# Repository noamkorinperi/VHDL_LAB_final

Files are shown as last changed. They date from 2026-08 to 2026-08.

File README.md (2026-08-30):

# VHDL_LAB_final

RV32IM single-cycle MCU implemented in VHDL for the Terasic DE10-Standard
FPGA board.

> ## ⚠️ לשותף לפרויקט: לפני אימות על הכרטיס
>
> יש לעבוד לפי
> **[חשוב — הוראות אימות פיזי על הכרטיס](חשוב_הוראות_אימות_פיזי_על_הכרטיס.md)**.
> השינויים בענף זה עדיין לא אומתו פיזית ואין להסתמך על תוצאות הכרטיס של
> `main`.

## Validation status of this branch

The forum-compliance changes pass the complete automated ModelSim regression,
Quartus Full Compilation, and fully constrained TimeQuest analysis.

**They have not yet been programmed onto or physically validated on a
DE10-Standard board.** The reset, compare, PWM, DIV and REM board results
recorded on `main` apply to the `main` image only and must not be treated as
physical evidence for this branch.

See `DOC/FORUM_COMPLIANCE_STATUS.md` for the forum-question audit and
`חשוב_הוראות_אימות_פיזי_על_הכרטיס.md` for the exact DE10-Standard physical
validation procedure and evidence gate.

## Project navigation

- `PROJECT_PLAN.md` — timestamped roadmap and current status.
- `DUT/RV32IMscMCU` — active VHDL implementation.
- `TB/RV32IMscMCU` — self-checking testbenches.
- `SIM/RV32IMscMCU` — ModelSim scripts and memory images.
- `Quartus/RV32IMscMCU` — Quartus project for Cyclone V.
- `DOC/MODELSIM_TESTS_STAGE0_TO_STAGE3.md` — test instructions.
- `DOC/MODELSIM_TESTS_STAGE4_TO_STAGE5.md` — current GUI test instructions.
- `DOC/PHYSICAL_LAB_TEST_STAGE5_5.md` — historical stage-5.5 smoke procedure.
- `חשוב_הוראות_אימות_פיזי_על_הכרטיס.md` — current branch physical
  validation procedure and evidence template.
- `DOC/MODELSIM_TESTS_STAGE6_TO_STAGE7.md` — interrupt test instructions.
- `DOC/MODELSIM_TESTS_STAGE8.md` — full benchmark matrix, assertions and IPC.
- `DOC/QUARTUS_FPGA_STAGE9.md` — final Quartus build and board procedure.
- `DOC/FORUM_COMPLIANCE_STATUS.md` — forum compliance matrix and branch gate.
- `SIM/RV32IMscMCU/run_stage8_full_verification.do` — unified stages 0–8
  system regression for all nine supplied applications.
- `Quartus/RV32IMscMCU/compile_stage9.cmd` — reproducible full FPGA build.
- `SIM/RV32IMscMCU/run_stage5_5_smoke_firmware.do` — retained stage-5.5
  regression for the earlier smoke firmware.
- `DOC/CPU_IMMEDIATE_DECODE_FIX_2026-08-13.md` — documented LUI/load decode fix.
- `Benchmark apps` — instructor-provided application benchmarks.

Generated Quartus and ModelSim artifacts are intentionally excluded through
`.gitignore`.

## Final Quartus build

The final timing-qualified FPGA implementation was compiled with Quartus Prime 21.1 using Fitter Seed = 2. The setting is stored in Quartus/RV32IMscMCU/RV32IMscMCU.qsf.

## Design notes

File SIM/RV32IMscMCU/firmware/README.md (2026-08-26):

# Stage 8 firmware compatibility copy

`interrupt_test1_ITCM_fixed.hex` is a one-word corrected copy of the instructor's
`Intrrupt-based IO/test1` ITCM image.  The supplied program uses `j STATE1` when
`SW0=0`, which skips `ori gp,gp,1` and therefore never enables interrupts in the
short ModelSim mode.

The word at ITCM word address `0x2F` was changed from `0x01C0006F`
(`j STATE1`) to `0x00C0006F` (jump to the interrupt-enable instruction).  Its
Intel HEX checksum changed accordingly from `9D` to `9E`.  The instructor's
benchmark directory is intentionally left unchanged.

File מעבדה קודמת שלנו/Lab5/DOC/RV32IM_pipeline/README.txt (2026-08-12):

# RV32IM Pipelined RISC-V Core

This repository contains a VHDL implementation of a **5-stage pipelined RISC-V processor** based on the RV32I datapath, with an added partial M-extension path for the `mul` instruction.  
The design is intended for simulation in ModelSim and synthesis/debug on an Intel/Altera FPGA using Quartus and SignalTap.

## Project Overview

The processor is organized as a classic 5-stage pipeline:

```text
IF  ->  ID  ->  EX  ->  MEM  ->  WB
```

Main features:

- 32-bit RISC-V datapath.
- 5-stage pipeline with dedicated pipeline registers.
- Instruction memory / data memory implemented using Intel/Altera `altsyncram`.
- Hazard handling using stall, flush, and forwarding logic.
- Branch and jump redirection support.
- Two-stage adapted multiplier for `mul`.
- Debug outputs for SignalTap, including PC/instruction taps for pipeline stages.
- FPGA top wrapper with board-level switch and LED mapping.

## Top-Level Entities

| Entity | File | Purpose |
|---|---|---|
| `RV32IM_pipeline_top` | `RV32IM_pipeline_top(1).vhd` | FPGA board-level wrapper around the pipelined core. Maps switches, LEDs, and debug outputs. |
| `RV32IM_PIPELINE_CORE` | `RV32IM_PIPELINE_CORE_start(3).vhd` | Main pipelined CPU core. Instantiates IF, ID, EX, MEM, WB stages and hazard units. |
| `Ifetch` | `IFETCH_pipeline(3).VHD` | Program counter logic and instruction memory interface. |
| `Idecode` | `IDECODE_pipeline(1).VHD` | Register file read/write and immediate generation. |
| `control` | `CONTROL(5).VHD` | Combinational instruction decoder and control-signal generator. |
| `Execute` | `EXECUTE(4).VHD` | ALU, branch comparison, and branch/jump target generation. |
| `dmemory` | `DMEMORY(6).VHD` | Data memory interface using `altsyncram`. |
| `IF_ID_REG` | `IF_ID_REG(2).vhd` | Pipeline register between IF and ID. |
| `ID_EX_REG` | `ID_EX_REG(2).vhd` | Pipeline register between ID and EX. |
| `EX_MEM_REG` | `EX_MEM_REG(2).vhd` | Pipeline register between EX and MEM. |
| `MEM_WB_REG` | `MEM_WB_REG(2).vhd` | Pipeline register between MEM and WB. |
| `forwarding_unit` | `forwarding_unit(4).vhd` | Resolves data hazards by selecting forwarded operands. |
| `stall_unit` | `stall_unit(7).vhd` | Inserts a one-cycle stall for load-use and mul-use hazards. |
| `pipeline_muxes` | `pipeline_muxes(3).vhd` | Forwarding muxes and write-back mux. |
| `Multiplier16_s1`, `Multiplier16_s2` | `Multiplier16_adapted_simple(2).vhd` | Two-stage multiplier implementation. |
| `PLL` | `PLL(5).vhd` | FPGA PLL used when running on hardware. |

## Packages

| Package | File | Purpose |
|---|---|---|
| `cond_compilation_package` | `cond_compilation_package(5).vhd` | Global configuration constants for simulation/FPGA mode, memory size, PC width, address width, and PLL parameters. |
| `const_package` | `const_package(5).vhd` | Instruction masks, opcode constants, ALU operation encodings, and shared datapath constants. |
| `aux_package` | `aux_package_pipeline(1).vhd` | Component declarations for the pipelined core and its submodules. Compile only this updated `aux_package`; do not compile an older `aux_package.vhd` in the same library. |

## Pipeline Architecture

### IF Stage

The IF stage is implemented by `Ifetch` and includes:

- Program counter register.
- Sequential PC update using `PC + 4`.
- Branch/jump target selection.
- PC hold support during stalls using `PCWrite_i`.
- Instruction memory access through `altsyncram`.

The next-PC priority is:

```text
reset -> jalr -> taken branch / jal -> stall hold -> PC + 4
```

### ID Stage

The ID stage contains:

- Register file with 32 registers.
- Source register decoding from the instruction.
- Immediate/sign-extension generation.
- Write-back input path from the WB stage.

The register file write-back is driven by:

```text
wb_rd_i, wb_write_data_i, wb_regwrite_i
```

### EX Stage

The EX stage contains:

- ALU operation execution.
- Branch comparison.
- Branch/jump target address generation.
- Stage 1 of the adapted multiplier.

ALU operation selection is controlled by `ALUOp_ctrl_o` from the control unit.

### MEM Stage

The MEM stage contains:

- Data memory read/write.
- Stage 2 of the adapted multiplier.
- Branch/jump resolution and pipeline flush generation.

Data memory address selection depends on `WORD_GRANULARITY`:

```text
WORD_GRANULARITY = true  -> use word address bits
WORD_GRANULARITY = false -> use byte address bits
```

### WB Stage

The WB stage chooses the value written back to the register file:

```text
jal/jalr   -> PC + 4
load       -> DTCM read data
mul        -> multiplier result
otherwise  -> ALU result
```

## Hazard Handling

### Forwarding

The `forwarding_unit` detects dependencies between the current EX-stage instruction and results from later stages.

Forwarding select encoding:

```text
00 -> use original ID/EX register data
10 -> forward from EX/MEM ALU result
01 -> forward from MEM/WB write-back result
11 -> unused / treated as original data
```

### Stalling

The `stall_unit` inserts a one-cycle interlock when the instruction in ID depends on a value that is not ready yet:

- Load-use hazard.
- Mul-use hazard.

When a stall is asserted:

```text
PCwrite_o   = 0
IFIDWrite_o = 0
Stall_o     = 1
```

### Flushing

A flush is generated after a taken branch or jump redirection. The design exposes `FHCNT_o`, a flush counter useful for debugging and performance inspection.

## Supported Instruction Groups

The control unit decodes the following RV32I-style instruction groups:

- Arithmetic and logical R-type instructions: `add`, `sub`, `and`, `or`, `xor`, `sll`, `srl`, `sra`, `slt`, `sltu`.
- Immediate arithmetic/logical instructions: `addi`, `andi`, `ori`, `xori`, `slli`, `srli`, `srai`, `slti`, `sltiu`.
- Upper-immediate instructions: `lui`, `auipc`.
- Branch instructions: `beq`, `bne`, `blt`, `bge`, `bltu`, `bgeu`.
- Jump instructions: `jal`, `jalr`.
- Load/store instructions: `lb`, `lh`, `lw`, `lbu`, `lhu`, `lwu`, `sb`, `sh`, `sw`.
- M-extension: `mul` through the adapted two-stage multiplier.

> Note: `const_package` contains constants for additional M-extension and system instructions, but the uploaded control/datapath currently wires the `mul` path only.

## Multiplier Implementation

The `mul` instruction is implemented using a two-stage adapted multiplier:

```text
Stage 1, EX stage:
    Four 8-bit partial multiplications
    P = {P3, P2, P1, P0}

Pipeline register:
    EX/MEM register stores the packed partial products

Stage 2, MEM stage:
    Adder tree combines the partial products
    RESULT = P0 + (P1 + P2 << 8) + (P3 << 16)
```

Because the multiplier result becomes available in MEM/WB, a directly dependent instruction after `mul` requires one stall, similar to a load-use hazard.

## Debug and SignalTap Outputs

The core exposes several useful debug outputs:

| Signal | Meaning |
|---|---|
| `pc_o` | Current IF-stage PC. |
| `instruction_o` | Current IF-stage instruction. |
| `IDpc_o`, `EXpc_o`, `MEMpc_o`, `WBpc_o` | PC value in each pipeline stage. |
| `IDinstruction_o`, `EXinstruction_o`, `MEMinstruction_o`, `WBinstruction_o` | Instruction value in each pipeline stage. |
| `STCNT_o` | Stall counter. |
| `FHCNT_o` | Flush counter. |
| `CLKCNT_o` / `mclk_cnt_o` | Main clock counter. |
| `STRIGGER_o` | SignalTap trigger when the IF PC matches the selected breakpoint address. |
| `BPADDR_i` | 8-bit breakpoint address input, normally driven by `SW[7:0]`. |

In the FPGA wrapper:

```text
SW[7:0]     -> BPADDR_i
LEDR[7:0]   -> low byte of stall counter
LEDR[8]     -> breakpoint trigger
LEDR[9]     -> flush activity indicator
```

## Build Configuration

The main configuration constants are located in `cond_compilation_package(5).vhd`.

Important parameters:

| Constant | Meaning |
|---|---|
| `G_MODELSIM` | `1` for ModelSim-style simulation, `0` for FPGA build. |
| `G_WORD_GRANULARITY` | Selects word-addressed or byte-addressed memory behavior. |
| `G_ADDRWIDTH` | ITCM/DTCM memory address width. |
| `G_DATA_WORDSNUM` | Number of memory words. |
| `G_PC_WIDTH` | Program counter width. |
| `G_MA_WIDTH` | Memory address width used by the datapath. |
| `G_PLL_DIV`, `G_PLL_MUL` | PLL configuration parameters used in FPGA mode. |

In the uploaded package, `G_MODELSIM` is set to `1`.  
For FPGA synthesis, set/override `MODELSIM = 0` so that the PLL path and FPGA reset polarity are used.

## Memory Initialization

Both instruction memory and data memory are initialized from `.hex` files:

- ITCM initialization is defined in `IFETCH_pipeline(3).VHD`.
- DTCM initialization is defined in `DMEMORY(6).VHD`.

The uploaded files currently contain absolute Windows paths, for example:

```text
C:\Users\ASUS\Desktop\Computers_LAB\Lab5\Material\Benchmark_Apps\test4\RV32IM\man_compiled\bin\M9K-intel\ITCM.hex
C:\Users\ASUS\Desktop\Computers_LAB\Lab5\Material\Benchmark_Apps\test4\RV32IM\man_compiled\bin\M9K-intel\DTCM.hex
```

Before running the project on another computer, update these paths or move the `.hex` files into the project directory and use relative paths.

## Suggested Compilation Order

A safe compilation order is:

```tcl
vlib work
vmap work work

vcom "cond_compilation_package(5).vhd"
vcom "const_package(5).vhd"
vcom "aux_package_pipeline(1).vhd"

vcom "PLL(5).vhd"
vcom "CONTROL(5).VHD"
vcom "IFETCH_pipeline(3).VHD"
vcom "IDECODE_pipeline(1).VHD"
vcom "EXECUTE(4).VHD"
vcom "DMEMORY(6).VHD"

vcom "IF_ID_REG(2).vhd"
vcom "ID_EX_REG(2).vhd"
vcom "EX_MEM_REG(2).vhd"
vcom "MEM_WB_REG(2).vhd"

vcom "forwarding_unit(4).vhd"
vcom "stall_unit(7).vhd"
vcom "pipeline_muxes(3).vhd"
vcom "Multiplier16_adapted_simple(2).vhd"

vcom "RV32IM_PIPELINE_CORE_start(3).vhd"
vcom "RV32IM_pipeline_top(1).vhd"
```

For ModelSim, make sure the Intel/Altera `altera_mf` simulation library is available because `IFETCH_pipeline` and `DMEMORY` instantiate `altsyncram`.

## FPGA Usage Notes

For FPGA implementation:

1. Set the top-level entity to:

```text
RV32IM_pipeline_top
```

2. Map board pins in the Quartus `.qsf` file:

```text
clk_i  -> CLOCK_50
rst_i  -> KEY0, active-low on the board wrapper comments
SW     -> SW7..SW0
LEDR   -> LEDR9..LEDR0
```

3. Use SignalTap to observe:

```text
pc_o, instruction_o,
IDpc_o, EXpc_o, MEMpc_o, WBpc_o,
IDinstruction_o, EXinstruction_o, MEMinstruction_o, WBinstruction_o,
STCNT_o, FHCNT_o, CLKCNT_o, STRIGGER_o
```

## Repository File List

```text
aux_package_pipeline(1).vhd
cond_compilation_package(5).vhd
const_package(5).vhd
CONTROL(5).VHD
DMEMORY(6).VHD
EX_MEM_REG(2).vhd
EXECUTE(4).VHD
forwarding_unit(4).vhd
ID_EX_REG(2).vhd
IDECODE_pipeline(1).VHD
IF_ID_REG(2).vhd
IFETCH_pipeline(3).VHD
MEM_WB_REG(2).vhd
Multiplier16_adapted_simple(2).vhd
pipeline_muxes(3).vhd
PLL(5).vhd
RV32IM_PIPELINE_CORE_start(3).vhd
RV32IM_pipeline_top(1).vhd
stall_unit(7).vhd
```

## Notes and Limitations

- This package does not include a testbench file.
- The design depends on Intel/Altera `altsyncram`, so pure generic VHDL simulators may require vendor libraries or memory-model replacements.
- The uploaded memory initialization paths are machine-specific and should be changed before reuse.
- The M-extension datapath currently supports the uploaded `mul` implementation. Other M-extension constants exist in the package but are not fully integrated in the current control/datapath.
- File names contain copy suffixes such as `(1)`, `(2)`, etc. The VHDL entity names are unaffected, but for a clean repository it is recommended to rename files to stable names without copy suffixes.

## Recommended Clean File Names

For a cleaner Git repository, the files can be renamed as follows:

```text
aux_package_pipeline.vhd
cond_compilation_package.vhd
const_package.vhd
CONTROL.vhd
DMEMORY.vhd
EX_MEM_REG.vhd
EXECUTE.vhd
forwarding_unit.vhd
ID_EX_REG.vhd
IDECODE_pipeline.vhd
IF_ID_REG.vhd
IFETCH_pipeline.vhd
MEM_WB_REG.vhd
Multiplier16_adapted_simple.vhd
pipeline_muxes.vhd
PLL.vhd
RV32IM_PIPELINE_CORE.vhd
RV32IM_pipeline_top.vhd
stall_unit.vhd
```

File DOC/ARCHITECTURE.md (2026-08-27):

# RV32IMscMCU - Architecture Specification

Status: forum-compliance RTL and automated verification complete, 27.08.2026 IDT.
Physical DE10-Standard validation is still pending for these changes.

Target: Terasic DE10-Standard, Cyclone V SX SoC `5CSXFC6D6F31C6N`.

## Scope

The mandatory design is a structural single-cycle RV32IM MCU.  Pipeline and
UART remain outside the active scope.  The original lab and instructor folders
are immutable references; implementation work is contained in `DUT`, `TB`,
`SIM`, `DOC`, and `Quartus`.

## Top-level architecture

```mermaid
flowchart LR
    CLOCK["CLOCK_50 / KEY0"] --> CRU["Clock + Reset Unit"]
    CRU --> CPU["RV32IM Single-Cycle CPU"]
    CRU --> DIV["32-bit Divider"]
    CPU --> ITCM["ITCM"]
    CPU <--> BUS["32-bit Data Bus"]
    BUS <--> DTCM["DTCM"]
    BUS <--> PERIPH["MMIO Peripheral Mux"]
    PERIPH <--> GPIO["LEDR / HEX / SW"]
    PERIPH <--> PB["Hardware-debounced KEY1-KEY3"]
    PERIPH <--> TIMER["Basic Timer / PWM / Capture"]
    BUS <--> INTC["Interrupt Controller"]
    CPU <--> DIV
    PB --> INTC
    TIMER --> INTC
    INTC -->|"INTR / INTA / TYPE"| CPU
```

The final MCU entity is `RV32IMscMCU`, and both it and the CPU core remain
structural. The CPU exposes one data bus to `mcu_interconnect`; the interconnect
routes DTCM accesses locally and forwards MMIO accesses to `mcu_peripherals`.

## Data-bus contract

The CPU is the only bus master.

| Signal | Width | Direction from CPU | Meaning |
|---|---:|---|---|
| `dbus_addr` | 32 | output | Full byte address; low bits must never be discarded before MMIO decode |
| `DATA BUS` | 32 | bidirectional | CPU write data; DTCM/MMIO read data; TYPE during INTA; non-owners drive `Z` |
| `dbus_read` | 1 | output | Valid load transaction |
| `dbus_write` | 1 | output | Valid store transaction |

Rules:

1. DTCM is selected for byte addresses `0x00000000-0x00001FFF`.
2. MMIO is selected for byte addresses `0x00002000-0x00003FFF`.
3. DTCM receives word index `dbus_addr(12 downto 2)` only after selection.
4. MMIO decode uses the complete address, including bits 1:0.  This is required
   for `HEX0/HEX1`, `HEX2/HEX3`, `HEX4/HEX5`, and `IE/IFG/TYPE`.
5. Provided applications use `lw/sw` even for byte-resolution registers.  MMIO
   writes consume the low byte and reads return zero-extended values.
6. Exactly one source owns the shared DATA BUS; every non-owner drives high impedance.
7. During `INTA`, the interrupt controller drives zero-extended `TYPE` onto DATA BUS.
8. A write may target either DTCM or one peripheral, never both.

## Address map

The canonical VHDL constants are in `mcu_memory_map_pkg.vhd`.

| Region/register | Address | Access |
|---|---:|---|
| DTCM word bases | `0x0000-0x1FFC` | R/W word |
| MMIO region | `0x2000-0x3FFF` | decoded |
| `PORT_LEDR` | `0x2000` | low byte R/W |
| `PORT_HEX0` | `0x2004` | low byte R/W |
| `PORT_HEX1` | `0x2005` | low byte R/W |
| `PORT_HEX2` | `0x2008` | low byte R/W |
| `PORT_HEX3` | `0x2009` | low byte R/W |
| `PORT_HEX4` | `0x200C` | low byte R/W |
| `PORT_HEX5` | `0x200D` | low byte R/W |
| `PORT_SW` | `0x2010` | low byte R |
| `PORT_PB` | `0x2014` | low byte R |
| UART reserved | `0x2018-0x201A` | bonus, inactive |
| `BTCTL1` | `0x201C` | low byte R/W |
| `BTCTL2` | `0x201D` | low byte R/W |
| `BTCMPR0` | `0x2020` | word R/W |
| `BTCMPR1` | `0x2024` | word R/W |
| `BTCAPR` | `0x2028` | word R/W |
| `IE` | `0x202C` | low byte R/W |
| `IFG` | `0x202D` | low byte R/W1C/software clear as defined per source |
| `TYPE` | `0x202E` | low byte R |

## Clock plan

| Domain | Source | Purpose |
|---|---|---|
| `CLOCK_50` | DE10-Standard 50 MHz oscillator | Board reference clock |
| `MCLK` | dedicated Cyclone V PLL instance, 20 MHz | CPU and DTCM |
| `SMCLK` | dedicated Cyclone V PLL instance, 20 MHz | GPIO, timer and interrupt controller |
| `DIVCLK` | dedicated Cyclone V PLL instance, 50 MHz | Divider's 32-cycle iterative datapath |

`RV32IMscMCU.vhd` instantiates three generic `PLL.vhd` wrappers. MCLK and SMCLK
use 2/5 and DIVCLK uses 1/1. Quartus may share phase-identical MCLK/SMCLK
physical clock resources, but the required three logical PLL instances remain
explicit. The MCLK/DIVCLK crossing uses the request/completion toggle handshake.

No fabric-generated clock may be used as a clock input.  Clock selection in the
timer will use clock-enable pulses inside the `sysclk` domain.

## Reset plan

- `KEY0` is the external active-low system reset.
- Internal reset is active-high.
- Assertion may be asynchronous; deassertion must be synchronized separately
  into `sysclk` and `DIVCLK` using two flip-flops.
- The final reset remains asserted until all three Cyclone V PLL instances report lock.
- KEY1-KEY3 are data/interrupt inputs and never participate in system reset.
- The current wrapper asserts reset while KEY0 is pressed or the PLL is not
  locked. Synchronized reset deassertion will be reviewed before stage-5.5
  physical programming.

## Divider handshake and CDC

The CPU launches one request with stable operands and operation metadata.  The
request is converted to a toggle or otherwise lossless handshake in `DIVCLK`.
The divider captures operands once, asserts busy for 32 iterations, registers
quotient/remainder, and returns a synchronized completion event.  The CPU holds
architectural state while busy and performs exactly one write-back after done.
Every multi-bit transfer is held stable for the duration of its handshake; only
single-bit control events pass through two-flop synchronizers.

## Interrupt interface

| Signal | Producer | Consumer | Meaning |
|---|---|---|---|
| `INTR` | interrupt controller | CPU | At least one enabled pending source exists while GIE is set |
| `INTA` | CPU | interrupt controller | CPU is accepting the selected source |
| `TYPE[7:0]` | interrupt controller | CPU data bus | Vector-table byte offset for the highest-priority source |

Priority without UART is RESET, Basic Timer, KEY1, KEY2, KEY3.  UART vector
positions remain reserved.  CPU entry is a two-cycle FSM: capture TYPE and clear
GIE in cycle 1, then store `PC+4` in `tp` and jump through the vector table in
cycle 2.  `jalr zero, 0(tp)` acts as `reti` and restores GIE.

## Planned source boundaries

| Unit | Responsibility |
|---|---|
| `RV32IMscMCU.vhd` | Structural board/MCU top-level only |
| `RV32I_CORE.vhd` | CPU structure and later interrupt/divider stall integration |
| `mcu_memory_map_pkg.vhd` | Canonical addresses and interrupt TYPE values |
| `mcu_interconnect.vhd` | Shared tri-state DATA BUS ownership and DTCM/MMIO selection |
| `gpio_peripheral.vhd` | LED/HEX/SW registers and seven-segment encoding, phase 2 |
| `divider.vhd` | Iterative unsigned core, phase 3 |
| `PLL.vhd` | Generic Cyclone V PLL wrapper and lock indication |
| `basic_timer.vhd` | Timer, compare, PWM and capture, phase 4 |
| `pushbutton_unit.vhd` | Direct board-key state and release-edge event detection |
| `interrupt_controller.vhd` | IE, IFG, TYPE and priority, phase 6 |

## Stage 4–5 implementation

`mcu_peripherals.vhd` is the single MMIO responder connected to the existing
interconnect. It instantiates GPIO, Basic Timer and pushbuttons, then selects one
read value and one `hit` response. This preserves the original CPU bus and the
stage-0–3 simulation harness interface.

The Basic Timer implements `BTCTL1`, `BTCTL2`, `BTCMPR0`, `BTCMPR1` and
read/write `BTCAPR`. `BTCNT` is internal and is exposed only as a debug signal.
Clock selections `/1`, `/2`, `/4` and `/8` are clock-enable pulses in the
`sysclk` domain. Compare 0 resets the up-counter, compare 1 changes PWM duty,
and synchronized capture inputs can latch rising or falling edges. Timer and
button events are one-`sysclk` pulses prepared for the stage-6 controller.

The pushbutton unit treats the board keys as active-low and relies on the
DE10-Standard's hardware Schmitt-trigger/debounce path, as clarified by the
instructor. It adds no software debounce or two-flop key synchronizer. A single
event is emitted on the hardware-debounced release transition (`0` to `1`).
`PORT_PB[2:0]` returns active-high pressed states for KEY1, KEY2 and KEY3.

### Board-observation mapping prepared for stage 5.5

| Board signal | Current function |
|---|---|
| `KEY0` | active-low system reset |
| `KEY1`, `KEY2`, `KEY3` | hardware-debounced pushbuttons / interrupt sources; event on release |
| `SW[7:0]` | GPIO switch port |
| `SW8` | timer `CAPIN1` |
| `SW9` | timer `CAPIN2` |
| `LEDR[7:0]` | GPIO LED register |
| `LEDR8` | direct PWM observation |
| `LEDR9` | high while any hardware-debounced key is pressed |

Physical pin assignments and the dedicated smoke-test firmware remain gated on
the user's ModelSim GUI evidence and belong to stage 5.5.

## Foundation decisions

1. Existing reference folders are read-only.
2. `RV32IMscMCU` is the stable final top-level entity name.
3. The 32-bit address is byte-based throughout the interconnect.
4. DTCM word addressing occurs only at the RAM boundary.
5. UART addresses and vector slots are reserved but inactive.
6. The pipeline implementation is not compiled into the mandatory design.
7. ModelSim and Quartus gates are tracked with timestamped evidence in
   `PROJECT_PLAN.md`.

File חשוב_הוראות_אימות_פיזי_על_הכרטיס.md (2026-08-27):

# חשוב: הוראות אימות פיזי על הכרטיס — ענף forum-compliance

עודכן: 27.08.2026 IDT

מסמך זה הוא נוהל הקבלה הפיזי עבור הענף `codex/forum-compliance` על כרטיס
DE10-Standard. עד שכל סעיפי החובה שלהלן עוברים ומתועדים, הענף נשאר במצב
**טרם אומת פיזית**. תוצאות שנאספו בעבר מ־`main` אינן תחליף להרצה זו.

## 1. ציוד ותנאי פתיחה

- כרטיס Terasic DE10-Standard וספק הכוח שלו.
- כבל USB-Blaster תקין.
- Quartus Prime Lite 21.1.
- סביבת העבודה על הענף `codex/forum-compliance` וללא שינויי RTL מקומיים לא
  מתועדים.
- מומלץ: טלפון לצילום וידאו; oscilloscope או logic analyzer לבדיקת PWM.

אין לחבר probe לנקודה שאינה מיועדת למדידה. בדיקת LEDR8 בעין מספיקה למעבר
הבסיסי; מדידת oscilloscope היא ראיה משופרת.

## 2. רישום גרסה ובניית SOF חדש

משורש המאגר הרץ:

```text
git switch codex/forum-compliance
git pull --ff-only
git status --short --branch
git rev-parse HEAD
```

רשום בדוח הבדיקה את ה־commit המלא. `git status` צריך להראות שאין שינוי בקבצי
הפרויקט; קבצים מקומיים לא־עקובים שאינם חלק מהבנייה מותרים, אך יש לרשום אותם.

מתוך `Quartus/RV32IMscMCU` הרץ:

```text
compile_stage9.cmd
verify_timing_stage9.cmd
```

תנאי מעבר לפני צריבה:

1. `Quartus Prime Full Compilation was successful` ו־0 errors.
2. `Timing Analyzer was successful` ו־0 errors.
3. התכן fully constrained ל־setup ול־hold, וכל ערכי ה־slack הגרועים חיוביים.
4. נוצר קובץ חדש:

   ```text
   Quartus/RV32IMscMCU/output_files/RV32IMscMCU.sof
   ```

ה־SOF משתמש בקושחת `interrupt/test4` המוגדרת ב־top-level. אין להשתמש ב־SOF
ישן מתיקייה אחרת. ערכי utilization או slack עשויים להשתנות מעט בין build
seeds; קריטריון המעבר הוא שאין שגיאות או הפרות תזמון.

## 3. צריבה לכרטיס

1. כבה את הכרטיס, חבר ספק וכבל USB-Blaster, והדלק אותו.
2. פתח את `Quartus/RV32IMscMCU/RV32IMscMCU.qpf`.
3. פתח `Tools > Programmer`.
4. ב־`Hardware Setup` בחר `DE-SoC [USB-1]` או את מופע USB-Blaster של
   הכרטיס.
5. אם שרשרת JTAG מציגה יותר מרכיב אחד, חבר את ה־SOF לשורת ה־FPGA
   `5CSXFC6D6F31C6` (בדרך כלל רכיב 2). אין לתכנת את ה־HPS או flash.
6. הוסף את `output_files/RV32IMscMCU.sof`, סמן `Program/Configure` ולחץ
   `Start`.
7. ודא שההתקדמות מגיעה ל־100% ללא error ושמור צילום של חלון Programmer.

קבע את `SW9:0` לאפס לפני תחילת רצף הבדיקות. הכפתורים פעילים־נמוך פיזית:
`KEY0` הוא reset; ‏`KEY1`–`KEY3` נקראים כמצב לחוץ פעיל־גבוה בתוך ה־MCU.
פעולת הפסיקה של `KEY1`–`KEY3` מתרחשת **בשחרור** הכפתור. בזמן הלחיצה
`LEDR9` דולק, ובשחרור הוא כבה.

## 4. בדיקת אתחול ו־KEY0/reset

1. מיד לאחר הצריבה ודא שכל ששת צגי HEX מציגים `0` ושהתכן אינו תקוע במצב
   לא ידוע.
2. לחץ ושחרר `KEY1` פעם אחת. רק לאחר השחרור הספירה על HEX צריכה להתחיל.
3. לחץ והחזק `KEY0`: הספירה חייבת להיעצר ויציאות ה־GPIO/HEX לחזור לערכי
   reset.
4. שחרר `KEY0` והמתן לנעילת ה־PLL. התוכנה צריכה לעלות מחדש למצב idle עם
   HEX מאופס; הספירה אינה אמורה להתחדש לפני שחרור חדש של `KEY1`.
5. שחרר `KEY1` שוב ואמת שהספירה חוזרת. כשל באתחול מחדש, יציאות `X`/הבהוב
   קבוע או צורך במחזור מתח הם FAIL.

## 5. בדיקת KEY1 ופסיקות compare

לחץ `KEY0` ושחרר כדי להתחיל ממצב ידוע. בצע ארבע לחיצות `KEY1` נפרדות:

1. בכל לחיצה החזק את `KEY1` כחצי שנייה. `LEDR9` צריך לדלוק בזמן ההחזקה,
   והפעולה החדשה אינה אמורה להתחיל לפני השחרור.
2. שחרר את `KEY1`; ‏`LEDR9` צריך לכבות והמונה המוצג ב־HEX צריך להתקדם.
3. מדוד לפחות ארבעה מרווחים בין עדכוני HEX בכל מצב.
4. ארבעת השחרורים צריכים לעבור במחזור בין תקופות compare של בקירוב
   `1.0 s`, ‏`0.5 s`, ‏`0.25 s` ו־`0.125 s` ולחזור על עצמן. סדר נקודת
   הכניסה למחזור תלוי בערך המצב, ולכן תנאי הקבלה הוא הופעת כל ארבע התקופות
   במחזור יציב — לא תקופה ראשונה מסוימת.
5. ודא שכל שחרור משנה מצב פעם אחת בלבד. קפיצה על פני מצב או מספר אירועים
   עבור שחרור יחיד היא FAIL.

בדיקה זו מאמתת מקצה לקצה את קלט KEY1, ‏IE/IFG, ‏TYPE בזמן INTA, חזרה מ־ISR,
ה־Basic Timer והכתיבה לכל זוגות ה־HEX.

## 6. בדיקת KEY2 ו־PWM

לחץ `KEY0` ושחרר, ואז בצע ארבע לחיצות `KEY2` נפרדות:

1. בכל לחיצה ודא ש־`LEDR9` דולק בזמן ההחזקה ושהמעבר מתבצע בשחרור.
2. לאחר השחרור הראשון הספירה ב־HEX נעצרת ו־PWM מופיע ב־`LEDR8`.
3. שחרורים חוזרים של `KEY2` צריכים לשנות את בהירות `LEDR8`; לאחר reset
   רצף ה־duty המתוכנת הוא בקירוב 50%, ‏25%, ‏12.5% ו־6.25%.
4. ודא שאין קיפאון ושכל שחרור מתקבל פעם אחת.
5. אם קיים oscilloscope/logic analyzer, מדוד על יציאת `LEDR8` תדר של
   כ־5 kHz (מחזור כ־200 us), ותעד לפחות שני ערכי duty שונים.
6. לחץ ושחרר `KEY0`; ‏PWM חייב להיפסק והמערכת לחזור ל־idle.

## 7. בדיקת KEY3, ‏REM ו־DIV

קושחת `test4` מודדת זמן ריצה בזיכרון ואינה מציגה את תוצאות המערכים על LED
או HEX. לכן בדיקת הכרטיס מאמתת completion וחזרה תקינה מהפסיקות; נכונות כל
התוצאות המספריות מכוסה ברגרסיית ModelSim.

1. לחץ `KEY0` ושחרר.
2. לחץ והחזק `KEY3`; ודא ש־`LEDR9` דולק. בשחרור הראשון מתחיל מסלול REM.
3. המתן שנייה וודא שהמערכת נשארת מגיבה.
4. לחץ ושחרר `KEY3` פעם שנייה. השחרור השני מפעיל את מסלול DIV.
5. המתן שנייה, ואז לחץ ושחרר `KEY1`. הספירה על HEX חייבת להתחיל ולהמשיך;
   זה מוכיח ששני מסלולי המחלק הסתיימו, ה־ISR חזר וה־CPU לא נשאר ב־stall.
6. חזור על הרצף לאחר reset לפחות פעם נוספת.

אם `KEY1` אינו מפעיל ספירה אחרי שני שחרורי `KEY3`, או שרק מחזור מתח מחזיר
את המערכת, הבדיקה היא FAIL.

## 8. בדיקת רצף משולב

לאחר reset יחיד בצע ללא צריבה מחדש:

```text
KEY1 release -> המתן לשני עדכוני HEX
KEY2 release -> אמת PWM ב-LEDR8
KEY3 release -> המתן
KEY3 release -> המתן
KEY1 release -> אמת שהספירה חוזרת
KEY0 release -> אמת חזרה ל-idle
```

צלם וידאו רציף של הרצף. מטרתו לגלות בעיות state, ‏IFG ישן או חזרה לא תקינה
מ־DIV/REM שאינן נראות כאשר כל תרחיש נבדק בנפרד.

## 9. מה הבדיקה הפיזית אינה מוכיחה לבדה

הבדיקות לעיל נותנות ראיה פיזית להתנהגות החיצונית ולמסלול הפסיקות המלא, אך
אין להסיק מהן לבדן את כל הפרטים הפנימיים:

- שלושת מופעי ה־PLL הלוגיים ומבנה ה־clock domains נבדקים בדוח הסינתזה;
  ה־Fitter רשאי לשתף משאב פיזי עבור MCLK ו־SMCLK הזהים.
- בעלות `Z` על ה־DATA BUS הפנימי הופכת למרבב בתוך ה־FPGA ונבדקת ב־RTL
  ובבדיקת interconnect, לא באמצעות probe חיצוני.
- כתיבה/קריאה של `BTCAPR`, ארבעת ביטי ה־read-only של `BTCTL2`, ניקוי IFG
  כאשר IE כבוי, וסדר retirement של פסיקה שמגיעה באמצע DIV מכוסים בבדיקות
  ModelSim ייעודיות. כדי לטעון שגם הם נבדקו פיזית נדרשת קושחת diagnostic
  נפרדת שמציגה PASS/FAIL על LED/HEX או capture מתאים ב־SignalTap.

אין לסמן את הבדיקות הפנימיות כ־"אומתו פיזית" רק משום שהדגמת `test4` עברה.

## 10. ראיות ודוח תוצאה

צור תיקייה שאינה מחליפה ראיות קודמות, לדוגמה:

```text
DOC/evidence/forum-compliance-YYYYMMDD-HHMM/
```

שמור בה:

1. `validation.txt` לפי התבנית הבאה.
2. צילום Programmer ב־100%.
3. צילום/וידאו reset ואתחול מחדש.
4. וידאו KEY1 המציג ארבעה קצבים.
5. צילום/וידאו KEY2; ואם קיים, צילום scope עם frequency ו־duty.
6. וידאו רצף KEY3, ‏KEY3, ‏KEY1 והמשך ספירה.
7. צילום או קובץ של תוצאות Quartus ו־TimeQuest.

```text
Board: DE10-Standard
Date/time/timezone:
Tester:
Git commit:
Quartus version:
USB-Blaster identifier:
SOF path and build time:

Build + timing: PASS / FAIL
Program 100%: PASS / FAIL
KEY0/reset: PASS / FAIL
KEY1/release + four compare periods: PASS / FAIL
KEY2/PWM: PASS / FAIL
KEY3 REM/DIV + recovery: PASS / FAIL
Combined sequence: PASS / FAIL
Scope measurement (optional): frequency=____ duty=____
Notes:
Overall: PASS / FAIL
```

## 11. שער קבלה

האימות הפיזי של הענף עובר רק כאשר כל שבעת סעיפי החובה בתבנית הם PASS,
ה־commit תואם לענף המרוחק, וכל הראיות נשמרו. לאחר מכן יש לעדכן את
`README.md`, ‏`DOC/FORUM_COMPLIANCE_STATUS.md` ו־`PROJECT_PLAN.md` עם
תאריך, commit, שם הבודק וקישור לראיות. אם סעיף אחד נכשל, משאירים את אזהרת
"טרם אומת פיזית" ומתעדים את הצעד הראשון שבו ההתנהגות סטתה מהצפוי.

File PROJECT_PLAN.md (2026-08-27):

# תוכנית עבודה ומעקב - RV32IM MCU על DE10-Standard

עודכן לאחרונה: 27.08.2026 IDT - התאמות פורום; אימות פיזי לענף החדש ממתין

מסמך זה הוא מקור המעקב השוטף של הפרויקט. מעדכנים אותו בכל מעבר שלב, לאחר בדיקה שעברה, וכאשר מתגלה חסם או שינוי בדרישות.

## תמונת מצב נוכחית

| נושא | מצב |
|---|---|
| כרטיס יעד | DE10-Standard |
| ארכיטקטורת חובה | RV32IM single-cycle MCU |
| זמן עדכון אחרון | 27.08.2026 IDT |
| שלב נוכחי | התאמות forum-compliance הושלמו אוטומטית; אימות כרטיס ממתין |
| הושלם | רגרסיית 9/9, בדיקת פסיקה באמצע DIV, Quartus Full Compilation ו־TimeQuest fully constrained |
| הפעולה הבאה | לצרוב את SOF מהענף ולחזור על בדיקות reset, compare, PWM, DIV ו־REM |
| חסם נוכחי | אין גישה פיזית לכרטיס במהלך הכנת הענף |
| Quartus | 0 errors; TimeQuest 0 warnings; worst setup ‏+0.474 ns ו־worst hold ‏+0.160 ns |
| בונוסים | Pipeline ו-UART מוקפאים עד השלמת כל דרישות החובה |

### מקרא מצבים וחותמות זמן

- `[x | DD.MM.YYYY HH:MM IDT]` הושלם ונבדק בזמן המצוין.
- `[x | אומת DD.MM.YYYY HH:MM IDT]` בוצע קודם, אך זהו זמן האימות הראשון המתועד.
- `[~ | DD.MM.YYYY HH:MM IDT]` התחיל או עודכן כעת.
- `[ ]` טרם התחיל.
- `[! | DD.MM.YYYY HH:MM IDT]` חסום, נדחה או דורש החלטה מאז הזמן המצוין.
- `[- | DD.MM.YYYY HH:MM IDT]` מחוץ להיקף הפעיל מאז הזמן המצוין.

כל שינוי עתידי בסטטוס חייב לכלול תאריך, שעה ואזור זמן. אין לשכתב חותמת
היסטורית: שינוי נוסף מקבל חותמת חדשה ונרשם גם ביומן הביצוע.

## מפת הדרך

| שלב | חבילת עבודה | תוצר מרכזי | מצב |
|---:|---|---|---|
| 0 | סביבת עבודה ו-baseline | ליבת RV32IM הקיימת עוברת ModelSim | `[x | 13.08.2026 14:00 IDT]` |
| 1 | ארכיטקטורת MCU | Top-Level, מפת כתובות וממשקי bus מוגדרים | `[x | 12.08.2026 20:44 IDT]` |
| 2 | GPIO ממופה זיכרון | LEDs, HEX ו-switches עובדים ב-ModelSim | `[x | 13.08.2026 15:04 IDT]` |
| 3 | Divider Accelerator | `DIV/REM` וה-handshake עוברים בדיקות | `[x | 17.08.2026 21:48 IDT]` |
| 4 | Basic Timer | counter, compare, PWM ו-capture עובדים | `[x | 17.08.2026 22:21 IDT]` |
| 5 | Pushbuttons | KEY1-KEY3 מסונכרנים, עוברים debounce ומייצרים אירוע יחיד | `[x | 17.08.2026 22:21 IDT]` |
| 5.5 | בדיקת חומרה מוקדמת | KEY1-KEY3 ו-PWM מודגמים פיזית על DE10-Standard | `[x | 26.08.2026 19:30 IDT]` |
| 6 | Interrupt Controller | IE, IFG, TYPE ותעדוף עובדים | `[x | 26.08.2026 19:30 IDT]` |
| 7 | פסיקות בתוך ה-CPU | כניסה ל-ISR וחזרה ממנו עובדות לפי הפרוטוקול | `[x | 26.08.2026 19:30 IDT]` |
| 8 | אינטגרציה ואימות מלא | benchmarks עוברים מול RARS | `[x | 25.08.2026 22:18 IDT]` |
| 9 | Quartus ו-DE10-Standard | קומפילציה, pin assignment וקובץ SOF | `[x | 26.08.2026 19:30 IDT]` |
| 10 | SignalTap ו-PPA | הוכחת FPGA ודוחות Area/Fmax/Power | `[ ]` |
| 11 | דוח והגשה | `Final_report.pdf` ו-ZIP נקיים לפי המבנה הנדרש | `[ ]` |

---

## יומן ביצוע ושינויים בפועל

### 27.08.2026 IDT - התאמות לפי שאלות ותשובות הפורום

- נוספו שלושה מופעי PLL לוגיים נפרדים: MCLK, SMCLK ו־DIVCLK.
- ה־interconnect הוסב ל־DATA BUS דו־כיווני עם `Z`; ‏TYPE נוהג עליו בזמן INTA.
- אירועי KEY נוצרים בשחרור ללא debounce/synchronizer נוסף, בהתאם להבהרת המדריך.
- IFG נוצר רק כאשר IE פעיל ומתנקה בביטול IE; ‏BTCAPR הוא R/W; בחירת HEX משתמשת ב־A0.
- נוספה בדיקת קבלה לפסיקה שמגיעה באמצע DIV ומאמתת retirement לפני INTA.
- ModelSim, Quartus ו־TimeQuest עברו. השינויים **טרם עברו אימות פיזי**;
  הראיות הפיזיות מ־26.08.2026 שייכות ל־`main` בלבד.

### 26.08.2026 20:02 IDT - אימות release לפני העלאה ל־GitHub

- כל 14 סקריפטי ModelSim של שלבים 0–8 הורצו מחדש ועברו עם סמן PASS ייעודי,
  ללא Failure, ‏Fatal או שגיאת קומפילציה.
- רגרסיית שלב 8 עברה 9/9 benchmarks, כולל רצפי הטיימר המתוקנים ב־test4.
- Full Compilation חדש של שלב 9 עבר עם 0 errors והפיק SOF; בכל ארבע פינות
  TimeQuest התקבל slack חיובי, עם worst setup ‏+2.664 ns ו־worst hold ‏+0.143 ns.
- כל קובצי Intel HEX עברו בדיקת checksum, ולא נמצאו סודות או קבצים גדולים
  חריגים בתוכן המיועד ל־commit.

### 26.08.2026 19:30 IDT - אימות פיזי מלא לשלב 9

- רגרסיית ModelSim המלאה עברה 9/9, כולל רצפי KEY1/KEY2/KEY3 והפעלה מחדש
  של compare mode אחרי מדידות capture.
- תוקנה קושחת הכרטיס כך ש־`BTCLR` נכתב במעבר ל־PWM ובהפעלה מחדש של compare;
  בכך נמנע קיפאון כאשר `BTCNT` כבר עבר את ערך ההשוואה החדש.
- Full Compilation עבר עם 0 errors; worst setup slack ‏+2.664 ns ו־worst hold
  slack ‏+0.143 ns.
- ה־SOF נטען בהצלחה לרכיב FPGA מספר 2 בשרשרת `DE-SoC [USB-1]`.
- `KEY0` reset, ‏`KEY1` compare/count, ‏`KEY2` PWM ו־`KEY3` REM/DIV עברו
  בדיקה פיזית. לאחר שתי לחיצות KEY3 הספירה חזרה בקצב 0.125 שנייה ללא קיפאון.

### 17.08.2026 23:07 IDT - רגרסיה מלאה לאחר שלבים 6–7

- הורצו ברצף כל 13 ה-scripts משלבים 0–7, כולל בדיקת קושחת 5.5.
- התקבלו 13 סמני PASS, ללא `Failure`, ללא שגיאת macro וללא שגיאת קומפילציה.
- בכך אומת שהוספת בקר הפסיקות ו-FSM הכניסה/חזרה לא שברה את ה-baseline,
  GPIO, המחלק, הטיימר או הכפתורים.

### 17.08.2026 23:06 IDT - preflight לקושחת שלב 5.5

- נוסף `tb_stage5_5_smoke_firmware.vhd` שמריץ בסימולציה את אותו קובץ
  `ITCM_stage5_5.hex` ששובץ ב-SOF.
- הבדיקה מאמתת שהקושחה מציגה `C` ב-HEX0, מעבירה את KEY1-KEY3 אל
  LEDR2:0 ומייצרת מעבר PWM לאחר סף `BTCMPR1`.
- נוסף `run_stage5_5_smoke_firmware.do` עם Wave/List, והתקבל
  `STAGE 5.5 SMOKE FIRMWARE PASS`.
- שלב 5.5 נשאר במצב `~`: ה-preflight עבר, אך שער היציאה דורש עדיין צריבה
  ובדיקה על כרטיס DE10-Standard אמיתי.

### 17.08.2026 22:58 IDT - הכנת שלב 5.5 ושלבים 6–7

- הושלמו pin assignments מלאים ל-DE10-Standard ונוספה תוכנת smoke-test
  שמציגה `C` ב-HEX0, מציגה את KEY1-KEY3 ב-LEDR2:0 ומפעילה PWM ב-LEDR8.
- נכתב `DOC/PHYSICAL_LAB_TEST_STAGE5_5.md` עם סדר צריבה, תרחישי reset,
  כפתורים, PWM ורשימת הראיות שיש לשמור.
- Full Compilation הושלם: Map, Fitter ו-Assembler עברו עם 0 errors והופק
  `RV32IMscMCU.sof`.
- בדיקת timing ראשונה ב-25 MHz חשפה setup slack שלילי של ‎-1.370 ns במסלול
  החצי-מחזור אל DTCM. שעון הליבה עודכן ל-20 MHz, בהתאם לקבועי הזמן של
  benchmarks המרצה, ו-debounce עודכן ל-200,000 מחזורים כדי לשמור 10 ms.
- לאחר התיקון כל בדיקות setup/hold עברו; ה-worst setup slack הוא ‎+2.631 ns.
- מומש `interrupt_controller.vhd` עם IE/IFG/TYPE, mask, priority, clear
  אוטומטי לטיימר ו-clear תוכנתי לכפתורים; unit test של שלב 6 עבר.
- נוספה לליבה כניסת פסיקה בשני מחזורים, GIE ב-`gp[0]`, שמירת כתובת החזרה
  ב-`tp`, קפיצה דרך vector table ו-`reti`; benchmark `test2` עם שלושת
  הכפתורים עבר בבדיקת האינטגרציה של שלב 7.
- נכתב `DOC/MODELSIM_TESTS_STAGE6_TO_STAGE7.md`; שלבים 6–7 נשארים במצב `~`
  עד להרצת GUI ושמירת Wave/List/צילום מסך.

### 17.08.2026 22:21 IDT - סגירת שלבים 4–5

- המשתמש דיווח שכל שלוש בדיקות ה-GUI עברו בהצלחה.
- נשמרו צילום מסך, Wave ו-List עבור Basic Timer, Pushbuttons ואינטגרציית
  peripheral/MMIO בתיקיות הראיות המתאימות.
- שלבים 4 ו-5 סומנו `x`; ניתן לעבור לבדיקת החומרה המוקדמת 5.5.

### 17.08.2026 22:13 IDT - אימות סופי לפני checkpoint

- הורצו מחדש על קוד המסירה המדויק כל עשרת scripts של שלבים 0–5.
- התקבלו עשרה סמני PASS, ללא `Failure`, ללא שגיאת קומפילציה וללא כשל assertion.
- `git diff --check` עבר; קובצי העזר הזמניים של קריאת ה-PDF הוסרו ואינם חלק
  מהמאגר.

### 17.08.2026 22:09 IDT - שלבים 4–5 מוכנים לבדיקת GUI

- מומש `basic_timer.vhd` עם BTCTL1/BTCTL2, מונה up-mode, בחירת clock-enable
  של `/1`, ‏`/2`, ‏`/4`, ‏`/8`, compare תקופתי, שני מצבי PWM ו-input capture
  מסונכרן בקצה עולה/יורד.
- מומש `pushbutton_unit.vhd` עבור KEY1-KEY3 active-low: שני שלבי synchronizer,
  debounce של 10 ms ב-25 MHz, מצב לחוץ active-high ואירוע יחיד לכל לחיצה.
- נוסף `mcu_peripherals.vhd` שמאחד את GPIO, הטיימר והכפתורים תחת MMIO mux
  יחיד בלי לשנות את ממשק ה-bus של ה-CPU.
- ה-Top-Level מחבר `SW8/SW9` ל-CAPIN1/CAPIN2, ‏`LEDR8` ל-PWM ו-`LEDR9`
  לחיווי של כל כפתור מסונן; חיבורי האירועים מוכנים לשלב 6.
- נוספו שלושה TBs ושלושה scripts נפרדים עם Wave, List ושמירת List אוטומטית.
- כל שלוש הבדיקות החדשות עברו: `STAGE 4 BASIC TIMER PASS`,
  `STAGE 5 PUSHBUTTONS PASS`, ו-`STAGE 4/5 PERIPHERAL INTEGRATION PASS`.
- רגרסיה אוטומטית מלאה של כל עשר בדיקות שלבים 0–5 עברה.
- Quartus Analysis & Synthesis עבר עם 0 errors ו-8 warnings; אזהרות עומק קובצי
  HEX ואותות debug שאינם נצרכים אינן חוסמות.
- נוסף `DOC/MODELSIM_TESTS_STAGE4_TO_STAGE5.md`. שלבים 4–5 נשארים במצב
  `~` עד שהמשתמש ישמור ראיות GUI; רק אז תיכתב תוכנית המעבדה של שלב 5.5.

### 17.08.2026 21:48 IDT - סגירת שלב 3

- בדיקת `STAGE 3 CPU/DIVIDER INTEGRATION PASS` עברה גם בהרצת ModelSim GUI של המשתמש.
- נשמרו ונוספו ל-Git צילום מסך, Wave ו-List עבור בדיקת האינטגרציה בתיקיית הראיות של שלב 3.
- יחד עם ראיות ה-Divider unit, כל שבע בדיקות שלבים 0–3 עברו ותועדו.
- שלב 3 מסומן כעת הושלם; הפעולה הבאה היא מימוש משולב של שלבים 4 ו-5 ולאחריו בדיקות ModelSim ובדיקת חומרה 5.5.

### 17.08.2026 21:44 IDT - שינוי שמות אות ההחזקה של המחלק

- `stall_w` בליבת המעבד שונה ל-`divider_hold_w`.
- `stall_i` ב-IFETCH ובהצהרת ה-component שונה ל-`divider_hold_i`.
- סקריפט Wave/List והתיעוד עודכנו לשמות החדשים, כך שאין בלבול עם pipeline stall עתידי.
- אינטגרציית CPU/Divider עברה שוב ב-ModelSim לאחר שינוי השמות.
- Quartus Analysis & Synthesis עבר עם 0 errors ו-13 warnings.

### 17.08.2026 21:36 IDT - סינתזה לאחר תיקון ה-stall

- Quartus Analysis & Synthesis עבר על הגרסה הסופית של תיקון ה-Divider.
- תוצאה: 0 errors ו-13 warnings; אלו אותן אזהרות לא חוסמות שתועדו קודם.

### 17.08.2026 21:34 IDT - תיקון stall ואימות אינטגרציית ה-Divider

- בדיקת האינטגרציה נכשלה תחילה ב-782 ns משום שה-PC השתנה בזמן `div_busy`.
- נמצא ש-`IFETCH` שמר את רגיסטר ה-PC בזמן stall, אך כתובת ITCM המשיכה להיגזר מ-`next_pc_w`; לכן ה-decode עבר לפקודה הבאה מוקדם מדי.
- בזמן stall כתובת ITCM נלקחת כעת מ-`pc_q`, ונוסף מצב retire שמשאיר את פקודת ה-DIV עד קצה ה-write-back ומשחרר אותה פעם אחת בלבד.
- התיקון תומך גם בשתי פקודות Divider עוקבות ואינו מאפשר שיגור כפול של אותה פקודה.
- אינטגרציית CPU/Divider עברה ב-20462 ns; לאחר מכן עברו גם כל שש בדיקות הרגרסיה האחרות של שלבים 0–3.
- נוסף `DOC/DIVIDER_STALL_FIX_2026-08-17.md` עם ניתוח התקלה והאימות.
- ראיות ה-GUI של Divider unit נשמרו; נשאר לשמור את ראיות ה-GUI של האינטגרציה המתוקנת.

### 17.08.2026 21:21 IDT - תיקון והרצת Divider unit

- בהרצה הראשונה `const_package.vhd` לא התקמפל משום שהסקריפט לא קימפל קודם את `cond_compilation_package.vhd`.
- סדר הקומפילציה ב-`run_stage3_divider_unit.do` תוקן בהתאם ל-`COMPILE_ORDER.txt` ולסקריפט האינטגרציה.
- הרצת console מלאה עברה עם 0 errors ו-0 warnings והתקבלה ההודעה `STAGE 3 DIVIDER UNIT PASS` ב-5661 ns.
- עדיין נדרשת הרצה חוזרת ב-GUI לשמירת Wave/List, ולאחריה בדיקת CPU/Divider integration.

### 17.08.2026 21:19 IDT - הושלם תיעוד GUI של שלב 2

- נשמרו צילום מסך, Wave ו-List עבור `GPIO/test0` integration.
- נשמרו צילום מסך, Wave ו-List עבור בדיקות `GPIO/test1` ו-`GPIO/test2` עם switches.
- בכך הושלם גם תיעוד הראיות של שלב 2, מעבר להרצות האוטומטיות שכבר עברו.

### 13.08.2026 15:08 IDT - סינתזה חוזרת לאחר תיקוני ה-CPU

- Quartus Prime Lite 21.1 Analysis & Synthesis עבר לאחר תיקוני LUI/load.
- תוצאה: 0 errors ו-13 warnings; לא נוספה אזהרה חדשה שחוסמת את התכנון.
- נשמר אותו פרופיל חומרה צפוי: PLL אחד, 4 DSP ו-64 מקטעי RAM.

### 13.08.2026 15:04 IDT - תיקון פענוח immediate וסגירת שלב 2

- בדיקת `GPIO/test0` נכשלה תחילה משום שהמעבד יצר `0x0000/4/5/...` במקום `0x2000/4/5/...`.
- נמצא שקבוע U-type מקורי שימש גם כמסכה וגם כ-opcode מדויק; `LUI` קיבל immediate אפס.
- הוגדרו `AUIPC_OPC` ו-`LUI_OPC` בנפרד והפענוח עודכן בשני המקומות.
- בדיקת `test1/test2` חשפה בנוסף ש-load לא קיבל I-immediate; נוסף `LOAD_OPC` לפענוח.
- דגימת ה-bus בשני integration TBs הותאמה לקצה שבו טרנזקציית GPIO מתבצעת.
- רגרסיית שלב 0 עברה ב-6222 ns, ‏GPIO/test0 עבר ב-2462 ns ו-test1/test2 עברו ב-2342 ns.
- נוסף `DOC/CPU_IMMEDIATE_DECODE_FIX_2026-08-13.md` עם ניתוח מלא וראיות.

### 13.08.2026 14:18 IDT - GPIO unit test עבר

- התקבלה ההודעה `STAGE 2 GPIO UNIT PASS` בזמן סימולציה 223 ns.
- נשמרו Wave, ‏List וצילום מסך בתיקיית הראיות של שלב 2.

### 13.08.2026 14:11 IDT - בדיקת interconnect עברה

- התקבלה ההודעה `STAGE 1 INTERCONNECT PASS` בזמן סימולציה 5 ns.
- נשמרו Wave, ‏List וצילום מסך בתיקיית הראיות של שלב 1.

### 13.08.2026 14:05 IDT - שמירת List אוטומטית בבדיקות ModelSim

- כל שבעת קובצי ה-`.do` עודכנו כך שהאותות של Wave מתווספים גם לחלון List.
- כל הרצה שומרת אוטומטית קובץ `*_list.do` באמצעות `write format list`.
- מסמך הבדיקות עודכן עם רשימת שבעת קובצי ה-List הצפויים.

### 13.08.2026 14:00 IDT - שלב 0 עבר ב-ModelSim

- התקבלה ההודעה `STAGE 0 PASS: RV32I/MUL baseline and DTCM regression` בזמן סימולציה 6222 ns.
- נשמרו `stage0_baseline.log`, צילום Wave וקובץ Wave בתיקיית `screenshots/stage 0`.
- אזהרות arithmetic operand מסוג U/X הופיעו רק בזמן 0 ps ולא מנעו PASS.

### 12.08.2026 21:58 IDT - הוכן מסמך העבודה למחר

- נוסף `DOC/TOMORROW_MODELSIM_CHECKLIST.md` עם הכנה מדויקת וסדר שבע ההרצות.
- לכל בדיקה תועדו פקודת ההרצה, הודעת PASS, אותות לבדיקה וקובץ ה-log הצפוי.
- תועדו נוהל עצירה בכשל, טיפול בספריית `altera_mf` ותבנית דיווח מסכמת.

### 12.08.2026 21:53 IDT - נוסף שלב 5.5 לבדיקת חומרה מוקדמת

- נקבע checkpoint פיזי לאחר השלמת בדיקות ModelSim של שלבים 4–5.
- הבדיקה תכסה KEY1-KEY3 מסונכרנים ועם debounce, וכן יציאת PWM מה-Basic Timer.
- שלב 5.5 אינו מחליף את אימות המערכת המלא על הכרטיס בשלבים 9–10.

### 12.08.2026 21:46 IDT - העלאה ל-GitHub

- המאגר המקומי חובר אל `https://github.com/noamkorinperi/VHDL_LAB_final.git`.
- ה-commit הראשוני שנוצר באתר נשמר ומוזג להיסטוריה המקומית ללא מחיקה.
- הענף `main` הועלה בהצלחה והוגדר לעקוב אחרי `origin/main`.
- המאגר מוגדר כ-Public בהתאם לאישור המפורש של המשתמש להעלות את הפרויקט כפי שהוא.

### 12.08.2026 21:37 IDT - הקמת בקרת גרסאות

- אותחל מאגר Git מקומי על הענף `main`.
- עודכן `.gitignore` כך שתוצרי Quartus ו-ModelSim לא ייכנסו להיסטוריה.
- הוכן checkpoint ראשון בשם `Stage 3 implementation ready for ModelSim`.
- נוסף `README.md` לניווט מהיר בפרויקט ובתיעוד.

### 12.08.2026 21:32 IDT - כיסוי GPIO/test1 ו-GPIO/test2

- נוספו עותקים ייעודיים של קובצי הזיכרון עבור `GPIO/test1` ו-`GPIO/test2`.
- נוספו TB ו-script שמריצים את שני ה-benchmarks במקביל, מגרים את SW0 ובודקים כתיבות LEDR/HEX.
- שלב 2 מוכן כעת לבדיקת כל שלושת ה-benchmarks שסופקו, בלי החלפת קבצים ידנית.

### 12.08.2026 21:30 IDT - Quartus סופי לאחר סנכרון הממשקים

- Analysis & Synthesis חוזר עבר עם 0 errors ו-13 warnings לאחר עדכון כל הצהרות ה-components.
- דוח הסיום מאשר 1,666 registers, ‏131,072 block-memory bits, ‏4 DSP blocks ו-PLL אחד.
- לא נמצאו בדוח אזהרות latch, multiple constant drivers או combinational loop.

### 12.08.2026 21:28 IDT - בדיקה נפרדת לשלב 1

- נוספו `tb_stage1_interconnect.vhd` ו-`run_stage1_interconnect.do` כדי שלכל שלב 0–3 תהיה בדיקה עצמאית.
- הבדיקה מכסה DTCM word addressing, שמירת כתובת MMIO מלאה, read mux, write isolation וכתובת unmapped.

### 12.08.2026 21:25 IDT - שלבים 2–3 מוכנים לבדיקה

- ה-CPU הוסב ל-data bus חיצוני ונוספו `mcu_interconnect` ו-`gpio_peripheral`.
- מומשו LEDR, ששת ה-HEX, encoder active-low וקריאת SW עם zero extension.
- מומשו `divider_unsigned` ו-`divider_accelerator` עבור `DIV/DIVU/REM/REMU`, כולל מקרי קצה ו-CDC.
- נוספו stall ל-IFETCH ומדיניות write-back יחיד בפולס `done`.
- ה-top עודכן ל-sysclk של 25 MHz ול-DIVCLK של 50 MHz באמצעות PLL ל-Cyclone V.
- נוספו חמישה testbenches וחמישה scripts עצמאיים של ModelSim, וכן הוראות הרצה ב-`DOC/MODELSIM_TESTS_STAGE0_TO_STAGE3.md`.
- Quartus Analysis & Synthesis עבר על המימוש המשולב עם 0 errors ו-13 warnings: 1,666 registers, ‏131,072 memory bits, ‏4 DSP ו-PLL אחד.
- בדיקות ModelSim עצמן לא הורצו, בהתאם לבקשת המשתמש; לכן שלבים 2–3 מסומנים "מוכן לבדיקה" ולא "עבר".

### 12.08.2026 20:59 IDT - מדיניות חותמות זמן

- פורמט הסטטוס שונה כך שכל השלמה, דחייה או התחלת עבודה כוללת תאריך ושעה.
- פעולות היסטוריות שזמן יצירת הקובץ שלהן ידוע קיבלו את הזמן המתועד בפועל.
- פעולות שקדמו למעקב הקבצים סומנו באמצעות `אומת`, כדי לא להציג זמן ביצוע מומצא.

### 12.08.2026 20:44 IDT - סגירת תיעוד שלב 1

- נוצר `DOC/PHASE_1_STATUS.md`.
- שלב 1 סומן כמוכן לאחר בדיקת התוצרים ודוח Quartus.
- משימות ModelSim של שלב 0 סומנו כנדחות לבקשת המשתמש.

### 12.08.2026 20:42 IDT - Quartus Analysis & Synthesis

- Analysis & Synthesis הסתיים בהצלחה עם 0 errors.
- נשמרו `RV32IMscMCU.map.rpt` ו-`RV32IMscMCU.map.summary`.
- ה-warnings סווגו ותועדו; לא נמצא כשל elaboration או שגיאת VHDL.

### 12.08.2026 20:34 IDT - ארכיטקטורה ושלד Quartus

- נוספו `mcu_memory_map_pkg.vhd`, ‏`RV32IMscMCU.vhd` ו-`COMPILE_ORDER.txt`.
- נוצרו `DOC/ARCHITECTURE.md` וקובצי `.qpf/.qsf/.sdc`.
- נקבעו Top-Level, מפת הכתובות, ממשק ה-bus ותוכנית clocks/reset.

### 12.08.2026 20:31 IDT - ניידות זיכרונות

- נתיבי `ITCM.hex` ו-`DTCM.hex` המוחלטים הוחלפו ב-generics ניידים.
- יעד הזיכרונות עודכן ל-`Cyclone V`.

### 12.08.2026 20:29 IDT - הקמת עץ העבודה

- נוצרו `DUT`, ‏`TB`, ‏`SIM`, ‏`DOC` ו-`Quartus`.
- קובצי ה-single-cycle מ-Lab 5 הועתקו לעץ העבודה בלי לשנות את המקורות.

### 12.08.2026 20:12 IDT - אימות חומרי הקלט

- אומתו מסמך הדרישות, התמלול, קוד המעבדה וה-benchmarks.
- אומתו זוגות `ITCM.hex`/`DTCM.hex` עבור RV32IM, GPIO ופסיקות.
- תועד כרטיס היעד DE10-Standard.

### סיכום השינויים של שלבים 0-1

מצב מקורות:

- תיקיות `מעבדה קודמת שלנו`, `קבצים מהמדריך` ו-`Benchmark apps` נשמרו ללא שינוי.
- עץ העבודה החדש נוצר בתיקיות `DUT`, `TB`, `SIM`, `DOC` ו-`Quartus`.
- בסיס המימוש הפעיל נלקח מגרסת ה-RV32IM single-cycle של Lab 5, ולא מגרסת ה-RV32I המקורית של המנחה.

שינויים בקובצי Lab 5 שהועתקו לעץ העבודה:

| קובץ | שינוי שבוצע כעת |
|---|---|
| `IFETCH.VHD` | הנתיב המוחלט ל-`ITCM.hex` הוחלף ב-generic בשם `INIT_FILE`; משפחת היעד עודכנה ל-`Cyclone V` |
| `DMEMORY.VHD` | הנתיב המוחלט ל-`DTCM.hex` הוחלף ב-generic בשם `INIT_FILE`; משפחת היעד עודכנה ל-`Cyclone V` |
| `RV32I_CORE.vhd` | נוספו `ITCM_INIT_FILE` ו-`DTCM_INIT_FILE` והם מועברים לרכיבי הזיכרון |
| `aux_package.vhd` | הצהרות ה-generics עודכנו בהתאם לנתיבי הזיכרון הניידים |

קובצי DUT חדשים:

- `mcu_memory_map_pkg.vhd` - מקור אמת יחיד לכתובות MMIO ולערכי interrupt TYPE.
- `RV32IMscMCU.vhd` - Top-Level מבני יציב עבור המערכת והכרטיס.
- `COMPILE_ORDER.txt` - סדר קומפילציה מתועד ל-VHDL-2008.

תשתיות חדשות:

- פרויקט Quartus: `RV32IMscMCU.qpf`, `RV32IMscMCU.qsf` ו-`RV32IMscMCU.sdc`.
- עותקים מקומיים של `ITCM.hex` ו-`DTCM.hex` עבור SIM ו-Quartus.
- `DOC/ARCHITECTURE.md`, `DOC/PHASE_1_STATUS.md` ו-`DOC/Readme.txt`.
- `.gitignore` עבור תוצרי Quartus, ModelSim ועורכים.

מה הוחרג או נדחה:

- אף קובץ מקור לא נמחק.
- `PLL.vhd` הישן נשאר בעץ ה-DUT אך אינו נכלל בבניית שלב 1, מפני שהוא נוצר עבור Cyclone II.
- שלב 1 משתמש זמנית ב-`CLOCK_50` ישירות; יחידת clock/reset ל-Cyclone V תתווסף לפני שילוב המחלק.
- ה-Top-Level הנוכחי מחזיק את HEX כבויים ומשתמש ב-LEDR עבור observability זמנית; GPIO אמיתי יחליף זאת בשלב 2.
- SW ו-KEY1-KEY3 עדיין אינם מחוברים ללוגיקה פונקציונלית.
- קומפילציה והרצה ב-ModelSim, השוואת RARS ו-waveforms נדחו ליום ModelSim.

אימות שבוצע:

- כתובות ה-MMIO הושוו לקובצי `io_map.s` של ה-benchmarks.
- Quartus Prime Lite 21.1 Analysis & Synthesis עבר עם 0 errors.
- תוצאת synthesis ראשונית: 1,271 registers, ‏131,072 block-memory bits ו-4 DSP blocks.
- ה-warnings שנותרו נבדקו ומתועדים ב-`DOC/PHASE_1_STATUS.md`.

---

## שלב 0 - סביבת עבודה ובדיקת baseline

מטרה: להוכיח שהבסיס מהמעבדה הקודמת תקין לפני שמוסיפים MCU או משנים את המעבד.

- [x | אומת 12.08.2026 20:12 IDT] נאספה ליבת RV32IM single-cycle מהמעבדה הקודמת.
- [x | אומת 12.08.2026 20:12 IDT] נאספו testbenches וקובצי ModelSim `.do`.
- [x | אומת 12.08.2026 20:12 IDT] נאספו benchmark, Assembly וזוגות `ITCM.hex`/`DTCM.hex`.
- [x | אומת 12.08.2026 20:12 IDT] נשמרו בנפרד קוד ה-single-cycle, קוד ה-pipeline וחומר המקור מהמדריך.
- [x | אומת 12.08.2026 20:12 IDT] נקבע כרטיס היעד: DE10-Standard.
- [x | 12.08.2026 20:29 IDT] ליצור עץ עבודה חדש בלי לשנות את חומרי המקור.
- [x | 12.08.2026 20:29 IDT] להעתיק לעץ העבודה רק את קובצי ה-single-cycle הנדרשים.
- [x | 12.08.2026 20:31 IDT] להחליף נתיבי HEX קשיחים במנגנון נייד ומתועד.
- [x | 12.08.2026 20:34 IDT] לקבוע סדר קומפילציה אחיד ל-VHDL-2008.
- [! | 12.08.2026 20:44 IDT] לקמפל את הליבה ואת `tb_RV32IM` ב-ModelSim ללא שגיאות - נדחה ליום ModelSim.
- [! | 12.08.2026 20:44 IDT] להריץ את benchmark ה-RV32IM הידני - נדחה ליום ModelSim.
- [! | 12.08.2026 20:44 IDT] להריץ את גרסת ה-GCC אם היא תואמת לתת-הקבוצה הנתמכת בליבה - נדחה ליום ModelSim.
- [! | 12.08.2026 20:44 IDT] להשוות את תוצאת DTCM לתוצאת RARS - נדחה ליום ModelSim.
- [! | 12.08.2026 20:44 IDT] לשמור log ו-waveform קצרים כהוכחת baseline - נדחה ליום ModelSim.
- [ ] ליצור checkpoint מקומי לפני השינוי הפונקציונלי הראשון.

שער יציאה: הליבה הקיימת מתקמפלת, מסיימת benchmark, ותוצאת הזיכרון תואמת ל-golden model.

## שלב 1 - תכנון ארכיטקטורת ה-MCU

מטרה: לסגור את החיבורים והכתובות לפני כתיבת רכיבים חדשים.

- [x | 12.08.2026 20:34 IDT] להכין תרשים Top-Level מבני של CPU, ITCM, DTCM, GPIO, Divider, Timer ו-Interrupt Controller.
- [x | 12.08.2026 20:34 IDT] להגדיר ממשק data bus אחיד: כתובת, נתוני כתיבה, נתוני קריאה, `MemRead` ו-`MemWrite`.
- [x | 12.08.2026 20:34 IDT] להפריד בין DTCM בטווח `0x0000-0x1FFC` לבין MMIO בטווח `0x2000-0x3FFC`.
- [x | 12.08.2026 20:34 IDT] ליצור package יחיד עבור כתובות MMIO, מסכות וקבועי מערכת.
- [x | 12.08.2026 20:34 IDT] להגדיר byte-addressing עבור רגיסטרים סמוכים כמו `HEX0/HEX1` ו-`IE/IFG/TYPE`.
- [x | 12.08.2026 20:34 IDT] להגדיר read mux ו-address decoder ללא יותר מדרייבר אחד על bus הקריאה.
- [x | 12.08.2026 20:34 IDT] להגדיר clock/reset domains: `CLOCK_50`, שעון ליבה, `DIVCLK`, reset מ-KEY0 ו-PLL lock.
- [x | 12.08.2026 20:34 IDT] להגדיר handshake בין ה-CPU למחלק ואת מדיניות עצירת הליבה בזמן חלוקה.
- [x | 12.08.2026 20:34 IDT] להגדיר ממשק `INTR/INTA` ו-FSM הכניסה לפסיקה.
- [x | 12.08.2026 20:34 IDT] לתעד רוחב, כיוון ופולריות של כל אות Top-Level.
- [x | 12.08.2026 20:34 IDT] ליצור שלד Quartus ראשוני עם `.qpf/.qsf` עבור DE10-Standard לאחר ששמות ה-Top-Level והקבצים יציבים.
- [x | 12.08.2026 20:42 IDT] לבצע Analysis & Synthesis ראשוני ולשמור רשימת warnings לבדיקה.
- [x | 12.08.2026 20:44 IDT] לקבוע שכל milestone פונקציונלי מסתיים גם בבדיקת synthesis, לא רק ב-ModelSim.

### מפת כתובות מחייבת

| רכיב | כתובת | רזולוציה |
|---|---:|---|
| DTCM | `0x0000-0x1FFC` | Word storage, byte address space |
| `PORT_LEDR` | `0x2000` | Byte |
| `PORT_HEX0` | `0x2004` | Byte |
| `PORT_HEX1` | `0x2005` | Byte |
| `PORT_HEX2` | `0x2008` | Byte |
| `PORT_HEX3` | `0x2009` | Byte |
| `PORT_HEX4` | `0x200C` | Byte |
| `PORT_HEX5` | `0x200D` | Byte |
| `PORT_SW` | `0x2010` | Byte |
| `PORT_PB` | `0x2014` | Byte |
| UART bonus | `0x2018-0x201A` | Byte, שמור בלבד כרגע |
| `BTCTL1` | `0x201C` | Byte |
| `BTCTL2` | `0x201D` | Byte |
| `BTCMPR0` | `0x2020` | Word |
| `BTCMPR1` | `0x2024` | Word |
| `BTCAPR` | `0x2028` | Word |
| `IE` | `0x202C` | Byte |
| `IFG` | `0x202D` | Byte |
| `TYPE` | `0x202E` | Byte |

שער יציאה: תרשים, package כתובות, bus specification ותוכנית clocks/resets מאושרים ועקביים עם ה-benchmarks.

## שלב 2 - Memory-Mapped GPIO

מטרה: להריץ תחילה MCU שימושי ללא פסיקות.

- [x | 12.08.2026 21:25 IDT] לממש רגיסטר פלט עבור `LEDR7-LEDR0`.
- [x | 12.08.2026 21:25 IDT] לממש שישה רגיסטרים עבור `HEX0-HEX5`.
- [x | 12.08.2026 21:25 IDT] לממש 7-segment encoder בהתאם לפולריות של DE10-Standard.
- [x | 12.08.2026 21:25 IDT] לממש קריאת `SW7-SW0`.
- [x | 12.08.2026 21:25 IDT] לחבר address decoder ו-read mux ל-DTCM ול-GPIO.
- [x | 12.08.2026 21:25 IDT] להבטיח שכתיבה ל-MMIO אינה כותבת במקביל ל-DTCM.
- [x | 12.08.2026 21:25 IDT] ליצור testbench ממוקד עבור read/write של כל כתובת.
- [! | 12.08.2026 21:32 IDT] להריץ `GPIO/test0`, אחריו `test1` ו-`test2` - נדחה ליום ModelSim; שלושתם מוכנים בבדיקות integration אוטומטיות.
- [x | 12.08.2026 21:25 IDT] לבדוק בתכן את reset מ-KEY0 והתנהגות שמירת ערכי פלט; אימות waveform ממתין ל-ModelSim.

שער יציאה: שלושת benchmarks של GPIO עוברים ב-ModelSim והיציאות תואמות לתוכנית ה-Assembly.

## שלב 3 - Divider Accelerator

מטרה: להשלים את פעולות החלוקה של RV32IM באמצעות מחלק רב-מחזורי.

- [x | 12.08.2026 21:25 IDT] לאשר מתוך ה-benchmark ומפרט RV32M אילו פקודות נדרשות: `DIV`, `DIVU`, `REM`, `REMU`.
- [x | 12.08.2026 21:25 IDT] לממש מחלק unsigned של 32 ביט בשיטת shift/subtract.
- [x | 12.08.2026 21:25 IDT] להפיק quotient ו-remainder לאחר 32 מחזורי `DIVCLK`.
- [x | 12.08.2026 21:25 IDT] להגדיר `start`, `busy`, `done` וטעינת operands חד-פעמית.
- [x | 12.08.2026 21:25 IDT] לטפל בסימן מחוץ לליבת המחלק עבור פעולות signed.
- [x | 12.08.2026 21:25 IDT] לטפל במקרי קצה: divisor אפס, overflow וסימני operands.
- [x | 12.08.2026 21:25 IDT] לממש CDC מסודר בין שעון הליבה ל-`DIVCLK`.
- [x | 12.08.2026 21:25 IDT] לעצור את הליבה בלי לבצע פקודה או write-back פעמיים.
- [x | 12.08.2026 21:25 IDT] ליצור testbench עצמאי עם reference model ומקרי קצה.
- [x | 12.08.2026 21:25 IDT] להוסיף בדיקות instruction-level בתוך הליבה.

שער יציאה: כל תוצאות quotient/remainder תואמות למודל הייחוס, כולל מקרי קצה ו-CDC.

## שלב 4 - Basic Timer

מטרה: לממש מונה, compare, PWM ו-input capture לפי Figure 7 ו-Figure 8.

- [x | 17.08.2026 22:21 IDT] לממש `BTCNT` ומקורות clock נבחרים.
- [x | 17.08.2026 22:21 IDT] לממש `BTCTL1`: `BTINT`, `BTCLR`, `BTSSEL`, `BTHOLD`, `BTOUTEN`, `BTOUTMD`.
- [x | 17.08.2026 22:21 IDT] לממש `BTCTL2`: `CAPISEL` ו-`CAPMD`.
- [x | 17.08.2026 22:21 IDT] לממש compare registers וטעינת ערכי compare.
- [x | 17.08.2026 22:21 IDT] לממש compare interrupt תקופתי.
- [x | 17.08.2026 22:21 IDT] לממש PWM בשני מצבי output compare.
- [x | 17.08.2026 22:21 IDT] לממש input capture ל-`BTCAPR` בקצה עולה ובקצה יורד.
- [x | 17.08.2026 22:21 IDT] לסנכרן מקורות capture חיצוניים.
- [x | 17.08.2026 22:21 IDT] לבדוק reset, hold, clear ושינוי clock source.
- [x | 17.08.2026 22:21 IDT] ליצור testbench עצמאי לכל מצב לפני חיבור לפסיקות.

מצב: כל הסעיפים עברו בהרצה אוטומטית וב-GUI, והראיות נשמרו.

שער יציאה: timer period, PWM duty cycle ו-captured count תואמים לערכים הצפויים.

## שלב 5 - Pushbuttons

מטרה: להפוך את KEY1-KEY3 לקלט יציב ולמקורות פסיקה אמינים.

- [x | 17.08.2026 22:21 IDT] להתאים לפולריות active-low של לחצני DE10-Standard.
- [x | 17.08.2026 22:21 IDT] לסנכרן כל לחצן לשעון המערכת.
- [x | 17.08.2026 22:21 IDT] לממש debounce לפי דרישת המסמך.
- [x | 17.08.2026 22:21 IDT] לממש edge/event detection כך שלחיצה אחת יוצרת אירוע אחד.
- [x | 17.08.2026 22:21 IDT] לממש קריאת `PORT_PB` בכתובת `0x2014`.
- [x | 17.08.2026 22:21 IDT] להפיק flags נפרדים עבור KEY1, KEY2 ו-KEY3.
- [x | 17.08.2026 22:21 IDT] לבדוק לחיצה קצרה, לחיצה ארוכה, bounce ולחיצות סמוכות.

מצב: כל הסעיפים עברו בהרצה אוטומטית וב-GUI, והראיות נשמרו.

שער יציאה: כל לחיצה חוקית נראית פעם אחת ב-MMIO ומייצרת flag יחיד.

## שלב 5.5 - בדיקת חומרה מוקדמת: Pushbuttons ו-PWM

מטרה: לאמת מוקדם על DE10-Standard את ממשקי הכרטיס, ה-reset, הכפתורים ויציאת
ה-PWM, לפני הוספת בקר הפסיקות ושינויי ה-CPU.

תנאי כניסה: שלבים 0–5 עברו את בדיקות ModelSim שלהם, ובפרט בדיקות ה-timer,
ה-PWM, הסנכרון וה-debounce.

- [x | 17.08.2026 22:43 IDT] להשלים pin assignments רשמיים עבור `CLOCK_50`, `KEY`, `SW`, `LEDR`,
  `HEX` ופין ה-PWM הנבחר; אין להסתמך על הקצאת פינים אוטומטית.
- [x | 17.08.2026 22:09 IDT] להוסיף יציאת PWM פיזית ל-Top-Level ולנתב אותה ל-LEDR או לפין GPIO
  מתאים למדידה.
- [x | 17.08.2026 22:09 IDT] לחבר את KEY1-KEY3 ללוגיקת שלב 5, תוך שמירת KEY0 כ-reset active-low.
- [x | 17.08.2026 22:43 IDT] להכין תוכנת או תצורת smoke-test שבה כל לחיצה חוקית משנה LED/HEX פעם
  אחת, והכפתורים משנים ערך duty cycle ניתן לצפייה.
- [x | 17.08.2026 22:56 IDT] לבצע Quartus Full Compilation, לסקור warnings ולהפיק קובץ `.sof`.
- [x | 17.08.2026 23:06 IDT] להריץ preflight אוטומטי על קובץ ה-ITCM המדויק
  ששובץ ב-SOF ולאמת HEX0, כפתורים ו-PWM.
- [ ] לצרוב את ה-SOF ולבדוק reset, לחיצה קצרה, לחיצה ארוכה, bounce ולחיצות
  סמוכות על הכרטיס.
- [ ] לבדוק PWM בכמה ערכי duty cycle; ב-LEDR לפי עוצמת הארה, ובמידת האפשר
  בפין GPIO באמצעות oscilloscope או logic analyzer.
- [ ] לשמור תמונות/מדידות ותוצאות הקומפילציה, וליצור checkpoint ב-Git.

בשלב זה הכפתורים נבדקים באמצעות polling או אות תצפית ייעודי. מסלול הפסיקה
המלא דרך Interrupt Controller ו-ISR ייבדק רק לאחר שלבים 6–7.

שער יציאה: כל KEY מייצר שינוי פיזי יחיד לכל לחיצה חוקית, ה-PWM נצפה בכמה
ערכי duty cycle, וה-SOF נטען ללא שגיאה. שלב זה אינו מחליף את בדיקת החומרה
המלאה ואת SignalTap בשלבים 9–10.

## שלב 6 - Interrupt Controller

מטרה: לרכז מקורות פסיקה, mask, flags, type ותעדוף.

- [~ | 17.08.2026 22:58 IDT] לממש את רגיסטרי `IE`, `IFG` ו-`TYPE`.
- [~ | 17.08.2026 22:58 IDT] לחבר `BTIFG` ואת flags של KEY1-KEY3.
- [~ | 17.08.2026 22:58 IDT] לשמור את ביטי UART שמורים או מנוטרלים כל עוד הבונוס אינו ממומש.
- [~ | 17.08.2026 22:58 IDT] לממש priority encoder לפי טבלת הווקטורים.
- [~ | 17.08.2026 22:58 IDT] להפיק `INTR` רק כאשר יש pending enabled interrupt ו-GIE פעיל.
- [~ | 17.08.2026 22:58 IDT] לממש `INTA`/service acknowledgement לפי הפרוטוקול.
- [~ | 17.08.2026 22:58 IDT] לממש clear אוטומטי או software clear לפי סוג המקור.
- [~ | 17.08.2026 22:58 IDT] לבדוק מקור יחיד, כמה מקורות יחד, mask ושינוי priority.

### תעדוף בסיסי ללא UART

| מקור | TYPE | עדיפות |
|---|---:|---:|
| RESET | `0x00` | 0, הגבוהה ביותר |
| Basic Timer | `0x10` | 4 |
| KEY1 | `0x14` | 5 |
| KEY2 | `0x18` | 6 |
| KEY3 | `0x1C` | 7, הנמוכה ביותר |

שער יציאה: `TYPE` תמיד מציג את המקור הפעיל בעל העדיפות הגבוהה, ו-flags מתנקים לפי הדרישה.

## שלב 7 - תמיכת פסיקות בתוך ה-CPU

מטרה: להוסיף לליבת single-cycle פרוטוקול פנימי רב-מחזורי בלי לשבור ביצוע רגיל.

- [~ | 17.08.2026 22:58 IDT] להגדיר GIE בביט `gp[0]` ואת התנהגות enable/disable.
- [~ | 17.08.2026 22:58 IDT] לממש FSM כניסה לפסיקה בשני מחזורים.
- [~ | 17.08.2026 22:58 IDT] במחזור הראשון: לנקות GIE, להפעיל `INTA` וללכוד `TYPE` מה-data bus.
- [~ | 17.08.2026 22:58 IDT] במחזור השני: לשמור `PC+4` ב-`tp` ולקפוץ דרך vector table.
- [~ | 17.08.2026 22:58 IDT] למנוע write-back, memory write או PC advance לא מכוונים בזמן ה-FSM.
- [~ | 17.08.2026 22:58 IDT] לזהות `jalr zero, 0(tp)` כ-`reti` ולהחזיר GIE ל-1.
- [~ | 17.08.2026 22:58 IDT] לבדוק שהחזרה היא בדיוק לפקודה שאחרי הפקודה שנקטעה.
- [ ] לבדוק פסיקה בזמן load, store, branch, jump, multiply ו-divider wait.

שער יציאה: ISR נכנס וחוזר באופן דטרמיניסטי, ללא איבוד או ביצוע כפול של פקודות.

## שלב 8 - אינטגרציה ואימות מלא

מטרה: להוכיח שהמערכת השלמה עובדת מול ה-golden model.

- [x | 25.08.2026 22:18 IDT] ליצור `tb_RV32IMscMCU.vhd` מרכזי ובודק-עצמית.
- [x | 25.08.2026 22:18 IDT] ליצור קובץ `.do` אחיד לקומפילציה, הרצה ו-waveforms.
- [x | 25.08.2026 22:18 IDT] להריץ את כל ה-basic benchmarks.
- [x | 25.08.2026 22:18 IDT] להריץ את כל ה-advanced/interrupt benchmarks.
- [x | 25.08.2026 22:18 IDT] לדמות switches, pushbuttons, capture inputs ושעונים.
- [x | 25.08.2026 22:18 IDT] להשוות DTCM סופי בין ModelSim לבין RARS.
- [x | 25.08.2026 22:18 IDT] להוסיף assertions עבור illegal bus overlap, X/U, timeout ופרוטוקולי handshake.
- [x | 25.08.2026 22:18 IDT] למדוד cycles ו-IPC בשיטה שתוגדר במפורש.
- [x | 25.08.2026 22:18 IDT] לשמור waveforms מייצגים עבור הדוח.

שער יציאה: כל benchmark מסתיים ללא timeout או assertion failure, והזיכרון הסופי תואם ל-RARS.

## שלב 9 - Quartus ו-DE10-Standard

מטרה: להשלים את שלד Quartus שנוצר בשלב 1 ולהעביר את המימוש המאומת ל-FPGA.

- [x | 25.08.2026 22:18 IDT] לעדכן את פרויקט Quartus של `RV32IMscMCU` בכל קובצי המימוש הנוכחיים;
  נבדק מחדש לאחר שלב 8 עם firmware של interrupt/test4.
- [x | 17.08.2026 22:43 IDT] לבחור את רכיב ה-Cyclone V המדויק של DE10-Standard לפי קובץ הכרטיס.
- [x | 17.08.2026 22:43 IDT] להגדיר את הישות המבנית העליונה כ-Top-Level Entity.
- [x | 17.08.2026 22:43 IDT] להוסיף את כל קובצי ה-VHDL בסדר תקין.
- [x | 17.08.2026 22:43 IDT] ליצור `.qsf` עם pin assignments עבור `CLOCK_50`, `KEY`, `SW`, `LEDR`, `HEX` ו-GPIO נדרש.
- [x | 25.08.2026 22:18 IDT] ליצור/לעדכן `.sdc` עם clocks, I/O ו-CDC constraints נכונים.
- [x | 17.08.2026 22:56 IDT] להגדיר PLL ו-`DIVCLK` ולוודא clock relationships.
- [x | 25.08.2026 22:18 IDT] לקמפל ללא errors ולסקור warnings משמעותיים עבור המימוש הנוכחי;
  Full Compilation ו-TimeQuest חוזר עברו לאחר שלב 8.
- [x | 26.08.2026 19:30 IDT] הופק ונטען `.sof` סופי עם interrupt/test4;
  reset, compare interrupts, PWM ושני מסלולי KEY3 ‏(REM/DIV) עברו אימות פיזי.

שער יציאה: ה-SOF נטען והמערכת מבצעת את תרחיש ההדגמה על DE10-Standard.

## שלב 10 - SignalTap ו-PPA

מטרה: לספק הוכחה על החומרה ולמלא את דרישות הניתוח.

- [ ] ליצור קובץ SignalTap `.stp` עם PC, instruction, bus, interrupt ו-timer signals.
- [ ] ללכוד תרחיש GPIO על הכרטיס.
- [ ] ללכוד כניסה ויציאה מפסיקה.
- [ ] ללכוד handshake של divider או timer לפי הצורך.
- [ ] להסיר final validation pins שאינם I/O אמיתי של ה-MCU.
- [ ] לשמור screenshot של Quartus Area report - חובה.
- [ ] לשמור screenshot של Quartus Fmax/Timing report - חובה.
- [ ] לזהות ולהסביר את ה-critical path.
- [ ] לשמור screenshot של Quartus Power report - חובה.
- [ ] למלא טבלאות Area, Performance ו-Power עבור MCU עם GPIO ועבור MCU עם פסיקות.
- [-] למלא שורת pipeline רק אם יבוצע הבונוס; אחרת לסמן N/A לאחר אימות מול המרצה.

שער יציאה: קיימות לכידות SignalTap ודוחות Quartus מלאים שניתן להכניס ישירות לדוח.

## שלב 11 - דוח והגשה

מטרה: להגיש חבילה נקייה, משתחזרת ותואמת למסמך.

- [ ] להכין Top-Level block diagram סופי.
- [ ] לצרף RTL Viewer results.
- [ ] לתאר בקצרה כל קובץ HDL.
- [ ] לצרף ניתוח waveforms של benchmarks בסיסיים ומתקדמים.
- [ ] לצרף טבלאות PPA וה-screenshots המחייבים.
- [ ] לתעד verification מול RARS ומדידת IPC.
- [ ] לכתוב מסקנות ומגבלות.
- [ ] ליצור `Readme.txt` שמסביר כל תיקייה ותת-תיקייה.
- [ ] לנקות קובצי build ותוצרים שאינם נדרשים.
- [ ] לוודא קומפילציה מחדש מתוך חבילת ההגשה הנקייה.
- [ ] ליצור `id1_id2.zip`, כאשר `id1 < id2`.
- [ ] לוודא שהסטודנט עם `id1` הוא שמעלה ל-Moodle.

### מבנה הגשה מתוכנן

```text
DUT/
  RV32IMscMCU/
TB/
  RV32IMscMCU/
SIM/
  RV32IMscMCU/
DOC/
Quartus/
  RV32IMscMCU/
```

תיקיות pipeline יתווספו רק אם הבונוס ימומש. חבילת העבודה יכולה להכיל קובצי `.qpf/.qsf`, אך לפני האריזה נוודא שוב מהם קובצי Quartus שהמסמך דורש בתוך ה-ZIP.

שער יציאה: ה-ZIP נפתח בתיקייה נקייה, ModelSim ו-Quartus מתקמפלים ממנו, והדוח מכיל את כל הראיות.

---

## מטריצת אימות

| רכיב | Unit TB | Integration TB | Benchmark/RARS | FPGA/SignalTap |
|---|---|---|---|---|
| RV32IM baseline | קיים חלקית | נדרש | RV32IM test1 | בהמשך |
| GPIO | נדרש | נדרש | GPIO test0-test2 | חובה |
| Divider | נדרש | נדרש | RV32IM/div tests | מומלץ |
| Basic Timer | עבר | עבר | interrupt tests | חובה |
| Pushbuttons | עבר | עבר | interrupt tests | חובה |
| Interrupt Controller | עבר אוטומטית; GUI ממתין | מחובר | interrupt test2 מוכן | חובה |
| CPU interrupt FSM | מכוסה באינטגרציה | עבר אוטומטית; GUI ממתין | interrupt test2 עבר אוטומטית | חובה |

## סיכונים ונושאים שדורשים תשומת לב

1. כתובות MMIO מסוימות מופרדות בבית אחד, ולכן אסור לאבד את ביטי הכתובת הנמוכים.
2. ה-DTCM הקיים משתמש במיפוי word-oriented; צריך להפריד בין כתובת ה-bus לבין כתובת ה-RAM.
3. המחלק עובד בדומיין שעון אחר ודורש CDC ו-handshake ללא pulses אבודים.
4. כניסה לפסיקה היא רב-מחזורית בתוך ליבה שהייתה single-cycle.
5. reset ו-KEY ב-DE10-Standard הם active-low, בעוד testbenches קיימים משתמשים לעיתים ב-reset active-high.
6. קובצי הזיכרון בקוד המעבדה משתמשים בנתיבים מוחלטים ממחשב אחר.
7. מסמך הדרישות מפנה לחישוב IPC שאינו מופיע בצורה ברורה ב-PDF; נגדיר נוסחה ונאשר אותה לפני הדוח.
8. המסמך כותב "six subdirectories" אך מציג בטבלה חמש תיקיות ראשיות בלבד.
9. טבלת הפסיקות כוללת UART גם כאשר UART הוא בונוס; במימוש הבסיסי נשמור את המיקומים אך לא נפעילם.
10. יש אי-עקביות בשמות רגיסטרי compare של הטיימר (`BTCCRx/BTCLx` לעומת `BTCMPRx`); נמפה את השמות לפני המימוש.

## כללי עבודה ועדכון

1. לא משנים את תיקיות המקור: `מעבדה קודמת שלנו`, `קבצים מהמדריך` ו-`Benchmark apps`.
2. כל מימוש נעשה בעץ עבודה נפרד.
3. לא עוברים שלב לפני ששער היציאה של השלב הקודם עבר.
4. לכל רכיב חדש כותבים unit test לפני אינטגרציה.
5. כל כשל benchmark נרשם עם seed/input, cycle, PC ו-waveform רלוונטי.
6. אחרי כל milestone שומרים checkpoint ומעדכנים את מסמך המעקב.
7. בתחילת כל סשן עבודה נציג: שלב נוכחי, מה הושלם, מה הפעולה הבאה ומה חסום.
8. בונוסים לא מתחילים לפני ששלב 10 של מערכת החובה הושלם.

## הגדרת Done לפרויקט החובה

הפרויקט ייחשב גמור רק כאשר כל התנאים הבאים מתקיימים:

- כל שלבי 0-11 מסומנים `[x | timestamp]` או שסעיף שאינו רלוונטי מתועד במפורש.
- כל ה-benchmarks עוברים ב-ModelSim ותוצאת DTCM תואמת ל-RARS.
- ה-MCU פועל בפועל על DE10-Standard.
- קיימות לכידות SignalTap שמוכיחות GPIO ופסיקות.
- דוחות Area, Fmax ו-Power מלאים ומצורפים לדוח.
- חבילת ההגשה הנקייה מתקמפלת מחדש ללא תלות בנתיבים מקומיים.

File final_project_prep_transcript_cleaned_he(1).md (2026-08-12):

# מפגש הכנה – פרויקט סופי RV32IM-based MCU

> **סוג הקובץ:** תמלול עברית מתוקן וערוך לקריאה.  
> **מקורות:** פלט התמלול האוטומטי שהועלה + קובץ הגדרת הפרויקט.  
> **הערת עריכה:** לא בוצעה האזנה חוזרת לקובץ השמע המקורי. התיקון נעשה לפי ההקשר, לפי המונחים הטכניים של הפרויקט ולפי קובץ ההגדרה. הושמטו חזרות, רעשי שיחה ומשפטים שלא תרמו להבנת החומר.

---

## תוכן עניינים

1. [מטרת הפרויקט](#1-מטרת-הפרויקט)
2. [מהו MCU?](#2-מהו-mcu)
3. [סדר העבודה והבונוסים](#3-סדר-העבודה-והבונוסים)
4. [מרחב הכתובות ו־Memory-Mapped I/O](#4-מרחב-הכתובות-וmemory-mapped-io)
5. [Divider Accelerator](#5-divider-accelerator)
6. [ממשקי הקלט/פלט של ה־FPGA](#6-ממשקי-הקלטפלט-של-הfpga)
7. [GPIO, GPO ו־GPI](#7-gpio-gpo-וgpi)
8. [דוגמאות Assembly ומיפוי כתובות](#8-דוגמאות-assembly-ומיפוי-כתובות)
9. [בדיקת המחלק ו־Verification](#9-בדיקת-המחלק-וverification)
10. [רכיבים פריפריאליים עם פסיקות](#10-רכיבים-פריפריאליים-עם-פסיקות)
11. [Basic Timer](#11-basic-timer)
12. [Synchronizer ו־Clock Domain Crossing](#12-synchronizer-וclock-domain-crossing)
13. [Interrupt Controller](#13-interrupt-controller)
14. [Interrupt Vector Table ופרוטוקול שירות פסיקה](#14-interrupt-vector-table-ופרוטוקול-שירות-פסיקה)
15. [Documentation, PPA ודרישות סיום](#15-documentation-ppa-ודרישות-סיום)
16. [בונוסים: Pipeline ו־UART](#16-בונוסים-pipeline-וuart)
17. [נספח: מונחים וכתובות](#17-נספח-מונחים-וכתובות)

---

# 1. מטרת הפרויקט

הפרויקט הסופי עוסק בבנייה של **MCU על בסיס ליבת RISC-V**, כלומר מערכת שמורכבת מליבת מעבד, זיכרונות, רכיבים פריפריאליים ומאיצי חומרה. במהלך הקורס עברנו דרך מספר מעבדות, והמטרה של הפרויקט היא לחבר את הידע שנצבר למערכת אחת שלמה.

הפרויקט הבסיסי מבוסס על ליבת **RV32IM single-cycle**. כלומר, ללא בונוסים, נקודת המוצא היא הליבה שעבדנו איתה במעבדה 5 חלק 1. בנוסף, קיימות שתי אפשרויות בונוס מרכזיות:

1. **העברת הליבה ל־pipeline** במקום single-cycle.
2. **הוספת רכיב תקשורת**, כלומר USART במצב UART.

הרעיון המרכזי הוא לא רק לקבל ציון, אלא לבנות ידע מוכח וניסיון מעשי בתחומים שקשורים ל־Chip Design, ארכיטקטורת מחשבים, RTL ו־FPGA. מי שמחפש עבודה בתחום יכול להשתמש בפרויקט הזה כחלק מתיק עבודות, בתנאי שהוא באמת מבין את המימוש ולא רק מחבר קוד בצורה טכנית.

---

# 2. מהו MCU?

MCU הוא קיצור של **Microcontroller Unit**. באופן כללי, MCU מורכב מ־CPU core שאליו מחוברים זיכרונות, רכיבים פריפריאליים, מערכת שעונים ולעיתים גם מאיצי חומרה.

במקרה שלנו, הליבה היא ליבת **RISC-V / RV32IM**. הליבה מחוברת לשני זיכרונות נפרדים, בגישה שמתאימה לארכיטקטורת **Harvard**:

- **ITCM** – זיכרון פקודות / code segment.
- **DTCM** – זיכרון נתונים / data segment.

הליבה עצמה מתקשרת עם הזיכרונות והרכיבים דרך ממשקים שניתן לחשוב עליהם בתור שלושה Buses עיקריים:

- **Control Bus** – קווי בקרה, למשל Load / Store / MemRead / MemWrite.
- **Address Bus** – הכתובת של הנתון או הרכיב שאליו פונים.
- **Data Bus** – המידע עצמו שעובר בין הליבה, הזיכרון והרכיבים.

כאשר מבצעים כתיבה לזיכרון או כתיבה ל־Register File, למעשה משנים את ה־state של המעבד או של המערכת. לדוגמה:

- כתיבה ל־Register File נקראת **write-back**.
- כתיבה לזיכרון הנתונים נקראת **memory write**.
- כתיבה לרכיב פריפריאלי מתבצעת דרך Memory-Mapped I/O.

בנוסף לליבה ולזיכרונות, ה־MCU כולל רכיבים פריפריאליים כמו GPIO, טיימר, בקר פסיקות ורכיב תקשורת. אפשר גם לחבר מאיץ חומרה, למשל מחלק, שהוא רכיב ייעודי שמבצע פעולה ספציפית מהר יותר או בצורה נוחה יותר מאשר מימוש מלא בתוך ה־CPU.

---

# 3. סדר העבודה והבונוסים

ההדגשה החשובה של המרצה הייתה שסדר העבודה חייב להיות:

1. קודם כול מסיימים את כל הדרישות הבסיסיות של הפרויקט.
2. רק אחרי שהפרויקט הבסיסי עובד, עוברים לבונוסים.
3. לא מתחילים מבונוס לפני שיש מערכת בסיסית תקינה.

הסיבה לכך היא שהבונוסים מוסיפים מורכבות. אם מתחילים מהם מוקדם מדי, אפשר להגיע לסוף בלי מערכת בסיסית שעומדת בדרישות. לכן קודם צריך לבנות MCU עובד עם single-cycle core, זיכרונות, GPIO, טיימר, פסיקות ובדיקות בסיסיות. רק לאחר מכן ניתן לשקול מעבר ל־pipeline או הוספת תקשורת UART.

---

# 4. מרחב הכתובות ו־Memory-Mapped I/O

המערכת משתמשת בגישת **Memory-Mapped I/O**. כלומר, רכיבים פריפריאליים מקבלים כתובות במרחב הכתובות של הנתונים, והמעבד פונה אליהם באמצעות פקודות Load ו־Store בדיוק כמו שהוא פונה לזיכרון.

מרחב הכתובות מחולק כך:

- מכתובת `0x0000` ועד `0x1FFC` – פנייה ל־**DTCM**, כלומר זיכרון הנתונים.
- מכתובת `0x2000` ואילך – פנייה ל־**SFR / Memory-Mapped I/O**, כלומר רגיסטרים של רכיבים פריפריאליים.

הכתובת שנמצאת על ה־Address Bus קובעת למי המעבד פונה:

- אם הכתובת בתחום של DTCM, הפעולה היא מול זיכרון הנתונים.
- אם הכתובת בתחום של I/O, הפעולה היא מול רכיב פריפריאלי.

כל רכיב פריפריאלי מזהה בעצמו אם הכתובת שעל ה־Bus שייכת לו. אם כן, הוא מפעיל את עצמו באמצעות **Chip Select**. אם לא, הוא נשאר במצב Disable ולא מגיב ל־Bus.

לכן המידע “למי פונים” נמצא בכתובת. ה־Decoder של המערכת מקבל את הביטים הרלוונטיים של הכתובת ומדליק Chip Select מתאים עבור רכיב אחד בלבד.

---

# 5. Divider Accelerator

ב־RV32IM, האות `M` מציינת את הרחבת הכפל והחילוק של RISC-V. במעבדה כבר מימשנו מכפל, אבל בפרויקט יש צורך גם במחלק. המחלק בפרויקט מחובר כ־**Accelerator** צמוד לליבה, ולא כרכיב פריפריאלי רגיל.

המחלק מבצע פעולת חילוק במספרים שלמים בלתי־חתומים (**Unsigned Integer Division**). הוא מקבל שני אופרנדים:

- Dividend – המחולק.
- Divisor – המחלק.

והוא מפיק שני ערכים:

- **Quotient** – המנה, עבור פקודת `DIV`.
- **Remainder** – השארית, עבור פקודת `REM`.

המחלק הוא רכיב **multi-cycle**. כלומר, הוא לא מסיים את הפעולה במחזור שעון אחד של הליבה. במקרה שלנו, עבור אופרנדים של 32 ביט, המחלק צריך 32 מחזורי שעון של `DIVCLK`.

היתרון הוא שהמחלק עובד בדומיין שעון מהיר יותר מהשעון של ליבת ה־single-cycle. בגלל שה־critical path של המחלק קצר יחסית, ניתן להריץ אותו ב־Fmax גבוה יותר. לכן למרות שהוא multi-cycle, הוא עדיין יכול להסתיים מהר יחסית ביחס לזמן של ליבת ה־CPU.

כאשר מגיעה פקודת `DIV` או `REM`:

1. המחלק מתחיל לעבוד.
2. קו `Busy` עולה.
3. ה־PC נעצר, כלומר הליבה ממתינה.
4. כשהמחלק מסיים, `Busy` יורד.
5. התוצאה, כלומר quotient או remainder, עוברת ל־write-back.
6. ה־PC משתחרר וממשיך לפקודה הבאה.

כל עוד `Busy=1`, המעבד לא יכול להמשיך לפקודה הבאה, כי תוצאת החילוק עדיין לא מוכנה.

---

# 6. ממשקי הקלט/פלט של ה־FPGA

בכרטיס ה־FPGA קיימים רכיבי קלט/פלט פיזיים שניתן לחבר למערכת:

- switches – מתגים.
- pushbuttons – לחצנים.
- LEDs – נורות.
- 7-segment displays – תצוגות HEX.
- expansion header – פינים חיצוניים לחיבור רכיבים נוספים.

בפרויקט משתמשים ברכיבים אלו דרך ממשקי GPIO. הרעיון הוא שהליבה לא “יודעת” ישירות מהו LED או מהו switch; היא רק מבצעת Load / Store לכתובות מוגדרות. הרכיב הפריפריאלי שמחובר לכתובת המתאימה הוא זה שמתרגם את הכתיבה או הקריאה לפעולה פיזית מול הכרטיס.

---

# 7. GPIO, GPO ו־GPI

GPIO הוא קיצור של **General Purpose Input Output**. בפרויקט מפשטים את המימוש ומפרידים בין רכיבי פלט לרכיבי קלט:

- **GPO – General Purpose Output**: רכיב פלט, למשל LEDs או 7-segment displays.
- **GPI – General Purpose Input**: רכיב קלט, למשל switches או pushbuttons.

יש שני סוגים עיקריים של GPO:

## 7.1 GPO עבור LEDs

זהו הסוג הפשוט ביותר. הערך שנכתב מה־Data Bus נשמר ברגיסטר, והיציאות של הרגיסטר מחוברות ישירות ל־LEDs. לכן אם המעבד כותב ערך מסוים לכתובת של `PORT_LEDR`, אותו ערך מופיע על ה־LEDs.

במימוש חומרה טיפוסי:

1. ה־Address Decoder מזהה שהכתובת שייכת ל־PORT_LEDR.
2. מתקבל `Chip Select` מתאים.
3. אם זו פעולת Store, כלומר `MemWrite=1`, הערך מה־Data Bus נכתב ל־Latch / Register.
4. היציאות של הרגיסטר מחוברות ל־LEDs.
5. אם זו פעולת Load, ניתן לקרוא חזרה את הערך שנשמר ברגיסטר.

## 7.2 GPO עבור 7-Segment Displays

ב־7-segment אי אפשר תמיד לחבר את הערך ישירות לתצוגה. צריך לבצע המרה בין ערך בינארי לבין קוד ההדלקה של מקטעי התצוגה. לכן בתוך ה־GPO של ה־HEX יש גם **7-segment encoder**.

במקום לכתוב באסמבלי קוד שממיר את הערך לכל מקטעי ה־7-segment, ניתן לממש את ההמרה בחומרה בתוך רכיב ה־GPO. זה מוריד מורכבות מהתוכנה ומעביר אותה לחומרה.

בחלק מהכתובות קיימת הפרדה לפי `A0`:

- אם `A0=0`, הכתיבה היא ל־HEX אחד בזוג.
- אם `A0=1`, הכתיבה היא ל־HEX השני בזוג.

לכן כתובות כמו `0x2004` ו־`0x2005` יכולות להתייחס לשני HEX שונים, עם רזולוציה של Byte Address.

## 7.3 GPI עבור Switches

GPI הוא רכיב קלט. לדוגמה, `PORT_SW` מאפשר לקרוא את מצב המתגים. כאשר המעבד מבצע Load מהכתובת של `PORT_SW`, הערך של המתגים עובר דרך Buffer / Tri-State אל ה־Data Bus ונקרא על ידי המעבד.

פעולת Store ל־GPI אינה רלוונטית, כי מדובר ברכיב קלט בלבד.

---

# 8. דוגמאות Assembly ומיפוי כתובות

בקוד האסמבלי משתמשים בקובץ מיפוי שמגדיר קבועים עבור הכתובות. זה דומה ל־`#define` בשפת C או C++, או ל־directive שמאפשר לקומפיילר / assembler להחליף שם סימבולי בערך מספרי.

לדוגמה, במקום לכתוב בכל פעם את הכתובת `0x2000`, מגדירים שם כמו `PORT_LEDR`. כך הקוד קריא יותר, ואם הכתובת משתנה, צריך לעדכן אותה במקום אחד בלבד.

בדוגמאות הקוד הוצגו כמה נקודות חשובות:

- ב־RISC-V יש הבדל בין קבועים של 12 ביט לבין קבועים של 20 ביט.
- עבור כתובות גדולות יחסית, בדרך כלל צריך קודם לטעון את הכתובת לרגיסטר, ורק אחר כך לבצע Store או Load.
- כדי לראות שינוי בעין אנושית על LEDs או HEX, מוסיפים Delay.
- הערך של ה־Delay שונה בין הרצה ב־RARS / ModelSim לבין הרצה אמיתית על FPGA.

## 8.1 דוגמה ראשונה – כתיבה ל־LEDs ול־HEX

האפליקציה הראשונה כותבת ערך שהולך ועולה, ושולחת אותו לכל רכיבי הפלט:

- LEDs.
- HEX0 עד HEX5.

הלולאה מבצעת:

1. כתיבה לערכי הפלט.
2. Delay.
3. הגדלת הערך.
4. חזרה לתחילת הלולאה.

## 8.2 דוגמה שנייה – קריאת Switches ו־Masking

האפליקציה השנייה משתמשת גם ב־switches. כדי לבדוק switch מסוים מתוך מערך של מתגים, משתמשים ב־**masking**.

לדוגמה, כדי לבדוק את `switch 0`:

1. קוראים את כל ערך ה־PORT של ה־switches.
2. מבצעים AND עם `1`.
3. אם התוצאה שונה מ־0, סימן ש־switch 0 במצב ON.
4. אם התוצאה היא 0, סימן ש־switch 0 במצב OFF.

אותו רעיון משמש גם עבור `switch 1`, רק עם מסכה אחרת.

הקוד שהוצג מבצע לולאה שבה:

- אם `switch 0` דולק, הערך עולה ב־1 ומודפס לתצוגות.
- אם `switch 1` דולק, הערך יורד ב־1 ומודפס לתצוגות.
- אם אף אחד מהם לא דולק, הלולאה ממשיכה לבדוק שוב.

---

# 9. בדיקת המחלק ו־Verification

המחלק נבדק בעזרת אפליקציה שמבצעת פעולות על מערכים. הוצגו מערכי מקור ומערכי תוצאה, והפעולות המרכזיות הן:

- `DIV` – חילוק, כלומר הפקת המנה.
- `REM` – הפקת השארית.
- `MUL` – כפל, שמבוצע על ידי המכפל שכבר קיים בליבה.

כדי לוודא שהמחלק עובד נכון, מבצעים **verification** מול מודל ייחוס:

1. כותבים או מריצים קוד C שמבצע את אותן פעולות.
2. מפיקים תוצאות צפויות, כלומר golden model.
3. יוצרים פורמט שמתאים לטעינה ל־DTCM.
4. מריצים את האפליקציה ב־RARS / ModelSim / על המערכת.
5. משווים את התוצאות בפועל לתוצאות הצפויות.

המרצה הדגיש שבלי verification מסודר קשה מאוד לעבוד, כי אי אפשר לדעת אם שגיאה מגיעה מהמחלק, מה־Assembly, מה־Memory Map או מהחיבור לליבה.

בנוסף הוצגו שתי אפשרויות לקוד:

- קוד שנוצר בעזרת GCC.
- קוד Assembly ידני קצר ויעיל יותר.

הקוד של GCC עובד, אבל הוא יכול להיות ארוך ומסורבל יחסית, כי קומפיילר כללי עובד לפי תבניות ולא תמיד מנצל ידע ספציפי על האפליקציה. בקוד Assembly ידני אפשר לכתוב לולאה ממוקדת שמקדמת pointers, מבצעת `DIV`, `REM`, `MUL`, כותבת את התוצאות לזיכרון וממשיכה עד סיום המערכים.

---

# 10. רכיבים פריפריאליים עם פסיקות

לאחר רכיבי GPIO בסיסיים, עוברים לרכיבים פריפריאליים שיש להם יכולת לבקש שירות מהמעבד באמצעות **interrupt**.

רכיב עם פסיקה הוא רכיב שלא רק המעבד יכול לדבר איתו, אלא גם הרכיב יכול להודיע למעבד:

> “אני צריך שירות, יש לי אירוע שצריך לטפל בו.”

במקום שהמעבד יבדוק כל הזמן את מצב הרכיב בלולאה, הרכיב מרים בקשת פסיקה. כאשר הפסיקה מאושרת, המעבד עוצר את הרצף הרגיל של הקוד וקופץ ל־ISR – Interrupt Service Routine.

הרכיבים המרכזיים עם פסיקה בפרויקט הם:

- `KEY[3:1]` – לחצנים.
- `Basic Timer`.
- `USART` – עבור בונוס תקשורת.
- `Interrupt Controller`.

## 10.1 לחצנים KEY[3:1]

`KEY0` משמש כ־System Reset, ולכן עבור פסיקות משתמשים ב־`KEY1`, `KEY2`, `KEY3`.

ה־pushbuttons עוברים **debounce** בחומרה. בזמן לחיצה ושחרור יש רעידות מכניות, כלומר האות אינו משתנה בצורה נקייה מיד. מעגל debounce / Schmitt Trigger מסנן את הרעידות ומייצר אות נקי.

בפרויקט מפשטים את העבודה כך שכל בקשות הפסיקה ייווצרו כאירוע של עלייה מ־0 ל־1. כלומר, משתמשים ב־rising edge כ־event שמבקש interrupt.

---

# 11. Basic Timer

ה־Basic Timer הוא רכיב פנימי שמאפשר לעבוד מול ציר הזמן. הוא מרחיב את מה שנעשה במעבדה 4 ותומך בכמה אופני עבודה.

## 11.1 Compare Mode

ב־Compare Mode, הטיימר משווה את ערך המונה הפנימי `BTCNT` לערכים שנכתבים לרגיסטרי השוואה, למשל `BTCMPR0` או `BTCMPR1`.

כאשר הערך של הטיימר מגיע לערך ההשוואה, נוצר event. בצורה הזו ניתן לייצר פסיקות מחזוריות במרווחי זמן מוגדרים.

## 11.2 Output Compare Mode / PWM

ב־Output Compare Mode משתמשים ברגיסטרי ההשוואה כדי לייצר אות PWM.

בפשטות:

- רגיסטר אחד יכול לקבוע את זמן המחזור.
- רגיסטר שני יכול לקבוע את ה־duty cycle או את נקודת המעבר של האות.

כך ניתן לייצר אות דיגיטלי מחזורי שמייצג PWM.

## 11.3 Input Capture Mode

ב־Input Capture Mode, אירוע חיצוני או פנימי גורם ללכידת ערך הטיימר לתוך רגיסטר capture, למשל `BTCAPR`.

לדוגמה, אם מוגדר trigger על rising edge, אז ברגע שהאירוע מתרחש:

1. ערך `BTCNT` הנוכחי נלכד.
2. הערך נשמר ב־`BTCAPR`.
3. ניתן לקרוא אותו מאוחר יותר מהתוכנה.

כך ניתן לדעת מתי אירוע התרחש על ציר הזמן.

---

# 12. Synchronizer ו־Clock Domain Crossing

ה־Divider Accelerator עובד בדומיין שעון מהיר יותר מהליבה. לכן יש מעבר בין שני Clock Domains:

- דומיין איטי יחסית – שעון ה־CPU / single-cycle core.
- דומיין מהיר יותר – `DIVCLK` של המחלק.

כאשר אות עובר מדומיין שעון אחד לדומיין שעון אחר, נדרש **Synchronizer** כדי למנוע בעיות metastability.

העיקרון הוא שלא שולחים אות קומבינטורי ישירות לדומיין שעון אחר. צריך לדגום ולסנכרן את האות באמצעות Flip-Flops, כך שהדומיין המקבל יקבל אות יציב שמתאים למשטר השעון שלו.

---

# 13. Interrupt Controller

בקר הפסיקות הוא רכיב מרכזי שמנהל את בקשות הפסיקה של המערכת. הוא מחובר כמו רכיב Memory-Mapped רגיל, כלומר ניתן לבצע אליו Load ו־Store, אבל בנוסף הוא יודע להרים בקשת פסיקה ל־CPU.

הרגיסטרים המרכזיים של בקר הפסיקות הם:

- `IE` – Interrupt Enable, רגיסטר אפשור מקומי של מקורות פסיקה.
- `IFG` – Interrupt Flag, רגיסטר דגלים שמציין אילו מקורות ביקשו פסיקה.
- `TYPE` – רגיסטר קריאה בלבד שמייצג את סוג הפסיקה / הכניסה המתאימה ב־Interrupt Vector Table.

כאשר מקור פסיקה מרים בקשה:

1. ה־flag המתאים ב־`IFG` עולה.
2. אם הביט המתאים ב־`IE` מאופשר, יש אפשור מקומי.
3. אם גם `GIE` מאופשר, יש אפשור גלובלי.
4. אם שניהם מאופשרים, ה־Interrupt Controller מרים בקשת פסיקה ל־CPU.

כלומר, כדי שפסיקה תקבל שירות נדרשים שני תנאים:

- אפשור מקומי ברמת המקור.
- אפשור גלובלי ברמת המערכת.

## Priority

אם כמה מקורות פסיקה מבקשים שירות בו־זמנית, יש צורך ב־priority. בקר הפסיקות משתמש ב־priority encoder כדי לבחור את המקור בעל העדיפות הגבוהה ביותר.

ה־`TYPE` מייצג את המקור שנבחר. כאשר יש כמה בקשות pending, הערך של `TYPE` יהיה הערך של מקור הפסיקה בעל העדיפות הגבוהה ביותר.

---

# 14. Interrupt Vector Table ופרוטוקול שירות פסיקה

ה־Interrupt Vector Table היא טבלה בזיכרון שמכילה כתובות של פונקציות שירות פסיקה, כלומר Labels של ISR.

לדוגמה:

- Reset מצביע ל־`main` או לכתובת התחלת התוכנית.
- `KEY1` מצביע ל־ISR של `KEY1`.
- `KEY2` מצביע ל־ISR של `KEY2`.
- Timer מצביע ל־ISR של הטיימר.
- UART RX / TX מצביעים ל־ISR של רכיב התקשורת, אם מממשים את הבונוס.

כאשר מתקבלת פסיקה, המטרה היא שה־CPU יקפוץ לכתובת של ה־ISR המתאים, יבצע את הקוד שלו, ואז יחזור להמשך התוכנית.

## 14.1 כניסה לשירות פסיקה

כאשר קו הפסיקה עולה מ־0 ל־1, ה־Control Unit מבצע פרוטוקול multi-cycle שאינו חלק מהפקודות הרגילות בזיכרון. במהלך הפרוטוקול:

1. `GIE` יורד ל־0, כדי לחסום פסיקות נוספות בזמן שירות הפסיקה.
2. נשמרת כתובת החזרה, כלומר ה־PC הבא שאליו צריך לחזור אחרי השירות.
3. נקרא הערך של `TYPE`.
4. לפי `TYPE`, נשלפת מה־Vector Table הכתובת של ה־ISR המתאים.
5. ה־PC מקבל את כתובת ה־ISR.
6. המעבד מתחיל לבצע את פונקציית השירות.

המרצה תיאר זאת כאמולציה פנימית של פעולות בסגנון Load ו־JALR: לא מדובר בפקודה שנמצאת בזיכרון, אלא בפרוטוקול חומרתי בתוך ה־Control Unit שמביא את כתובת ה־ISR ומעדכן את ה־PC.

## 14.2 יציאה משירות פסיקה

בסוף פונקציית השירות מופיעה פקודת `RTI` – Return from Interrupt.

הפקודה מבצעת:

1. חזרה לכתובת שנשמרה לפני הכניסה ל־ISR.
2. החזרת `GIE` ל־1, כדי לאפשר שוב פסיקות.

כך המעבד חוזר להמשך התוכנית הרגילה אחרי שסיים לשרת את מקור הפסיקה.

---

# 15. Documentation, PPA ודרישות סיום

בסוף הפרויקט צריך להגיש גם Documentation מסודר. בין היתר צריך להתייחס ל־PPA:

- **Power** – צריכת הספק.
- **Performance** – ביצועים / תדר / Fmax.
- **Area** – משאבי חומרה / utilization.

יש לבצע PPA עבור שלבים שונים של המערכת, למשל:

1. מערכת עם GPIO בלבד.
2. מערכת MCU מלאה.
3. מערכת עם בונוסים, אם בוצעו.

בנוסף, יש להראות שהמערכת עוברת קומפילציה, נטענת ל־FPGA ונבדקת מול אפליקציות benchmark מתאימות.

---

# 16. בונוסים: Pipeline ו־UART

בסיום הייתה שאלה לגבי הבונוסים. המרצה הדגיש שהבונוסים מיועדים בעיקר למי שרוצה לקחת את הפרויקט קדימה ולהפוך אותו למשהו שניתן להציג בתיק עבודות או בראיון עבודה.

## 16.1 בונוס Pipeline

הבונוס הראשון הוא מעבר מליבת single-cycle לליבת pipeline. זה מומלץ מאוד למי שסיים את הפרויקט הבסיסי ורוצה להעמיק בארכיטקטורת מעבדים.

אבל התנאי ברור:

- קודם מסיימים את הפרויקט הבסיסי.
- רק לאחר מכן פונים לבונוס.
- המרצה מתכנן לתת הרצאה ייעודית שמסבירה איך להעביר את הליבה, המאיץ והרכיבים הפריפריאליים מ־single-cycle ל־pipeline.

## 16.2 בונוס UART / USART

הבונוס השני הוא רכיב תקשורת. במקרה הזה מקבלים קוד HDL מוכן של מודול תקשורת, והמטרה היא להבין אותו, להתאים אותו ולחבר אותו כ־Memory-Mapped Peripheral ל־MCU.

המרצה ציין שמי שרוצה לבצע את הבונוס הזה צריך ללמוד לפחות את הבסיס של UART / תקשורת טורית. לאחר מכן ניתן יהיה לעבור בהרצאה על החיבור למערכת.

גם כאן התנאי הוא לסיים קודם את בסיס הפרויקט. לא כל מי שרוצה בונוס יקבל אותו אוטומטית; צריך להראות שיש בסיס עובד ושיש זמן ויכולת להמשיך.

---

# 17. נספח: מונחים וכתובות

## 17.1 מונחים מרכזיים שתוקנו בתמלול

| הופיע בתמלול האוטומטי | נוסח מתוקן |
|---|---|
| מאבד / מאבדות | מעבד / מעבדות |
| ריסק פייב / RISC5 | RISC-V |
| סינגל סייקל | single-cycle |
| פייפליין / פייפלנט | pipeline |
| טריבוס | Tri-Bus |
| דאטה בס / אדרס / קונטרול | Data Bus / Address / Control |
| ג׳יפי או / ג׳יפיור | GPO |
| ג׳יפי איי | GPI |
| אקסלרטור / מעיץ | Accelerator / מאיץ חומרה |
| דיב / רם / רנמנט | DIV / REM / remainder |
| רייד בק | write-back |
| אינטרפט / אינטראפ | interrupt |
| דיבאונס | debounce |
| סינקרונייזר | Synchronizer |
| פיוטי / פריאוריטי דיקורדר | priority encoder |
| רט-איי | RTI |

## 17.2 Memory Map כללי

| תחום | כתובות |
|---|---|
| DTCM – זיכרון נתונים פיזי | `0x0000` עד `0x1FFC` |
| Memory-Mapped I/O / SFR | מ־`0x2000` עד `0x3FFC` |

## 17.3 GPIO ללא פסיקות

| שם התקן | כתובת | כיוון | הערה |
|---|---:|---|---|
| `PORT_LEDR` | `0x2000` | GPO | `LEDR7–LEDR0` |
| `PORT_HEX0` | `0x2004` | GPO | Byte address |
| `PORT_HEX1` | `0x2005` | GPO | Byte address |
| `PORT_HEX2` | `0x2008` | GPO | Byte address |
| `PORT_HEX3` | `0x2009` | GPO | Byte address |
| `PORT_HEX4` | `0x200C` | GPO | Byte address |
| `PORT_HEX5` | `0x200D` | GPO | Byte address |
| `PORT_SW` | `0x2010` | GPI | `SW7–SW0` |

## 17.4 רכיבים עם יכולת פסיקה

| שם התקן / רגיסטר | כתובת | רכיב |
|---|---:|---|
| `PORT_PB` | `0x2014` | `KEY[3:1]` |
| `UTCL` | `0x2018` | USART |
| `RXBF` | `0x2019` | USART |
| `TXBF` | `0x201A` | USART |
| `BTCTL1` | `0x201C` | Basic Timer |
| `BTCTL2` | `0x201D` | Basic Timer |
| `BTCMPR0` | `0x2020` | Basic Timer |
| `BTCMPR1` | `0x2024` | Basic Timer |
| `BTCAPR` | `0x2028` | Basic Timer |
| `IE` | `0x202C` | Interrupt Controller |
| `IFG` | `0x202D` | Interrupt Controller |
| `TYPE` | `0x202E` | Interrupt Controller |

## 17.5 נקודות חשובות לזכור

- הפרויקט הבסיסי מבוסס על `RV32IM single-cycle`.
- מעבר ל־`pipeline` הוא בונוס נפרד.
- רכיב התקשורת `USART` במצב `UART` הוא בונוס נוסף.
- `KEY0` משמש כ־System Reset.
- `KEY1–KEY3` יכולים לשמש כמקורות פסיקה.
- ה־Divider Accelerator הוא `multi-cycle` ומחזיר `quotient` או `remainder`.
- בזמן שה־Divider מסמן `Busy`, ה־PC נעצר.
- ה־Interrupt Controller משתמש ב־`IE`, `IFG`, `TYPE` וב־`GIE`.
- שירות פסיקה מתבצע דרך ISR, ויציאה ממנו מתבצעת בעזרת `RTI`.

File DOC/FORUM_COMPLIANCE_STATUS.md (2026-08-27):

# סטטוס התאמה לשאלות ותשובות הפורום

עודכן: 27.08.2026 IDT

## שער שחרור

**הענף הזה טרם עבר אימות פיזי על DE10-Standard.** הוא עבר סימולציה,
סינתזה ותזמון בלבד. האימות הפיזי המתועד ב־`main` בוצע לפני השינויים האלה
ואינו מהווה הוכחה עבור הענף החדש.

## התאמות שבוצעו

| נושא מהפורום | מצב בענף |
|---|---|
| שלושה שעונים מ־PLL נפרדים | שלושה מופעים לוגיים: MCLK=20MHz, SMCLK=20MHz, DIVCLK=50MHz; reset מחכה לכל ה־locks. Quartus משתף פיזית את שני מופעי ה־20MHz הזהים. |
| DATA BUS משותף ודו־כיווני | CPU, DTCM, MMIO ו־TYPE נוהגים על bus אחד; כל מי שאינו בעלים מוציא `Z`. |
| TYPE בזמן INTA | TYPE נהוג על DATA BUS בזמן INTA ולא על address bus. |
| KEY1–KEY3 | מיפוי bit0/1/2 נשמר; אין debounce או synchronizer נוסף; אירוע יחיד בשחרור 0→1. |
| IFG ו־IE | אירוע מגדיר IFG רק אם IE פעיל; ביטול IE מנקה IFG ולא נשמר אירוע מוסווה. |
| BTCAPR | רגיסטר 32-bit לקריאה וכתיבה. |
| BTCTL2 | ארבעת הביטים העליונים נשארים read-only; כתיבה משפיעה רק על הנמוכים. |
| HEX זוגי/אי־זוגי | בחירת HEX0/1, HEX2/3 ו־HEX4/5 נעשית במפורש בעזרת A0. |
| פסיקה באמצע DIV | בדיקה ייעודית מוכיחה ש־DIV מסתיים ונכתב חזרה לפני INTA, ולאחר ISR הזרימה ממשיכה. |
| CDC של המחלק | request/ack toggle, שני DFF ביעד בכל כיוון, ו־payload יציב לאורך ה־handshake. |

## תוצאות אוטומטיות

- ModelSim: כל תשעת יישומי הייחוס עברו (`9/9`).
- ModelSim: בדיקות interconnect/GPIO/timer/pushbuttons/interrupt controller עברו.
- ModelSim: `STAGE 7 DIVIDER/INTERRUPT ORDER PASS`.
- Quartus Prime Lite 21.1 Full Compilation: `0 errors`.
- Synthesis: נמצאו שלושה מופעי PLL לוגיים.
- Fitter: `2,080 ALMs`, ‏`2,029 registers`, ‏`4 DSP blocks`.
- TimeQuest: fully constrained, `0 errors`, `0 warnings`, ‏TNS=`0`.
- Worst setup slack: `+0.474 ns`; worst hold slack: `+0.160 ns`.

## אימות פיזי שנותר

נוהל הבדיקה המלא, כולל build, צריבה, תוצאות צפויות ותבנית ראיות, נמצא
ב־[`חשוב_הוראות_אימות_פיזי_על_הכרטיס.md`](../חשוב_הוראות_אימות_פיזי_על_הכרטיס.md)
בשורש המאגר.

יש לצרוב את ה־SOF שנבנה מהענף ולחזור על ארבעת תרחישי המעבדה:

1. KEY0/reset ואתחול HEX/מצב.
2. KEY1/compare interrupts וקצבי הספירה.
3. KEY2/PWM ו־LEDR8.
4. KEY3/REM ו־DIV, כולל חזרה תקינה לפעילות לאחר כל ISR.

רק לאחר שכל ארבע הבדיקות יעברו ניתן להסיר את אזהרת "לא אומת פיזית".

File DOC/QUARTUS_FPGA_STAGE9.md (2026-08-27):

# שלב 9 — Quartus ו־DE10-Standard

עודכן: 26.08.2026

> **אזהרת ענף forum-compliance (27.08.2026):** ה־RTL החדש עבר ModelSim,
> Quartus ו־TimeQuest, אך **טרם נצרב או אומת פיזית**. תוצאות הכרטיס בהמשך
> פרק זה הן ראיות היסטוריות של `main` בלבד ואינן מאמתות את הענף החדש.
> נוהל הקבלה לענף החדש נמצא בשורש המאגר:
> `חשוב_הוראות_אימות_פיזי_על_הכרטיס.md`.

## מצב build

- Quartus Prime Lite 21.1, רכיב `5CSXFC6D6F31C6`, top-level `RV32IMscMCU`.
- Full Compilation הסתיים בהצלחה: 0 errors.
- Analysis & Synthesis: 0 errors; Fitter: 0 errors; Assembler: 0 errors.
- TimeQuest לאחר תיקון ה־CDC constraints: 0 errors, 0 warnings.
- forum-compliance TimeQuest: fully constrained, 0 warnings; worst setup slack
  `+0.474 ns`, worst hold slack `+0.160 ns` בכל הפינות המסוכמות.
- SOF סופי: `Quartus/RV32IMscMCU/output_files/RV32IMscMCU.sof`.

## ניצול משאבים

| משאב | שימוש |
|---|---:|
| ALMs | 2,080 / 41,910 (5%) |
| Registers | 2,029 |
| Pins | 67 / 499 (13%) |
| Block memory | 131,072 bits (2%), 14 blocks |
| DSP | 4 / 112 (4%) |
| PLL | 3 logical instances; fitter shares the two phase-identical 20 MHz instances into 1 physical PLL |

כל 67 ה־I/O pins ממופים. אזהרת ה־Fitter לגבי I/O מתייחסת רק לכך שלא הוגדרו drive-strength ו־slew-rate מפורשים ל־LEDR/HEX; Quartus משתמש בברירות המחדל של `3.3-V LVTTL`. אזהרת עומק ה־DTCM צפויה: תמונת הקושחה מכילה 1024 מילים בתוך RAM של 2048 מילים, והחצי העליון מאותחל לאפס.

## קושחת ההדגמה

ה־SOF משתמש ב־`interrupt/test4` של המדריך:

- `KEY0` — reset פעיל־נמוך.
- `KEY1` — הפעלת compare interrupt ושינוי מחזור ההפרעה.
- `KEY2` — הפעלת PWM ושינוי duty cycle; ה־PWM נראה גם ב־`LEDR8`.
- `KEY3` — capture ומדידת זמני מערכי DIV/REM.
- `LEDR9` — חיווי של לחצן debounced פעיל.
- `SW8`, `SW9` — כניסות capture.

## build חוזר

מתוך `Quartus/RV32IMscMCU`:

```text
compile_stage9.cmd
verify_timing_stage9.cmd
```

הסקריפטים ממפים זמנית את שורש ה־workspace לכונן `V:` מפני ש־Quartus 21.1 משמיט את רכיב `Desktop` כאשר הוא מקבל את הנתיב הנוכחי ישירות. המיפוי מוסר בסיום.

## תוצאות הבדיקה ההיסטוריות על הכרטיס (`main` בלבד)

ב־26.08.2026 ה־SOF נטען דרך `DE-SoC [USB-1]` אל רכיב FPGA מספר 2 בשרשרת
ה־JTAG. האימות הפיזי עבר:

1. `KEY0` איפס את תצוגות ה־HEX ואת מצב הקושחה.
2. `KEY1` הפעיל compare interrupts, הדליק את `LEDR9` בזמן הלחיצה ועדכן את
   הספירה בקצבים המחזוריים 1, ‏0.5, ‏0.25 ו־0.125 שניות.
3. `KEY2` עצר את הספירה והפעיל PWM ב־`LEDR8`.
4. שתי לחיצות `KEY3` השלימו את מדידות REM ו־DIV; לאחר כל רצף `KEY1` חזר
   להפעיל את הספירה ללא קיפאון.

במהלך האימות תוקנו שני מעברים בין מצבי הטיימר בקובץ הקושחה הייעודי לכרטיס:
נוסף `BTCLR` בהפעלת PWM ובהפעלה מחדש של compare mode, כדי למנוע מצב שבו
`BTCNT` כבר עבר את ערך ההשוואה החדש. רגרסיית ModelSim המלאה עברה 9/9 לאחר
שני התיקונים, וה־SOF הסופי נבנה עם 0 שגיאות.

שער שלב 9 הושלם. שמירת ראיות SignalTap תבוצע בשלב 10.

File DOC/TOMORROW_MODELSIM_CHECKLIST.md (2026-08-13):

# תוכנית עבודה למחר — אימות ModelSim של שלבים 0–3

נוצר: 12.08.2026 21:58 IDT  
פרויקט: RV32IM single-cycle MCU עבור DE10-Standard

מטרת יום הבדיקה היא להריץ שבע בדיקות אוטומטיות, לפי הסדר, ולסגור רשמית
את שערי היציאה של שלבים 0–3. אין לבצע מחר בדיקת FPGA ואין לשנות קוד לפני
שמירת פרטי הכשל הראשון, אם יהיה כשל.

## 1. מה צריך להיות זמין

- מחשב עם ModelSim Intel FPGA Starter Edition.
- תיקיית הפרויקט המלאה בנתיב:
  `C:/Users/noam1/Desktop/VHDL Lab/Final proj`
- הקבצים `run_stage0_baseline.do` עד `run_stage3_divider_integration.do`
  בתיקייה `SIM/RV32IMscMCU`.
- מקום לשמור שבעה צילומי מסך ושבעת קובצי ה-log.
- אין צורך בכרטיס DE10-Standard במהלך הבדיקות האלה.
- אין צורך ליצור ModelSim Project גרפי; קובצי ה-`.do` מטפלים בספריית
  `work`, בקומפילציה, בפתיחת חלונות Wave ו-List ובהרצה.
- כל script שומר אוטומטית גם קובץ `*_list.do`, המשחזר את האותות ואת
  אפשרויות התצוגה של חלון List.

## 2. כללי עבודה חשובים

1. מריצים את הבדיקות לפי הסדר המופיע במסמך.
2. מריצים בכל פעם script אחד בלבד וממתינים לסיום.
3. הצלחה נקבעת רק לפי הודעת ה-PASS המדויקת ב-Transcript.
4. הודעת `Simulation stop requested` אחרי PASS היא תקינה: ה-testbench
   קורא ל-`std.env.stop` בסיום מוצלח.
5. אם מופיעים `Error`, ‏`Failure`, ‏`Fatal` או שאין PASS — הבדיקה נכשלה.
6. בכשל הראשון עוצרים. לא ממשיכים לבדיקה הבאה ולא מריצים מחדש לפני
   ששומרים את ה-log וה-Wave, כי הרצה חוזרת עשויה לדרוס את ה-log.
7. אין לערוך קובצי DUT, ‏TB, ‏`.do` או `.hex` בזמן יום הבדיקה.
8. לאחר PASS ודא שחלון List נפתח ושנוצר קובץ ה-`*_list.do` המתאים. אין
   צורך לבצע `File > Save Format` ידנית.

## 3. פתיחת סביבת העבודה

1. פתח ModelSim Intel FPGA Starter Edition.
2. בחר `File > Change Directory`.
3. עבור אל:

   ```text
   C:/Users/noam1/Desktop/VHDL Lab/Final proj/SIM/RV32IMscMCU
   ```

4. ודא שהנתיב הנוכחי ב-Transcript הוא התיקייה הזאת. אפשר להקליד:

   ```tcl
   pwd
   ```

5. ודא שבתיקייה מופיעים שבעת קובצי ה-`.do` ושקובצי `ITCM.hex` ו-`DTCM.hex`
   קיימים.

## 4. אם ModelSim אינו מוצא את ספריית Intel

חלק מבדיקות ה-CPU משתמשות ב-`altsyncram` ומפעילות את ModelSim עם
`-L altera_mf`. אם מתקבלת שגיאה כגון `Library altera_mf not found` או
שגיאה על `altsyncram`:

1. עצור את ההרצה.
2. בחר `Tools > Compile Simulation Libraries`.
3. בחר את ModelSim Intel FPGA ואת משפחת Cyclone V.
4. קמפל את ספריות הסימולציה.
5. חזור לתיקיית העבודה והריץ שוב את אותה בדיקה.

זו בעיית הגדרת כלי, לא כשל לוגי של הפרויקט. אם הקומפילציה של הספריות
נכשלת, שמור צילום ואת טקסט השגיאה ושלח אותם לפני המשך העבודה.

## 5. הבדיקות לפי הסדר

### בדיקה 1 — שלב 0: RV32I/MUL baseline ו-DTCM

- [ ] הרץ ב-Transcript:

  ```tcl
  do run_stage0_baseline.do
  ```

- [ ] ודא שמופיעה ההודעה:

  ```text
  STAGE 0 PASS: RV32I/MUL baseline and DTCM regression
  ```

- [ ] ב-Wave ודא שקיימים `sysclk`, ‏`divclk`, ‏`reset`, ‏`pc`,
  `instruction`, ‏`r1`, ‏`r2`, ‏`alu`, ‏`regwrite` ו-`memwrite`.
- [ ] שמור צילום שבו רואים את ה-Wave ואת הודעת ה-PASS.
- [ ] ודא שנוצר `stage0_baseline.log`.

מה ה-TB מוכיח: ה-benchmark מגיע ללולאת העצירה לפני timeout, נצפית לפחות
פקודת `MUL` אחת, תוצאת הכפל תואמת למכפלת 16 הביטים התחתונים, ונצפית לפחות
כתיבה אחת ל-DTCM.

### בדיקה 2 — שלב 1: Address decoder ו-read mux

- [ ] הרץ:

  ```tcl
  do run_stage1_interconnect.do
  ```

- [ ] ודא שמופיעה:

  ```text
  STAGE 1 INTERCONNECT PASS
  ```

- [ ] ב-Wave ודא שהאותות מוצגים ב-hex ושניתן לראות מעבר בין DTCM, ‏MMIO
  וכתובת שאינה ממומשת.
- [ ] שמור צילום ואת `stage1_interconnect.log`.

מה ה-TB מוכיח: byte address מומר נכון ל-word index של DTCM; כתובת MMIO
המלאה נשמרת; write-enable של DTCM ושל MMIO אינם פעילים יחד; ה-read mux
מחזיר את המקור הנכון; גישה לא ממומשת מסומנת ואינה פוגעת בזיכרון.

### בדיקה 3 — שלב 2: GPIO unit test

- [ ] הרץ:

  ```tcl
  do run_stage2_gpio_unit.do
  ```

- [ ] ודא שמופיעה:

  ```text
  STAGE 2 GPIO UNIT PASS
  ```

- [ ] ב-Wave בדוק reset, כתיבה ל-LEDR, כתובות HEX, יציאות HEX active-low,
  קריאת switches והאות `hit`.
- [ ] שמור צילום ואת `stage2_gpio_unit.log`.

מה ה-TB מוכיח: reset מנקה LEDR; כתיבת low byte עובדת; הכתובות הצמודות
והלא מיושרות של HEX נשמרות; הקידוד עבור A/F תקין; קריאת SW עוברת zero
extension; כתובת שאינה ממומשת אינה נתפסת בטעות על ידי GPIO.

### בדיקה 4 — שלב 2: GPIO integration עם test0

- [ ] הרץ:

  ```tcl
  do run_stage2_gpio_integration.do
  ```

- [ ] ודא שמופיעה:

  ```text
  STAGE 2 GPIO INTEGRATION PASS
  ```

- [ ] ב-Wave אתר כתיבות bus ל-LEDR ולששת ה-HEX.
- [ ] ודא שבסיום `LEDR=0x01`.
- [ ] שמור צילום ואת `stage2_gpio_integration.log`.

מה ה-TB מוכיח: benchmark `GPIO/test0` מבצע לפחות שתי כתיבות ל-LEDR,
שתי סדרות מלאות של כתיבות לששת צגי HEX, ומשאיר LEDR בערך הצפוי.

### בדיקה 5 — שלב 2: GPIO test1/test2 עם SW0

- [ ] הרץ:

  ```tcl
  do run_stage2_gpio_switch_benchmarks.do
  ```

- [ ] ודא שמופיעה:

  ```text
  STAGE 2 GPIO TEST1/TEST2 INTEGRATION PASS
  ```

- [ ] ב-Wave ודא ש-`switches` משתנה כך ש-SW0 פעיל.
- [ ] ודא ששני מופעי ה-benchmark כותבים `1` ל-LEDR וכותבים לכל ששת ה-HEX.
- [ ] שמור צילום ואת `stage2_gpio_switch_benchmarks.log`.

מה ה-TB מוכיח: גם `GPIO/test1` וגם `GPIO/test2` קוראים את SW0 ומגיבים אליו
נכון, ללא החלפה ידנית של קובצי הזיכרון.

### בדיקה 6 — שלב 3: Divider unit test

- [ ] הרץ:

  ```tcl
  do run_stage3_divider_unit.do
  ```

- [ ] ודא שמופיעה:

  ```text
  STAGE 3 DIVIDER UNIT PASS
  ```

- [ ] ב-Wave בדוק את הרצף `start` → `busy` → `done` ואת `operation`,
  `dividend`, ‏`divisor` ו-`result`.
- [ ] בפעולה רגילה אמורים להיראות בקירוב 32 מחזורי `divclk`; חלוקה באפס
  ו-overflow יכולים להסתיים מוקדם יותר.
- [ ] שמור צילום ואת `stage3_divider_unit.log`.

מה ה-TB מוכיח: `DIV`, ‏`DIVU`, ‏`REM`, ‏`REMU`, ערכים חיוביים ושליליים,
חלוקה באפס ו-`0x80000000 / -1` מחזירים את התוצאה הצפויה.

### בדיקה 7 — שלב 3: שילוב CPU/Divider

- [ ] הרץ:

  ```tcl
  do run_stage3_divider_integration.do
  ```

- [ ] ודא שמופיעה:

  ```text
  STAGE 3 CPU/DIVIDER INTEGRATION PASS
  ```

- [ ] ב-Wave בדוק את `pc`, ‏`instruction`, ‏`div_busy`, ‏`div_done`,
  `regwrite`, ‏`r1`, ‏`r2` ו-`result`.
- [ ] ודא חזותית שה-PC נשאר יציב בזמן `div_busy` וש-`regwrite` עבור תוצאת
  המחלק מתרחש רק עם `div_done`.
- [ ] שמור צילום ואת `stage3_divider_integration.log`.

מה ה-TB מוכיח: ה-benchmark מבצע בדיוק שמונה פעולות DIV ושמונה REM, הליבה
נעצרת בזמן העבודה, אין write-back מוקדם או כפול, וכל תוצאה תואמת לצפוי.

## 6. רשימת קובצי ה-log הצפויים

לאחר שכל הבדיקות עברו, בתיקיית `SIM/RV32IMscMCU` צריכים להופיע:

- [ ] `stage0_baseline.log`
- [ ] `stage1_interconnect.log`
- [ ] `stage2_gpio_unit.log`
- [ ] `stage2_gpio_integration.log`
- [ ] `stage2_gpio_switch_benchmarks.log`
- [ ] `stage3_divider_unit.log`
- [ ] `stage3_divider_integration.log`

בנוסף צריכים להיווצר אוטומטית קובצי שחזור התצוגה של חלון List:

- [ ] `stage0_baseline_list.do`
- [ ] `stage1_interconnect_list.do`
- [ ] `stage2_gpio_unit_list.do`
- [ ] `stage2_gpio_integration_list.do`
- [ ] `stage2_gpio_switch_benchmarks_list.do`
- [ ] `stage3_divider_unit_list.do`
- [ ] `stage3_divider_integration_list.do`

קבצים אלה אינם תוצאות הסימולציה עצמן; הם שומרים את מבנה חלון List. ה-log,
צילום ה-Wave והודעת ה-PASS נשארים ראיות הבדיקה העיקריות.

## 7. מה לעשות במקרה של כשל

עצור בבדיקה הראשונה שנכשלה ושמור:

1. שם ה-script שהורץ.
2. קובץ ה-log לפני הרצה חוזרת.
3. הטקסט המלא מהשורה הראשונה שמכילה `Error` או `Failure` ועד סוף ההרצה.
4. צילום Wave באזור הזמן שבו הופעל ה-assertion.
5. צילום Transcript הכולל את פקודת `do` ואת הודעת הכשל.
6. האם הכשל היה בזמן compile, בזמן `vsim`, או במהלך `run -all`.

שלח לי את החומרים האלה. לאחר תיקון נריץ שוב את הבדיקה שנכשלה, ורק לאחר
PASS נמשיך לבדיקה הבאה.

## 8. מה לשלוח לאחר שכל הבדיקות עברו

שלח לי הודעה בפורמט הבא:

```text
ModelSim stages 0-3
1. stage0_baseline: PASS
2. stage1_interconnect: PASS
3. stage2_gpio_unit: PASS
4. stage2_gpio_integration: PASS
5. stage2_gpio_switch_benchmarks: PASS
6. stage3_divider_unit: PASS
7. stage3_divider_integration: PASS
Warnings חריגים: אין / פירוט
```

צרף את שבעת קובצי ה-log ואת צילומי ה-Wave. לאחר סקירתם נעדכן את
`PROJECT_PLAN.md` עם זמני הבדיקה, נסמן את שלבים 0–3 כהושלמו, וניצור
checkpoint חדש ב-GitHub. לאחר מכן תתחיל הכנת שלבים 4–5.

## 9. שער סיום יום הבדיקה

יום הבדיקה הושלם רק כאשר מתקיים אחד משני המצבים:

- כל שבע הבדיקות מציגות PASS, וכל שבעת ה-logs וצילומי ה-Wave נשמרו; או
- נעצרנו בכשל הראשון וכל המידע הדרוש לשחזורו נשמר ונשלח.

אין להתחיל שלב 4 על סמך ריצה חלקית של הבדיקות.

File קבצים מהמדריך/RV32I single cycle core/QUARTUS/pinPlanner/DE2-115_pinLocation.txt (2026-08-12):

Pin Planner - Connected Locations:

1) rst_i = PIN_AB28(SW0)
2) clk_i = PIN_Y2(CLOCK_50MHz) = PLL input clock

Note: all the rest signals pins and ports are unassigned

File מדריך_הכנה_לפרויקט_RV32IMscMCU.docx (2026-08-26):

מדריך הכנה למעבדה

RV32IMscMCU

מערכת MCU חד־מחזורית מסוג RV32IM על כרטיס DE10-Standard

מטרת הפרויקט • שלבי המימוש • כל קובץ ופונקציה • בדיקות • שאלות מדריך

גרסה | מועד הכנה | סטטוס בסיס
לפני בדיקת מעבדה | 26.08.2026 | שלבים 0–9 עברו; שלבים 10–11 פתוחים

איך להשתמש במסמך

קרא תחילה את תקציר המערכת ואת מסלול הבדיקה. לאחר מכן למד לעומק את הקבצים RV32IMscMCU.vhd, RV32I_CORE.vhd, mcu_interconnect.vhd, basic_timer.vhd, interrupt_controller.vhd ו-divider_accelerator.vhd. בערב שלפני המעבדה עבר על פרק השאלות והתשובות ועל רשימת ה־Waveforms.

# תוכן ומסלול קריאה

סעיף | נושא
1 | מטרת הפרויקט ומה נדרש להוכיח
2 | מבנה בדיקת המעבדה לפי מסמך ההנחיות
3 | ארכיטקטורה וזרימת מידע במערכת
4 | שלבי הפרויקט - מה כל שלב עושה
5 | מפת כתובות, שעונים ו־Reset
6 | פירוט מלא של קובצי ה־DUT והפונקציות בכל קובץ
7 | קובצי TB, SIM, Quartus, DOC ו־Benchmark apps
8 | מסלולים קריטיים: DIV/REM, פסיקה, Timer ו־MMIO
9 | בדיקות, Waveforms וראיות שכדאי להציג
10 | שאלות מדריך צפויות ותשובות קצרות
11 | מצב מוכנות, פערים וצ'קליסט ליום המעבדה
נספח | מילון מונחים, כתובות ו־cheat sheet

עיקרון חשוב

ב־VHDL אין תמיד “פונקציה” במובן של שפת תוכנה. לכן בכל קובץ מפורטים גם entity, architecture, processes, פונקציות מקומיות, רכיבים שמאותחלים וממשקי הכניסה/יציאה. אלה הם גושי ההתנהגות שהמדריך צפוי לבקש להסביר.

# 1. מטרת הפרויקט ומה נדרש להוכיח

מטרת הפרויקט היא לבנות מערכת מיקרו־בקר מלאה סביב ליבת RISC-V מסוג RV32IM חד־מחזורית, לממש אותה ב־VHDL, לאמת אותה ב־ModelSim, לקמפל ולצרוב אותה לכרטיס DE10-Standard, ולהפעיל עליה תוכנות בדיקה אמיתיות מתוך קובצי ITCM.hex ו־DTCM.hex.

המערכת אינה רק “מעבד”. היא כוללת ליבת CPU, זיכרון הוראות ITCM, זיכרון נתונים DTCM, bus נתונים ו־address decoder, רכיבי GPIO, טיימר בסיסי, לחצנים עם debounce, בקר פסיקות ומאיץ חומרה רב־מחזורי לפקודות DIV/DIVU/REM/REMU. כל הרכיבים נגישים דרך Memory-Mapped I/O במרחב כתובות אחד.

ברמת ההדגמה צריך להראות ארבע יכולות משלימות: נכונות פונקציונלית של הקוד, הבנת הארכיטקטורה, שליטה בשרשרת הפיתוח Quartus–ModelSim–RARS, והיכולת להסביר HDL ממוקד עד רמת process ואותות.

## 1.1 מהו RV32IM

- RV32: רגיסטרים ונתיב נתונים ברוחב 32 ביט.
- I: סט הפקודות הבסיסי - חיבור, חיסור, לוגיקה, shifts, load/store, branch ו־jump.
- M: הרחבת כפל וחילוק. במימוש הפעיל MUL הוא קומבינטורי על 16 הביטים התחתונים; DIV/REM משתמשים במאיץ 32 ביט רב־מחזורי.
- single-cycle: פקודה רגילה משלימה fetch/decode/execute/memory/write-back במחזור ליבה אחד. DIV/REM וכניסה לפסיקה הם החריגים הרב־מחזוריים.
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

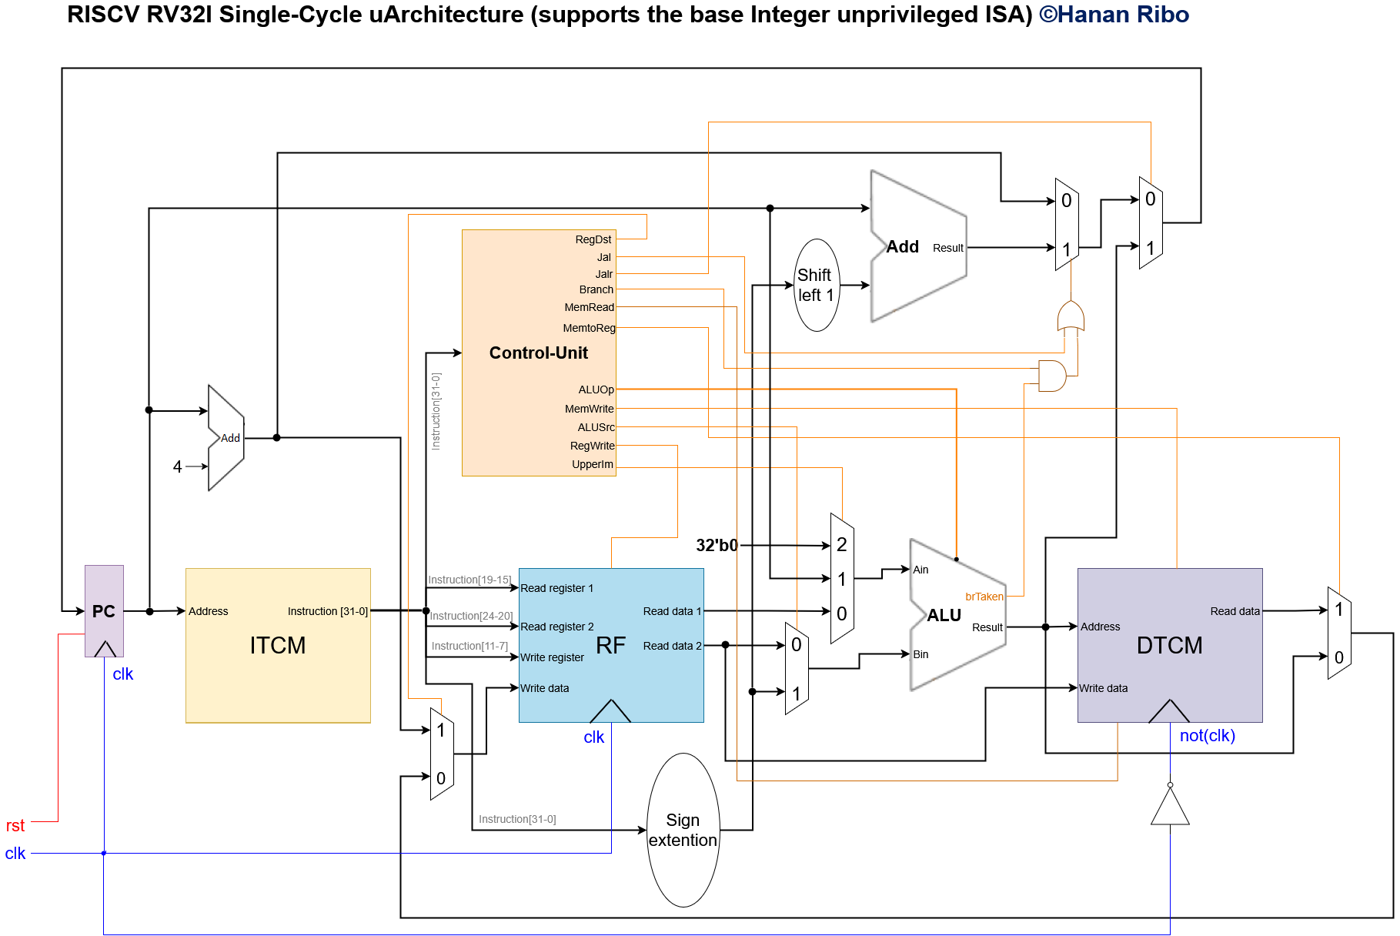
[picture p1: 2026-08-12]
קבצים מהמדריך/RV32I single cycle core/DOC/RV32I uArc.png

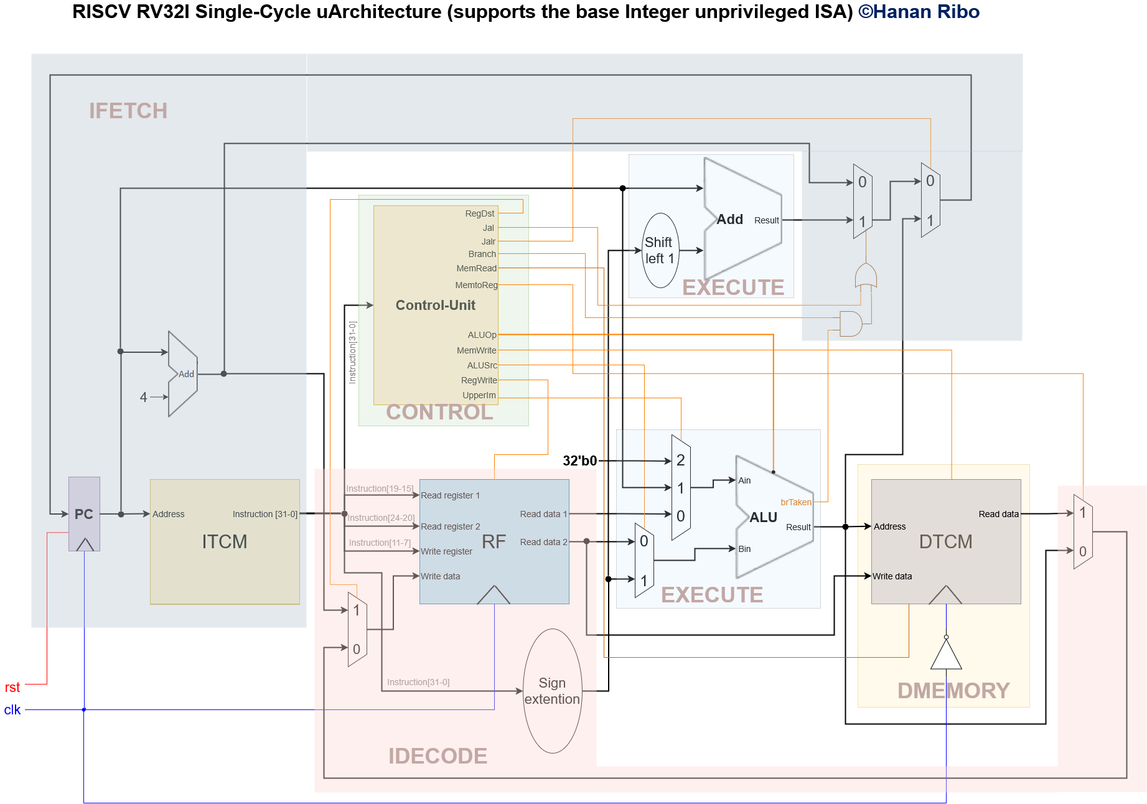
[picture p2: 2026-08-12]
קבצים מהמדריך/RV32I single cycle core/DOC/RV32I uArc_submodules.png

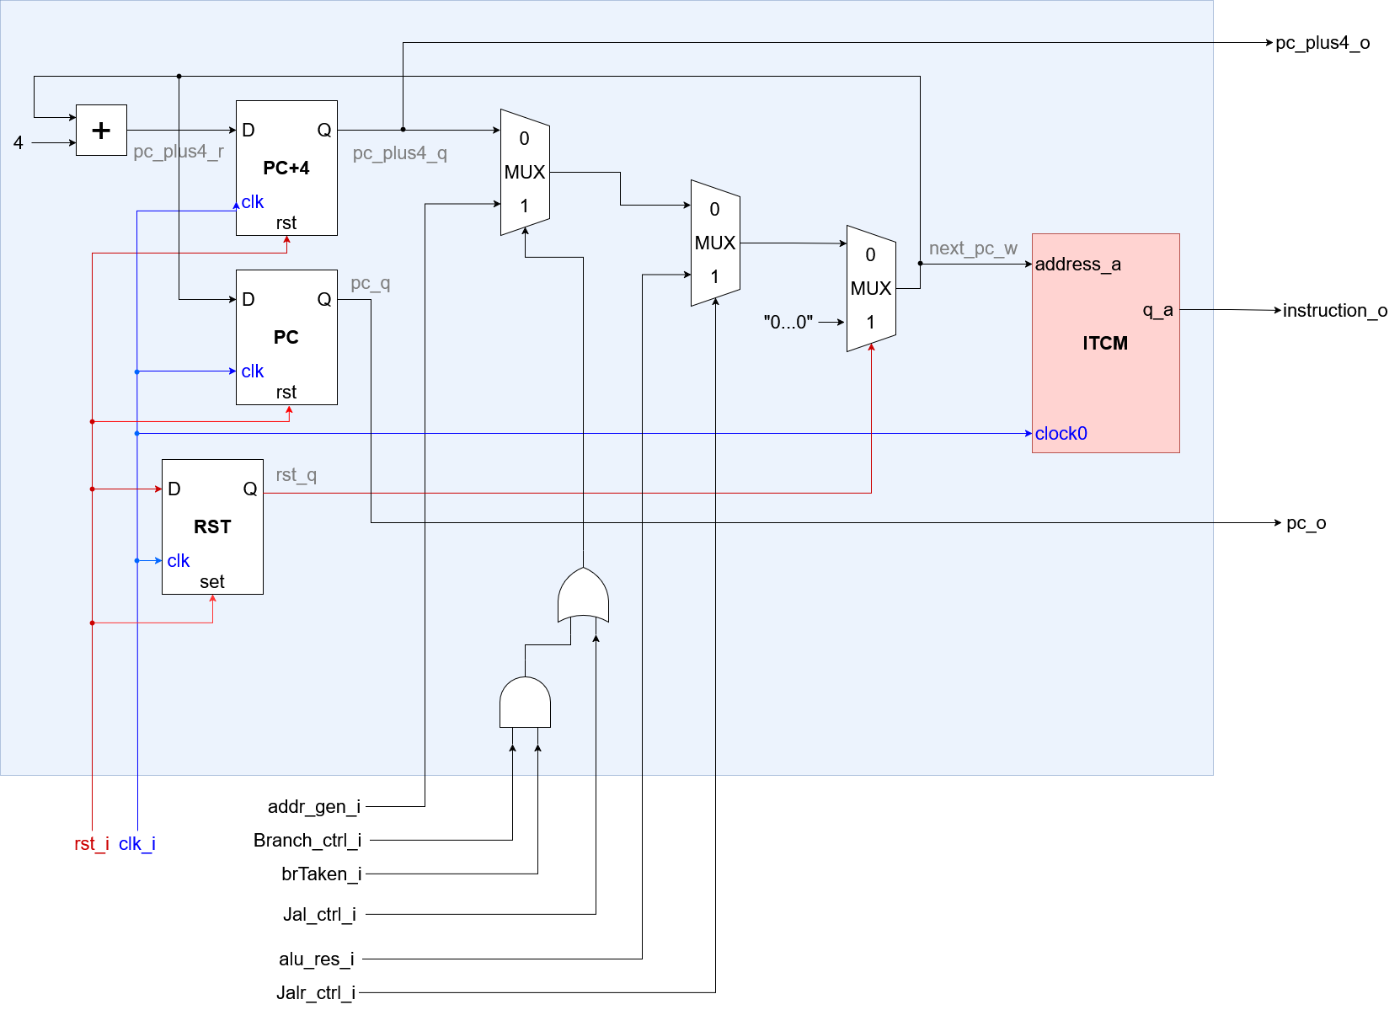
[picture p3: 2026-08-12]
קבצים מהמדריך/RV32I single cycle core/DOC/IFETCH rtl.png

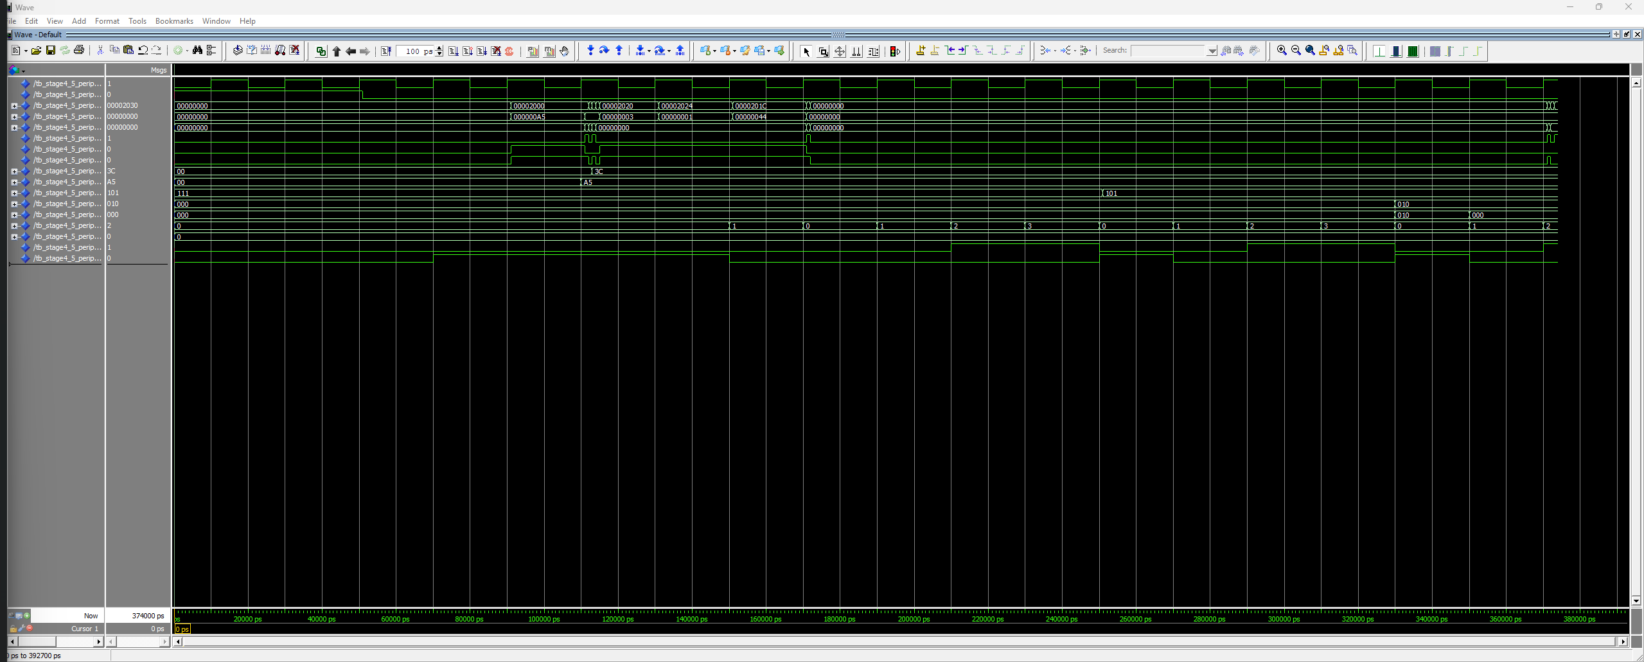
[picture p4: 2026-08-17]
SIM/RV32IMscMCU/screenshots/stage4_5_peripheral_integration/Screenshot 2026-08-17 222040.png

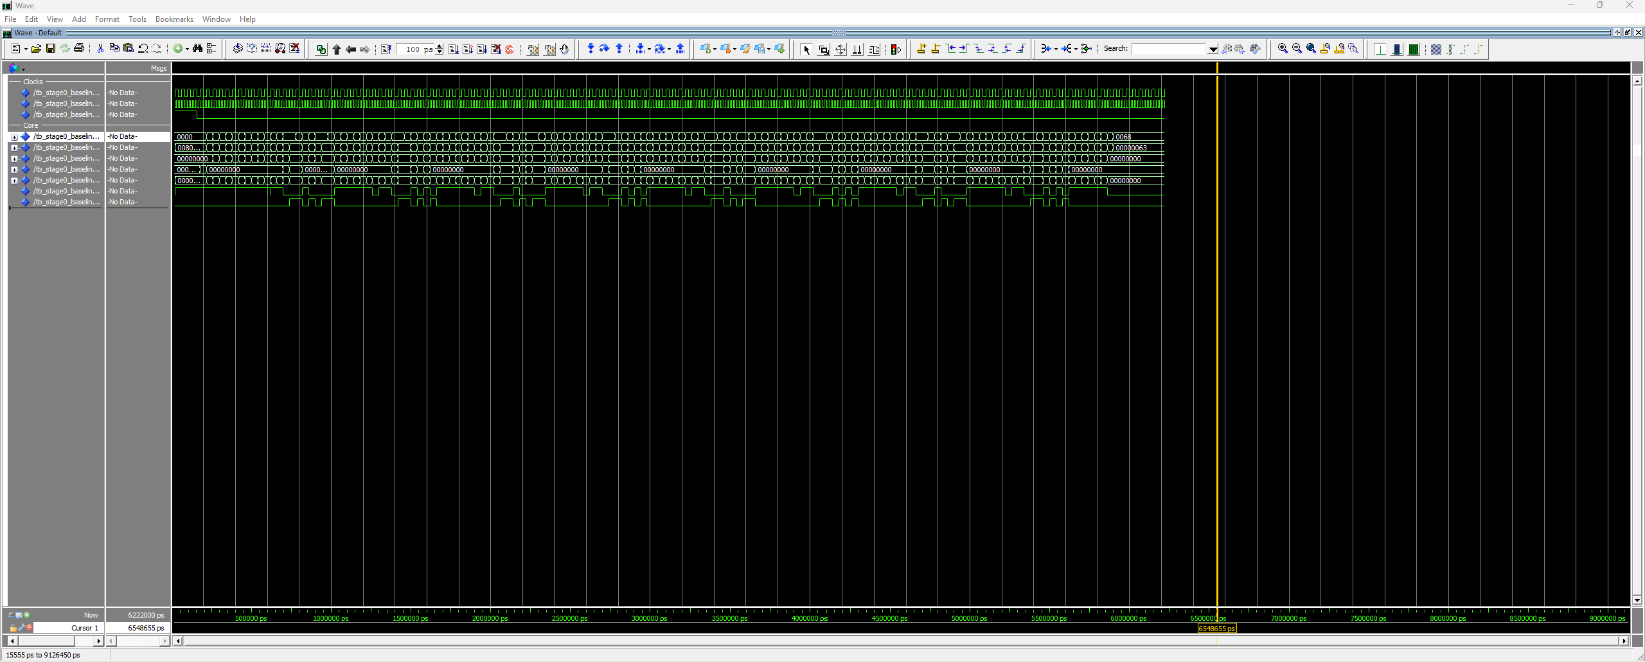
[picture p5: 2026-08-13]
SIM/RV32IMscMCU/screenshots/stage 0/Screenshot 2026-08-13 140023.png

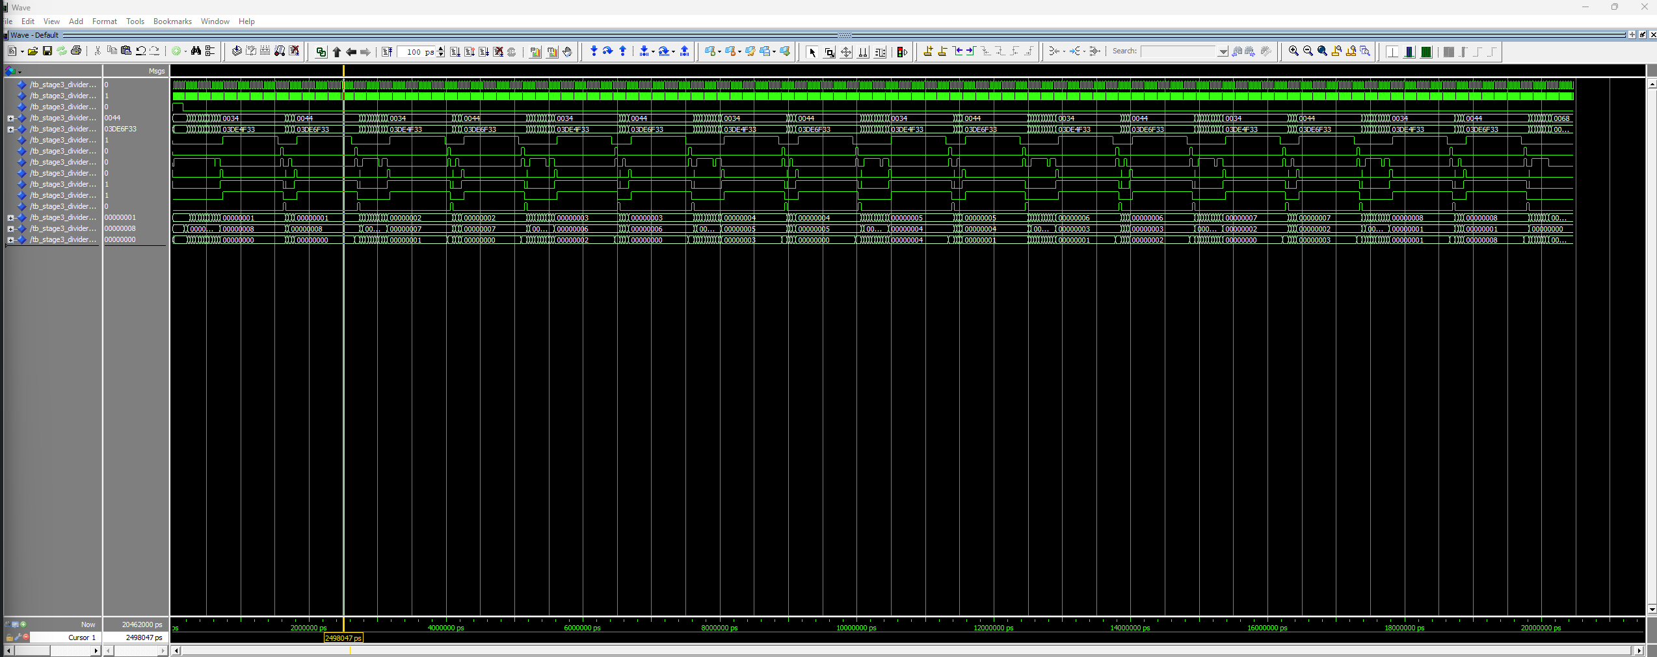
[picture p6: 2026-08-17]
SIM/RV32IMscMCU/screenshots/stage3_divider_integration/stage3_divider_integration.png

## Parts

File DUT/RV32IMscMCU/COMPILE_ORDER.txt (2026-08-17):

cond_compilation_package.vhd
const_package.vhd
mcu_memory_map_pkg.vhd
aux_package.vhd
PLL.vhd
Multiplier16.vhd
divider_unsigned.vhd
divider_accelerator.vhd
mcu_interconnect.vhd
gpio_peripheral.vhd
basic_timer.vhd
pushbutton_unit.vhd
interrupt_controller.vhd
mcu_peripherals.vhd
CONTROL.VHD
DMEMORY.VHD
EXECUTE.VHD
IDECODE.VHD
IFETCH.VHD
RV32I_CORE.vhd
RV32IMscMCU.vhd

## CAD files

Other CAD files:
Quartus/RV32IMscMCU/RV32IMscMCU.stp
מעבדה קודמת שלנו/Lab5/QUARTUS/RV32IM_pipeline/stp1.stp
מעבדה קודמת שלנו/Lab5/QUARTUS/RV32IM_sc/SingleCycle_RV32IM_SignalTap.stp

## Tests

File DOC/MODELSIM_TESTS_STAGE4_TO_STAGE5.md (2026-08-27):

# בדיקות ModelSim — שלבים 4 ו־5

סטטוס הכנה: 17.08.2026 22:09 IDT. שלוש הבדיקות עברו בהרצה אוטומטית, וכל
עשר בדיקות הרגרסיה של שלבים 0–5 עברו. ההרצה הבאה מיועדת לשמירת ראיות GUI.

## הכנה

בחלון Transcript של ModelSim יש לוודא שהתיקייה היא:

```tcl
cd {C:/Users/noam1/Desktop/VHDL Lab/Final proj/SIM/RV32IMscMCU}
```

לפני כל script מריצים `quit -sim`, כדי לשחרר את ספריית `work` מהסימולציה
הקודמת. אין צורך ליצור Project בתוך ModelSim.

## בדיקה 1 — שלב 4: Basic Timer

```tcl
quit -sim
do run_stage4_basic_timer.do
```

תוצאה תקינה:

```text
STAGE 4 BASIC TIMER PASS
```

הבדיקה מכסה:

- פענוח ו־readback של כל רגיסטרי הטיימר ו־BTCLR שחוזר אוטומטית לאפס.
- ארבע בחירות השעון: `sysclk`, ‏`/2`, ‏`/4`, ‏`/8`.
- `BTHOLD`, איפוס המונה ו־compare תקופתי דרך `BTCMPR0`.
- PWM בשני מצבי `BTOUTMD`, מעבר ב־`BTCMPR1` ושמירת הפלט כאשר `BTOUTEN=0`.
- Capture בקצה עולה מ־CAPIN1 ובקצה יורד מ־CAPIN2.
- בחירת אירוע הטיימר באמצעות `BTINT` ושמירת הערך ב־`BTCAPR`.

ב־Wave יש לראות במיוחד את `counter`, ‏`pwm`, ‏`compare0_event`,
`compare1_event`, ‏`capture_event`, ‏`timer_event` ו־`capture_value`.

## בדיקה 2 — שלב 5: Pushbuttons

```tcl
quit -sim
do run_stage5_pushbuttons.do
```

תוצאה תקינה:

```text
STAGE 5 PUSHBUTTONS PASS
```

הבדיקה מכסה פולריות active-low, שני שלבי synchronizer, דחיית bounce, לחיצה
יציבה, לחיצה ארוכה ללא אירועים חוזרים, שחרור ללא אירוע press, לחיצה בו־זמנית
על שני כפתורים וקריאת `PORT_PB` ב־`0x2014`.

ב־Wave יש לראות את `keys_n`, ‏`keys_prev_n_q`, ‏`buttons`,
`release_event` ומוני אירועי השחרור של שלושת הכפתורים.

## בדיקה 3 — אינטגרציית שלבים 4–5 ו־MMIO

```tcl
quit -sim
do run_stage4_5_peripheral_integration.do
```

תוצאה תקינה:

```text
STAGE 4/5 PERIPHERAL INTEGRATION PASS
```

הבדיקה מוודאת שה־MMIO mux החדש אינו שובר את GPIO, ושגישות ל־LEDR, ל־SW,
לטיימר ול־PORT_PB חוזרות מהמקור היחיד הנכון. בנוסף נבדקים PWM, אירוע timer,
מצב כפתור מסונן וקריאה לא ממופה שמחזירה אפס ללא `hit`.

## מה לשמור

לכל בדיקה יש ליצור תיקיית ראיות נפרדת תחת
`SIM/RV32IMscMCU/screenshots`:

- `stage4_basic_timer`
- `stage5_pushbuttons`
- `stage4_5_peripheral_integration`

בכל תיקייה שמור:

1. צילום מסך שבו רואים את הודעת ה־PASS ואת ה־Wave.
2. Wave format כקובץ `.do` מתוך `File > Save Format` בחלון Wave.
3. List format: כל script יוצר אוטומטית בתיקיית הסימולציה קובץ בשם
   `stage4_basic_timer_list.do`, ‏`stage5_pushbuttons_list.do` או
   `stage4_5_peripheral_integration_list.do`; העתק אותו לתיקיית הראיות שלו.

אם מתקבלת `Failure` או `Error`, עוצרים ולא ממשיכים לבדיקה הבאה. יש לשלוח את
כל ה־Transcript ואת שם ה־script שנכשל. אזהרת WLF על קובץ שכבר פתוח אינה כשל
לוגי; במקרה כזה סוגרים סימולציה אחרת או מריצים שוב אחרי `quit -sim`.

לאחר שלושת ה־PASSים נעדכן את שלבים 4–5 ל־complete, נכין את תוכנית המעבדה
הפיזית של שלב 5.5, ורק לאחר מכן נממש ונכין את בדיקות שלבים 6–7.

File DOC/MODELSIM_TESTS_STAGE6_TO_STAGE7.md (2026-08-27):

# בדיקות ModelSim — שלבים 6 ו־7

סטטוס הכנה: 17.08.2026 22:57 IDT. שתי הבדיקות עברו בהרצה אוטומטית. ההרצה
של המשתמש מיועדת לשמירת ראיות GUI ולסגירה פורמלית של השלבים.

## הכנה

ב־Transcript של ModelSim:

```tcl
cd {C:/Users/noam1/Desktop/VHDL Lab/Final proj/SIM/RV32IMscMCU}
```

לפני כל בדיקה מריצים `quit -sim`. אין צורך ליצור ModelSim Project ואין
צורך לשנות קובצי HEX ידנית.

## בדיקה 1 — שלב 6: Interrupt Controller

```tcl
quit -sim
do run_stage6_interrupt_controller.do
```

תוצאה תקינה:

```text
STAGE 6 INTERRUPT CONTROLLER PASS
```

הבדיקה מכסה את כתובות `IE=0x202C`, ‏`IFG=0x202D`, ‏`TYPE=0x202E`, mask,
יצירת IFG רק כאשר ה־IE המתאים פעיל, ניקוי IFG כש־IE מתבטל, חסימת `INTR`
כאשר GIE=0, ותעדוף:

```text
Timer (0x10) > KEY1 (0x14) > KEY2 (0x18) > KEY3 (0x1C)
```

בנוסף נבדקים clear אוטומטי של timer בזמן `INTA`, clear תוכנתי של flags של
הכפתורים, ואירוע חדש שמגיע באותו מחזור של clear.

ב־Wave בדוק במיוחד את `timer_event`, ‏`key_event`, ‏`ie_value`, ‏`ifg_value`,
`gie`, ‏`intr`, ‏`inta` ו־`irq_type`.

## בדיקה 2 — שלב 7: CPU Interrupt Integration

```tcl
quit -sim
do run_stage7_cpu_interrupt_integration.do
```

תוצאה תקינה:

```text
STAGE 7 CPU INTERRUPT INTEGRATION PASS
```

הבדיקה מריצה את benchmark הפסיקות `test2` שסופק, ולא תוכנית צעצוע. ה־TB:

- ממתין שהתוכנה תכתוב `IE=0x3C` ותגדיר `gp[0]=GIE=1`.
- לוחץ ומשחרר KEY1, ‏KEY2 ו־KEY3 בנפרד; אירוע הפסיקה נוצר בשחרור.
- מאמת `INTA`, לכידת TYPE המתאים וקפיצה דרך vector table שב־DTCM.
- מאמת ש־GIE מתאפס בזמן כניסה לפסיקה.
- מאמת שכל ISR כותב `state=1/2/3`, מנקה את ה־IFG שלו ומבצע `reti`.
- מאמת שהחזרה דרך `tp` היא ל־PC שהוחזק בזמן הכניסה וש־GIE חוזר ל־1.

ב־Wave בדוק את `pc`, ‏`instruction`, ‏`intr`, ‏`inta`, ‏`gie`, ‏`irq_active`,
`irq_type`, ‏`interrupt_ie`, ‏`interrupt_ifg`, ‏`keys_n`, ‏`bus_addr`,
`bus_wdata`, ‏`bus_write`.

## בדיקת קבלה — פסיקה שמגיעה באמצע DIV

```tcl
quit -sim
do run_stage7_divider_interrupt_order.do
```

הבדיקה מעלה פסיקה בזמן `DIV`, מוודאת שהחלוקה מסתיימת ונכתבת חזרה לפני
`INTA`, ואז מאמתת כניסה ל־ISR, חזרה דרך `tp` והמשך הזרימה ששומרת את המנה.
התוצאה התקינה היא `STAGE 7 DIVIDER/INTERRUPT ORDER PASS`.

## שמירת ראיות

צור שתי תיקיות:

```text
SIM/RV32IMscMCU/screenshots/stage6_interrupt_controller
SIM/RV32IMscMCU/screenshots/stage7_cpu_interrupt_integration
```

בכל תיקייה שמור צילום מסך שבו רואים PASS ו־Wave, וקובץ Wave באמצעות
`File > Save Format`. כל script יוצר אוטומטית קובץ List בתיקיית הסימולציה:

- `stage6_interrupt_controller_list.do`
- `stage7_cpu_interrupt_integration_list.do`

העתק כל List לתיקיית הראיות המתאימה. אם מתקבל `Failure` או `Error`, עצור
ושלח את כל ה־Transcript; אזהרות X/U ב־0 ps או WLF נעול אינן כשל אם מתקבל PASS.

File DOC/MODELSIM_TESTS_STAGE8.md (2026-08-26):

# שלב 8 — אינטגרציה ואימות מלא ב־ModelSim

עודכן: 25.08.2026

## הרצה

מתוך `SIM/RV32IMscMCU`:

```text
vsim -c -do "do run_stage8_full_verification.do; quit -f"
```

הסקריפט מקמפל את כל מקורות ה־MCU, מריץ testbench מרכזי ובודק־עצמית ושומר
transcript ב־`stage8_full_verification.log`. קובץ
`stage8_representative_wave.do` משחזר את קבוצת הגלים המייצגת של test4.

## כיסוי ה־benchmarks

| ID | יישום | תוצאה |
|---:|---|---|
| 0 | RV32IM test1, manual | PASS |
| 1 | RV32IM test1, GCC | PASS |
| 2 | GPIO test0 | PASS |
| 3 | GPIO test1 | PASS |
| 4 | GPIO test2 | PASS |
| 5 | Interrupt test1 | PASS |
| 6 | Interrupt test2 | PASS |
| 7 | Interrupt test3 | PASS |
| 8 | Interrupt test4 | PASS |

שורת הסיום המאומתת היא `STAGE 8 FULL VERIFICATION PASS`.

## בדיקות אוטומטיות

- השוואה מילה־במילה של 24 תוצאות RV32IM בכתובות `0x40..0x9C` מול פלט RARS שסופק.
- אימות writes ל־GPIO, HEX, timer compare/capture, מערכי DIV/REM ותוצאות runtime.
- גירוי switches, שלושת pushbuttons, שני capture inputs ושני דומייני השעון.
- assertions עבור X/U לאחר reset, read/write חופפים, חפיפת DTCM/MMIO, כתיבה בזמן divider busy, timeout, חזרת ISR וניקוי IFG.
- test4 מאמת תכנות CMP0/CMP1, עליית PWM ופולס יציב. ירידת הפולס אינה מדומה עד סוף מחזור של 20,000,000 clocks, כדי לשמור על regression מעשי.

## מדדי ביצועים

`effective-retire-cycles` סופר מחזורים שבהם הליבה אינה ב־divider stall ואינה בתוך FSM הפסיקה. המדד המדווח הוא:

```text
IPC = effective-retire-cycles / total-cycles
```

| benchmark | cycles | effective-retire-cycles | IPC |
|---|---:|---:|---:|
| RV32IM manual | 508 | 188 | 0.370 |
| RV32IM GCC | 890 | 570 | 0.640 |

זהו מדד utilization של ליבת single-cycle, ולא מונה retirement ארכיטקטוני נפרד.

## התאמות שנדרשו לאחר עדכון המדריך

- טבלת הווקטורים החדשה מעורבת: tests 1–3 מכילים כתובות ITCM מקומיות, בעוד test4 עדיין מכיל כתובות מקושרות מבסיס `0x3000`. הליבה מנרמלת כעת את שני הפורמטים.
- תוכנית GCC משתמשת במחסנית ללא startup שמאתחל `sp`; בנק האוגרים מאתחל כעת את `x2` לראש ה־DTCM (`0x2000`).
- ב־interrupt/test1 פקודת הקפיצה של מצב ModelSim עוקפת את EINT. נשמר עותק מתוקן בן מילה אחת תחת `SIM/RV32IMscMCU/firmware`; תיקיית המדריך אינה משתנה.

לאחר התיקונים הורצו מחדש כל סקריפטי שלבים 0–7, וכולם עברו.

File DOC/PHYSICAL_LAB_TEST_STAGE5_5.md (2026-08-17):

# תוכנית בדיקת מעבדה פיזית — שלב 5.5

עודכן: 17.08.2026 23:06 IDT

מטרת הבדיקה היא לאמת על כרטיס DE10-Standard את שרשרת ה־clock/reset, מיפוי
הפינים, קריאת KEY1–KEY3 לאחר debounce ויציאת ה־PWM. זו בדיקת חומרה מוקדמת;
מסלול הפסיקות המלא ו־SignalTap ייבדקו בהמשך.

## מה כבר מוכן

- כל פיני `CLOCK_50`, ‏`KEY`, ‏`SW`, ‏`LEDR` ו־`HEX0`–`HEX5` מוגדרים ב־QSF.
- שעון הליבה הוא 20 MHz וה־Divider נשאר על 50 MHz.
- debounce פיזי הוא 200,000 מחזורים, כלומר 10 ms ב־20 MHz.
- תוכנת `ITCM_stage5_5.hex` כבר משובצת בתכן.
- Quartus Map, Fitter, Assembler ו־Timing Analyzer עברו. ה־setup slack הגרוע
  ביותר הוא חיובי: 2.631 ns; קובץ ה־SOF כבר קיים מקומית.
- אותו קובץ `ITCM_stage5_5.hex` עבר גם בדיקת preflight אוטומטית ב־ModelSim:
  `STAGE 5.5 SMOKE FIRMWARE PASS`.

## התנהגות צפויה של תוכנת הבדיקה

| רכיב בכרטיס | התנהגות |
|---|---|
| `HEX0` | מציג `C`, כדי להוכיח שהתוכנה התחילה לרוץ |
| `HEX1`–`HEX5` | מציגים `0` |
| `LEDR0` | דולק כל עוד KEY1 לחוץ לאחר debounce |
| `LEDR1` | דולק כל עוד KEY2 לחוץ לאחר debounce |
| `LEDR2` | דולק כל עוד KEY3 לחוץ לאחר debounce |
| `LEDR8` | יציאת PWM; ה־duty נשלט על ידי `SW7:0` |
| `LEDR9` | דולק כל עוד לפחות אחד מ־KEY1–KEY3 לחוץ |
| `KEY0` | reset פעיל־נמוך |

תדר ה־PWM הוא כ־76.3 Hz. במצב הנוכחי ערך switch קטן נותן זמן HIGH גדול:

| `SW7:0` | duty HIGH צפוי בקירוב | מה רואים ב־LEDR8 |
|---:|---:|---|
| `0` | כמעט 100% | בהיר מאוד |
| `64` | 75% | בהיר |
| `128` | 50% | בינוני |
| `192` | 25% | חלש |
| `255` | כמעט 0% | כמעט כבוי |

## חלק א — פתיחת הפרויקט וטעינת הכרטיס

1. חבר את ספק הכוח ואת כבל USB-Blaster לכרטיס והדלק אותו.
2. פתח ב־Quartus את:

   ```text
   C:/Users/noam1/Desktop/VHDL Lab/Final proj/Quartus/RV32IMscMCU/RV32IMscMCU.qpf
   ```

3. ודא שה־Top-Level הוא `RV32IMscMCU` ושהרכיב הוא
   `5CSXFC6D6F31C6`.
4. אין חובה לקמפל שוב: קובץ התכנות המוכן הוא:

   ```text
   output_files/RV32IMscMCU.sof
   ```

5. פתח `Tools > Programmer`.
6. ב־`Hardware Setup` בחר `USB-Blaster`.
7. אם הקובץ אינו מופיע, לחץ `Add File` ובחר את ה־SOF לעיל.
8. סמן `Program/Configure` ולחץ `Start`. ההתקדמות צריכה להגיע ל־100% ללא
   error.

## חלק ב — בדיקת אתחול ו־reset

1. מיד לאחר הצריבה ודא ש־HEX0 מציג `C`.
2. לחץ והחזק KEY0. בזמן reset כל LED צריך להיות כבוי ותצוגות ה־HEX חוזרות
   לערך האיפוס.
3. שחרר KEY0. לאחר נעילת ה־PLL, ‏HEX0 צריך לחזור ל־`C`.
4. אם HEX0 אינו חוזר ל־`C`, עצור וצלם את הכרטיס ואת חלון Programmer.

## חלק ג — בדיקת KEY1–KEY3

בצע לכל כפתור בנפרד:

1. לחץ מעל 20 ms.
2. ודא שה־LED המתאים (`LEDR0`, ‏`LEDR1` או `LEDR2`) ו־`LEDR9` נדלקים.
3. החזק את הכפתור כשנייה: המצב צריך להישאר יציב ללא הבהוב.
4. שחרר: שני ה־LEDs צריכים להיכבות לאחר זמן debounce קצר.
5. בצע לחיצה קצרה אך מכוונת. לחיצה קצרה מ־10 ms רשאית להידחות; לחיצה
   יציבה מעל 10 ms חייבת להיקלט.
6. לחץ שני כפתורים יחד וודא ששני ה־LEDR המתאימים דולקים ו־LEDR9 נשאר דולק.

## חלק ד — בדיקת PWM

1. קבע `SW7:0=0` והסתכל על LEDR8.
2. עבור לפי הסדר לערכים `64`, ‏`128`, ‏`192`, ‏`255` והשווה את עוצמת האור
   לטבלה.
3. בכל ערך המתן לפחות שנייה כדי להבחין בעוצמה/הבהוב.
4. אם יש oscilloscope או logic analyzer ונקודת מדידה בטוחה, מדוד כ־76 Hz
   ו־duty של כ־50% כאשר `SW7:0=128`. אל תחבר probe ישירות אם אין נקודת
   גישה בטוחה בלוח.

## מה לשמור כראיה

צור את התיקייה:

```text
SIM/RV32IMscMCU/screenshots/stage5_5_hardware
```

שמור בה:

1. צילום של Programmer ב־100%.
2. צילום הכרטיס עם HEX0=`C`.
3. צילום לכל KEY שבו רואים את ה־LEDR המתאים ואת LEDR9.
4. שני צילומי PWM לפחות: `SW=0` ו־`SW=128` או `255`.
5. אם יש מדידה — צילום oscilloscope עם frequency ו־duty.
6. קובץ טקסט קצר עם PASS/FAIL לכל סעיף ושעת הבדיקה.

## שער יציאה

שלב 5.5 יעבור רק אם הצריבה מגיעה ל־100%, reset מפעיל מחדש את התוכנה, כל
שלושת הכפתורים מזוהים נכון, ו־LEDR8 משתנה באופן עקבי עם ערך ה־switches.
בכשל אין להמשיך לבדיקת פסיקות על הכרטיס; יש לשלוח צילום ותיאור הסעיף שנכשל.

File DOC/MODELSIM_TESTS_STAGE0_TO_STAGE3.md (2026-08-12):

# בדיקות ModelSim — שלבים 0 עד 3

הבדיקות מוכנות להרצה נפרדת. הן לא הורצו ביום ההכנה, בהתאם להחלטה לדחות את
ModelSim. כל script יוצר מחדש את ספריית `work`, מקמפל רק את הקבצים הדרושים,
פותח Wave מתאים, מריץ עד לסיום וכותב log בתיקיית `SIM/RV32IMscMCU`.

## הכנה חד-פעמית

1. לפתוח ModelSim Intel FPGA Starter Edition.
2. לבחור `File > Change Directory` ולעבור אל:
   `C:/Users/noam1/Desktop/VHDL Lab/Final proj/SIM/RV32IMscMCU`
3. לוודא שבחלון Transcript מופיע הנתיב הזה.
4. אין צורך ליצור project גרפי ב-ModelSim; קובצי ה-`.do` עושים זאת בעצמם.

## סדר ההרצה

### 1. שלב 0 — baseline

ב-Transcript:

```tcl
do run_stage0_baseline.do
```

תוצאה תקינה: מופיעה ההודעה
`STAGE 0 PASS: RV32I/MUL baseline and DTCM regression`, ללא `Failure` או
`Error`. ה-TB בודק שה-benchmark מגיע ללולאת העצירה, שיש פעולות `MUL`,
שהתוצאה תואמת למכפלת 16 הביטים התחתונים ושיש כתיבות DTCM.

### 2. שלב 1 — Address decoder ו-read mux

```tcl
do run_stage1_interconnect.do
```

תוצאה תקינה: `STAGE 1 INTERCONNECT PASS`. הבדיקה מכסה המרת byte address
ל-word index ב-DTCM, שמירת כל ביטי הכתובת ב-MMIO, הפרדה בין write-enables,
read mux וגישה לכתובת שאינה ממומשת.

### 3. שלב 2 — GPIO unit test

```tcl
do run_stage2_gpio_unit.do
```

תוצאה תקינה: `STAGE 2 GPIO UNIT PASS`. הבדיקה מכסה reset, כתיבת low byte
ל-LEDR, הכתובות הצמודות והלא מיושרות של HEX, קידוד active-low, קריאת
switches עם zero extension, ודחיית כתובת שאינה ממומשת.

### 4. שלב 2 — GPIO integration

```tcl
do run_stage2_gpio_integration.do
```

תוצאה תקינה: `STAGE 2 GPIO INTEGRATION PASS`. ה-TB מריץ את
`Benchmark apps/GPIO/test0`, דורש לפחות שתי כתיבות ל-LEDR ושתי סדרות של
כתיבות לכל ששת ה-HEX, ומוודא שבסוף הסדרה השנייה `LEDR=0x01`.

בדיקה זו נשענת על `test0`, שאין בו תלות בגירוי switches ולכן הוא
דטרמיניסטי. שני ה-benchmarks הנוספים נבדקים אוטומטית בסעיף הבא.

### 5. שלב 2 — benchmarks עם switches

```tcl
do run_stage2_gpio_switch_benchmarks.do
```

תוצאה תקינה: `STAGE 2 GPIO TEST1/TEST2 INTEGRATION PASS`. ה-TB מריץ במקביל
את `GPIO/test1` ואת `GPIO/test2`, מפעיל את SW0, ודורש מכל תוכנה כתיבה של
הערך 1 ל-LEDR וכתיבה לכל ששת צגי ה-HEX.

### 6. שלב 3 — Divider unit test

```tcl
do run_stage3_divider_unit.do
```

תוצאה תקינה: `STAGE 3 DIVIDER UNIT PASS`. נבדקים `DIV`, `DIVU`, `REM`,
`REMU`, סימנים, חלוקה באפס ו-overflow של `0x80000000 / -1`. צריך לראות
בקירוב 32 מחזורי `divclk` לפעולה רגילה; מקרי קצה מסתיימים מוקדם יותר.

### 7. שלב 3 — שילוב CPU/Divider

```tcl
do run_stage3_divider_integration.do
```

תוצאה תקינה: `STAGE 3 CPU/DIVIDER INTEGRATION PASS`. ה-TB מריץ את
benchmark ה-RV32IM הידני, סופר בדיוק שמונה `DIV` ושמונה `REM`, מוודא שה-PC
נשאר קבוע בזמן `busy`, שאין write-back מוקדם, ושיש write-back יחיד ב-`done`.

## מה לשמור אחרי כל בדיקה

- צילום Wave שמראה את האותות המרכזיים ואת הודעת ה-PASS.
- קובץ ה-log שנוצר אוטומטית: `stage0_baseline.log`, `stage1_interconnect.log`,
  `stage2_gpio_unit.log`, `stage2_gpio_integration.log`,
  `stage2_gpio_switch_benchmarks.log`,
  `stage3_divider_unit.log`, או `stage3_divider_integration.log`.
- אם יש כשל, לא להמשיך לבדיקה הבאה: לשמור את ה-log וה-Wave ולרשום באיזה
  script ובאיזו הודעת assertion נעצרה הריצה.

## הערה על ספריות Intel

בדיקות ה-CPU משתמשות ב-`altsyncram`, ולכן scripts אלה מפעילים
`vsim -L altera_mf`. אם ModelSim אינו מוצא את הספרייה, יש להריץ פעם אחת
`Tools > Compile Simulation Libraries` עבור Cyclone V/ModelSim Intel FPGA,
ואז לחזור על ה-script. בדיקות ה-GPIO וה-divider העצמאיות אינן תלויות ב-IP.

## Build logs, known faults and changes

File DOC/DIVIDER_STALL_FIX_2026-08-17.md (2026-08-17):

# Divider integration stall fix — 17.08.2026

## Symptom

`run_stage3_divider_integration.do` originally stopped at 782 ns with:

```text
Stage 3 integration: PC changed while divider busy
```

At the failure point the accelerator was still busy, but the instruction had
already changed from the DIV at PC `0x34` to the following store at `0x38`.
Consequently the combinational DIV decode and the CPU stall both fell to zero.

## Root cause

The original single-cycle `IFETCH` addresses ITCM from `next_pc_w`. This is
correct during ordinary one-cycle execution, but a multi-cycle operation also
has to keep the instruction associated with the held `pc_q` visible. Holding
only the PC registers left ITCM pointing at the following instruction.

There was a second boundary condition at completion: fetch must remain stalled
through the system-clock edge that writes the divider result to `rd`. Releasing
on the combinational `done` pulse can replace the DIV decode before that edge.

## Fix

- `IFETCH.VHD` selects `pc_q` as the ITCM address while
  `divider_hold_i='1'`.
- `RV32I_CORE.vhd` adds `div_retired_q`. The DIV instruction stays stalled
  through its single write-back edge, then receives exactly one release cycle.
- A new request is blocked while the previous instruction is being retired.
- The release flag clears after one clock, including for back-to-back divider
  instructions.
- The Stage 3 integration Wave/List now includes `div_start_w`,
  `divider_hold_w`, `div_active_q`, and `div_retired_q`.

## Verification

- Stage 3 divider integration: PASS at 20462 ns.
- Stage 3 divider unit: PASS.
- Stage 0 baseline: PASS.
- Stage 1 interconnect: PASS.
- Stage 2 GPIO unit: PASS.
- Stage 2 GPIO/test0 integration: PASS.
- Stage 2 GPIO/test1/test2 integration: PASS.
- Quartus Analysis & Synthesis after the functional fix: 0 errors and 13
  warnings; the warnings are the previously documented non-blocking warnings.

The ModelSim arithmetic metavalue warnings occur only during initialization at
0 ps and are not the cause of the original failure.

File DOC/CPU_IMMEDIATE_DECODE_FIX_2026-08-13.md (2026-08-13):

# תיקון פענוח immediate בליבת ה-CPU

תאריך: 13.08.2026 15:04 IDT

## תקציר

בדיקות האינטגרציה של GPIO חשפו שתי תקלות קיימות בקוד הבסיס של הליבה:

1. פקודת `LUI` סווגה כ-U-type ב-Control, אך לא קיבלה U-immediate ב-Idecode.
2. פקודות load סווגו כ-I-type ב-Control, אך לא קיבלו I-immediate ב-Idecode.

שתי התקלות נמצאו גם בגרסת המדריך וגם בגרסת Lab 5. תיקיות המקור נשמרו ללא
שינוי; התיקון בוצע רק בעץ הפעיל `DUT/RV32IMscMCU`.

## תקלה 1 — LUI איבד את החלק הגבוה של הכתובת

בקוד המקורי הוגדר:

```vhdl
constant UTYPE_OPC := "0010111" and "0110111";
```

תוצאת ה-AND היא `0010111`, שהוא opcode של `AUIPC`. ב-`CONTROL.VHD` הערך
שימש כמסכה ולכן זיהה גם `AUIPC` וגם `LUI`. ב-`IDECODE.VHD` אותו ערך שימש
כהתאמה מדויקת בתוך `with select`, ולכן `LUI` (`0110111`) נפל ל-`others`
וקיבל immediate אפס.

ההשפעה נצפתה ישירות ב-List של ModelSim:

| כתובת רצויה | כתובת לפני התיקון |
|---:|---:|
| `0x2000` | `0x0000` |
| `0x2004` | `0x0004` |
| `0x2005` | `0x0005` |
| `0x2008` | `0x0008` |
| `0x2009` | `0x0009` |
| `0x200C` | `0x000C` |
| `0x200D` | `0x000D` |

לכן הכתיבות הופנו ל-DTCM במקום ל-MMIO.

### תיקון

ב-`const_package.vhd` הוגדרו opcodes מפורשים ונפרדים:

```vhdl
constant AUIPC_OPC : std_logic_vector(6 downto 0) := "0010111";
constant LUI_OPC   : std_logic_vector(6 downto 0) := "0110111";
```

ה-Control בודק כל opcode במפורש, וה-Idecode בוחר U-immediate עבור שתי
האפשרויות:

```vhdl
when AUIPC_OPC | LUI_OPC
```

## תקלה 2 — offset של פקודות load היה תמיד אפס

לאחר תיקון LUI, ה-benchmark הגיע לכתובת הבסיס `0x2000`, אך הפקודה:

```asm
lw t4, 16(t4)
```

יצרה `0x2000` במקום `0x2010`. הסיבה הייתה ש-`IDECODE.VHD` בחר
`SignExt_Iimm_w` עבור arithmetic I-type ו-`JALR`, אך לא עבור opcode של
load (`0000011`). לכן offset‏ `16` הוחלף באפס, והקריאה בוצעה מ-LEDR במקום
מ-PORT_SW.

### תיקון

נוסף:

```vhdl
constant LOAD_OPC : std_logic_vector(6 downto 0) := "0000011";
```

ובחירת ה-immediate עודכנה:

```vhdl
when ITYPE_OPC | LOAD_OPC
```

## תיקון דיוק ב-testbench

ה-bus של הליבה הוא combinational והכתיבה ל-GPIO מתבצעת בקצה העולה. שני
testbenches של האינטגרציה דגמו את ה-bus שתי ננו-שניות אחרי הקצה, ולכן ראו
את הפקודה הבאה ולא את הטרנזקציה שבוצעה בקצה. הדגימה הועברה לרגע הקצה
העולה, ולאחר סיום הספירה נוסף delay קצר רק לפני בדיקת יציאות הרגיסטרים.

השינוי ב-testbench אינו מסתיר כשל DUT: לפני תיקון ה-opcodes נצפו בפועל
כתובות שגויות. הוא רק מבטיח שהמונה ב-TB והיציאה הפיזית מתייחסים לאותה
טרנזקציה.

## אימות לאחר התיקון

| בדיקה | תוצאה | זמן סימולציה |
|---|---|---:|
| Stage 0 baseline regression | PASS | 6222 ns |
| Stage 2 GPIO unit | PASS (הרצת משתמש לפני התיקון; הרכיב לא השתנה) | 223 ns |
| Stage 2 GPIO/test0 integration | PASS | 2462 ns |
| Stage 2 GPIO test1/test2 + SW0 | PASS | 2342 ns |
| Quartus Analysis & Synthesis | PASS — 0 errors, 13 warnings | 13.08.2026 15:08 IDT |

אזהרות U/X שנצפו ב-0 ps הן אזהרות אתחול קיימות. לא הופיעו assertion
failures לאחר התיקון.

## קבצים פעילים ששונו

- `DUT/RV32IMscMCU/const_package.vhd`
- `DUT/RV32IMscMCU/CONTROL.VHD`
- `DUT/RV32IMscMCU/IDECODE.VHD`
- `TB/RV32IMscMCU/tb_stage2_gpio_integration.vhd`
- `TB/RV32IMscMCU/tb_stage2_gpio_switch_benchmarks.vhd`

קובצי ה-benchmark וקובצי ה-hex הושוו למקור ולא שונו.

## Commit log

2026-08-12 Stage 3 implementation ready for ModelSim
    [SingleCycle_RV32IM_SignalTap.stp, stp1.stp]
2026-08-12 Add stage 5.5 hardware smoke test
2026-08-17 Fix divider unit compile order and save stage 2 evidence
2026-08-17 Fix divider stall and retirement integration
2026-08-17 Complete stage 3 verification
2026-08-17 Track saved ModelSim list evidence
2026-08-17 Implement timer and pushbutton stages
2026-08-17 Prepare hardware smoke test and interrupt stages
2026-08-26 Complete verification through FPGA stage 9
2026-08-27 Highlight board validation guide at repository root
2026-08-30 Finalize timer handling and Quartus Seed 2 configuration
    [lab6_interrupt_debug.stp]
2026-08-30 Finalize SignalTap naming and document Quartus Seed 2
    [RV32IMscMCU.stp]
